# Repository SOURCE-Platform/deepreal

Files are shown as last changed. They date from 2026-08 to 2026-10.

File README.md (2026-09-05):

# DeepReal

**Open-source trusted sensing for private AI.** The first SOURCE reference device.

> **Status: architecture + hardware design in progress.** DeepReal is in active architecture, hardware-design, and prototype-planning work. Nothing here is production-ready, and no sensor configuration is final.

System architecture: [Source of Truth v0.2](docs/system-architecture/system-architecture.md)

Current physical concept and visual BOM:
[Blender reference model](docs/design/blender-reference-model.md)

Project page: https://sourceovcourse.com/deepreal

---

## What DeepReal is

DeepReal is an open-source desktop sensing device and reference architecture designed to give AI systems authenticated, privacy-preserving observations of the physical world around a computer. It combines multimodal sensing, hardware-rooted device trust, encrypted transport, protected host-side processing, and verifiable outputs — designed to remain inspectable and user-controlled.

It is the first reference implementation of **SOURCE**, a broader open architecture for connecting trusted devices and physical-world observations to digital and AI systems with stronger guarantees about origin, integrity, and privacy.

## Two sensing systems

DeepReal is not one general-purpose camera. It has two sensing systems, each aimed at a specific physical domain:

- **Face / presence sensing** — short-range RGB + structured-light depth. Captures the person at the computer (RGB imagery, facial geometry, depth) to support presence, liveness, and future identity-related research.
- **Interaction sensing** — wide-angle RGB aimed at the workspace. Observes hands, fingers on the keyboard, and mouse interaction to build stronger evidence that a real human produced a given computer action.

## Trust architecture (intended)

Two sensing paths converge into one trusted pipeline:

Physical world → face/presence + interaction sensing → **device trust boundary** (secure boot, hardware root of trust, secure element, device credentials, sequence-aware capture) → authenticated + encrypted device–host channel → **host trust boundary** (Trusted Execution Environment, protected processing, local AI, attestation/proof logic) → **verifiable output** (attestations, selective disclosure, provenance).

Later layers (attestation formats, provenance) are part of the design, not yet implemented.

## Hardware configurations (under evaluation)

DeepReal is being developed through several reference configurations that trade cost against assurance. These are engineering configurations, not products for sale, and carry no prices here.

| Config | Face sensing | Interaction sensing | Research question |
|---|---|---|---|
| A — Cost optimized (baseline) | RGB + depth | Rolling-shutter RGB | Can a cost-optimized system reliably observe physical interaction? |
| B — Motion optimized | RGB + depth | Global-shutter RGB | Does cleaner fast-motion capture materially improve verification? |
| C — Full 3D interaction | RGB + depth | RGB + depth | Does 3D interaction geometry give substantially stronger evidence? |
| C+ — Full 3D + motion | RGB + depth | Global shutter + depth | What is achievable with maximum interaction evidence? |

## Prototype → production

Today's off-the-shelf modules are experimental instruments, not permanent dependencies:

Off-the-shelf modules → validate requirements → measure what actually helps → custom open reference hardware.

## Candidate components

Parts are candidates under evaluation, **not** final production specifications:

- **Face / depth module — Orbbec Astra Mini S Pro** *(prototype candidate).* Its short-range operating envelope suits someone sitting at a laptop. Final facial-identity performance must still be tested.
- **Secure-boot-capable MCU** *(under evaluation)*
- **Discrete secure element / hardware root of trust** *(under evaluation)*
- **Common architecture:** USB-C power and data, one microphone, device cryptographic identity, common PCB / interface architecture, authenticated communication with the host.

## Privacy by architecture

The design asks not only what *can* be sensed but what actually *needs* to be sensed — minimizing hardware sensing capability alongside retention and disclosure. Intended properties, under development: local / host-side processing, cloud inference not required, encrypted device–host link, data minimization, selective disclosure, user-controlled retention, and attestations that can expose less information than raw sensor streams. These are design goals, not finished guarantees.

## Roadmap

Discrete statuses — no completion percentages.

1. System architecture — **Current**
2. Mechanical + sensing design — **Current**
3. Sensor configuration evaluation — **Next**
4. Prototype electronics — **Next**
5. Trusted sensor pipeline — **Planned**
6. Protected host processing — **Planned**
7. Production reference architecture — **Planned**
8. SOURCE reference implementation — **Planned**

## Relationship to SOURCE

DeepReal provides the physical sensing endpoint; SOURCE is the broader open protocol and trust architecture (attestation + provenance) that applications and AI agents build on. The goal is an open architecture others can implement — future SOURCE-compatible hardware need not be built by the DeepReal project.

## Repository layout

```
deepreal/
├── blender/      # current design authority, generated scene and render tools
├── docs/         # architecture, visual BOM and research notes
├── references/   # retained component datasheets and vendor geometry
└── README.md
```

FreeCAD is not part of the active workflow. A future manufacturing-CAD phase
will reconstruct the selected Blender concept with tolerances and production
features after the component and validation gates are closed.

## Contributing

DeepReal is developed in the open. We are interested in collaboration around open hardware, embedded security, confidential computing, privacy-preserving AI, cryptography, and trustworthy sensing.

To get involved, open an issue or see the [project page](https://sourceovcourse.com/deepreal).

## License

Open-source licensing under final review.

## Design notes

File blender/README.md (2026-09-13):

# DeepReal Blender reference model

Blender contains the mechanical concept and presentation scenes. KiCad is the
authority for the main PCB footprint placement and copper geometry.
The canonical design is one curved 120 mm-wide assembly; the obsolete
"Current" collision study and boxy "Compact" comparison are no longer part of
the build. FreeCAD is not required.

The electronics are an incomplete engineering rebuild, **not approved for
website use**. The native KiCad import preserves the current placement defects;
it does not make the footprint selections, circuits or layout correct. The two
rotating head-board designs and flex interfaces remain unresolved concepts.
This model must not be used to manufacture or certify hardware.

See [the current implementation checkpoint](../docs/electrical/native-pcba-import-checkpoint.md)
for measured progress, reproducible commands and remaining blockers.

## Source files

- `design_spec.py` — Blender-native dimensions and the approved curved housing
  profile.
- `device.py` — hollow curved enclosure, drum and motor pockets, bounded side
  cable passages, and two cylindrical 24 × 54 mm drum shells.
- `optics.py` — bored apertures plus architecture-stage RGB, IR, projector,
  carrier, PCB, and optical keep-out geometry.
- `electronics.py` — native main-PCB import, concept shield and thermal stack.
  The missing KiCad tamper switch is no longer silently added in Blender.
- `motion.py` — two offset gearmotors, pinions, ring gears, axles, four
  bearings, encoder boards/magnets, brackets, and travel stops. Each ring gear
  occupies the final 2 mm drum-end band, clear of the outer camera window.
- `interconnect.py` — two combined 51-conductor optical-head flex routes;
  projector drivers and pulse loops remain local to the rotating heads.
- `support_hardware.py` — removable PCBA mounts, bearing carriers, grounded
  cable channels, boundary clamps, and strain relief.
- `presentation_views.py` and `pcba_presentation.py` — full-device views plus
  five dedicated PCBA scenes made from linked canonical geometry.
- `pcba_bom.py` — presentation names and explicitly representative envelopes
  for 18 missing native chip models; not an independent placement authority.
- `pcba_kicad_data.py` and `pcba_native_import.py` — hash-checked JSON/GLB
  interface from KiCad, including native components, pads, mask and holes.
- `mounting_stack.py`, `usb_port.py`, `usb_cable.py` — display attachment and
  external connection concepts.
- `build_scene.py` — deterministic complete-scene build.
- `validate_model.py` — legacy assembly checks; still fails missing required
  hardware and does not approve electronics.
- `validate_pcba.py`, `validate_pcba_native.py`, `test_pcba_native.py` — geometry
  transport and provenance checks, explicitly separate from engineering approval.
- `render_native_review.py` — six stamped internal review images; no publication.
- `review_renders.py` — legacy general-device review views, not a release gate.
- `render_pcba_public.py` — gated public packaging; currently refuses release.
- `deepreal.blend` and `renders/` — generated outputs; rebuild rather than
  treating manual edits as authoritative.

Handmade copper, decorative vias, fake connector-apron boards and the separate
Blender support-population generator are no longer active. Removed source is
recoverable from Git history. No traces have been invented to fill this board.

## Build and validate

From the repository root:

```sh
# Refresh the JSON and native GLB first; see the checkpoint for KiCad commands.
/Applications/Blender.app/Contents/MacOS/Blender --background \
  --factory-startup --python-exit-code 1 --python blender/build_scene.py

/Applications/Blender.app/Contents/MacOS/Blender --background \
  blender/deepreal.blend --python-exit-code 1 --python blender/validate_pcba.py

/Applications/Blender.app/Contents/MacOS/Blender --background \
  blender/deepreal.blend --python-exit-code 1 --python blender/test_pcba_native.py
```

The build uses millimetres in source and converts to Blender metres. Product
X runs across the display, Y runs front-to-back, and Z runs vertically.

## Enclosure and shielding decisions

- The electronics compartment follows the approved curved/tapered lower
  profile instead of a rectangular chin.
- The housing contains real drum, motor, electronics, and side-route cavities.
- A two-piece shield concept surrounds the main board. Actual connector,
  component, thermal-contact and tolerance clearances remain open.
- The head interfaces are two candidate combined flex connectors plus two
  motor/encoder interfaces. Their native placement currently overhangs the
  board incorrectly; no grounded connector apron has been implemented.
- Side cable passages are closely bounded, and data and power/motion routes
  remain in separate fitted channels.
- A separate copper spreader and compliant pad show the intended heat path
  from the rear tray into the rear housing surface. The spreader and pad sit
  behind the enclosure rather than inside the protected electronics chamber.

## Presentation scenes and navigation

The generated `.blend` opens to **00 Four View Overview**, where all four
versions are arranged together and labeled. You do not need to know Blender's
navigation to find them. For a larger individual view, use the scene selector
in the upper-right corner of Blender and choose a numbered detail
scenes. The canonical source scene is also retained for modeling work.

Presentation objects are linked duplicates: they have independent positions
for composition, but share the source mesh or curve datablock. Geometry is
modeled once and updates in every view.

0. **00 Four View Overview** — all four labeled arrangements on one canvas.
1. **01 Fully Assembled** — complete enclosed DeepReal hardware.
2. **02 Housing Removed** — enclosure and drum shells removed; mounting
   brackets, carriers, and standoffs remain. The enclosure-mounted USB-C
   receptacle and external cable are removed with the housing.
3. **03 Functional Core** — the same internals with removable support hardware
   omitted.
4. **04 Electronics Exploded** — the PCBA, tray, lid, components, thermal
   stack, connector banks, routes, and supports separated for inspection.
5. **05 Shield Cutaway** — the front lid removed to expose the shield
   boundary, populated field, connector apron, and cable passages.
6. **06 PCBA Top** — orthographic top/front assembly view.
7. **07 PCBA Bottom** — orthographic bottom/rear assembly view.
8. **08 PCBA Dimensioned** — board and populated-stack dimensions.
9. **09 PCBA Identification** — top/bottom reference-designator index.
10. **10 Camera Flex Study** — current two-connector drum interface beside the
    four-camera-flex signal-integrity fallback.

## What remains open

The model includes every architecture-level BOM function, but many items are
still reference envelopes. Production work still needs selected lenses,
projector and eye-safety hardware, final PCB layout, confirmed motor and
bearing parts, fastening/sealing details, flex fatigue data, thermal testing,
EMC testing, mass/hinge testing, and tolerance-driven CAD. Those unresolved
items are visible in the model and documentation rather than silently treated
as finished engineering.

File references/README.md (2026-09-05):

# Component references

Manufacturer datasheets and selected vendor geometry retained from earlier
feasibility research live here. They are evidence inputs, not the active
mechanical design. Blender remains the current geometry authority, and each
candidate must be rechecked before schematic or manufacturing freeze.

- `components/datasheets/` contains manufacturer documents and drawings.
- `components/cad/` contains selected vendor STEP/ZIP reference geometry.

The old project-authored FreeCAD models and scripts were intentionally removed.
Later production CAD should be reconstructed from the reviewed Blender concept
and verified component selections, not revived from the obsolete design.

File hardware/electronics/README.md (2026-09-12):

# DeepReal Electronics Design Source

This directory is the controlled handoff between the system architecture, future
EDA capture, PCB layout and Blender packaging model.

## Designs

- `deepreal-main-pcba/` - stationary 90 x 28 mm compute, power, camera bridge,
  USB and motor-control board.
- `deepreal-optical-head/` - one rotating RGB/IR/projector carrier design. The
  identical design is populated twice, once for each drum.

## What exists now

The files define the sheet hierarchy, component/reference-designator ownership,
named power and signal nets, drum-connector allocation, circuit intent and the
vendor pin maps that must be imported before an ERC-clean EDA schematic can be
claimed. KiCad 10 is installed and the main-board directory contains a navigable
15-page hierarchy plus a real 90 x 28 mm placement study. Several authoritative
BGA pin maps are still not stored locally.

This is electrical design source, but it is **not yet** a completed circuit
schematic, routed netlist or manufacturing package. `TBD_PINMAP` is an explicit
gate, never a guessed connection.

## Release rule

Blender geometry may use the component packages and support-population counts in
this directory. The separately named KiCad/Blender presentation derivative may use
shared illustrative copper labelled `ILLUSTRATIVE COPPER - NOT ELECTRICALLY
ROUTED`. The canonical KiCad board must remain free of decorative copper.

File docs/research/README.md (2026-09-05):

# Retained research

This directory separates historical evidence from the current design baseline.

- `component-sources-legacy.md` preserves vendor-source findings.
- `drum-internals-feasibility-legacy.md` preserves the earlier geometry study
  and clearly marks its removed FreeCAD dependencies.
- `legacy-layouts/` contains the study's generated diagrams.
- `DeepReal_System_Architecture_v0.1_historical.docx` is retained only as the
  superseded Word snapshot; v0.2 in `docs/system-architecture/` is current.

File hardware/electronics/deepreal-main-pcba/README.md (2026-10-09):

# DeepReal Main PCBA Electrical Capture v0.2

| Field | Value |
| --- | --- |
| Board | Main PCBA |
| Target outline | 90 x 28 x 1.6 mm |
| Assembly | Two-sided, 10-layer HDI working assumption |
| KiCad | 10.0.6 project created and verified |
| Schematic | 15-page hierarchy and page contracts; circuits not yet captured |
| PCB | 90 x 28 mm, 10-layer preliminary placement; canonical board has no routed copper |
| Public visualization | Not generated; publication paused |
| Status | Engineering rebuild in progress; electrical capture and routing not complete |
| Architecture baseline | `../../../docs/electrical/main-pcba-schematic-entry-spec-v0.1.md` |

The active rebuild plan is
`../../../docs/electrical/main-pcba-engineering-review-plan-v0.1.md`; requirements
v0.2 and `design-status.json` supersede older release and FPGA assumptions.

For the plain-language status, solved issues, blockers and next steps, see
[PCB progress, 14 September](../../../docs/electrical/pcb-progress-2026-09-14.md).

## Current KiCad artifacts

- `deepreal-main-pcba.kicad_pro` - KiCad project settings.
- `deepreal-main-pcba.kicad_sch` plus pages `02` through `15` - navigable
  schematic hierarchy. Each page states its references and closure gate.
- `deepreal-main-pcba-capture-map.pdf` - verified 15-page review export.
- `deepreal-main-pcba.kicad_pcb` - canonical engineering board. Its present
  contents are the inherited placement study, but future placement and copper
  edits originate only in KiCad.
- `design-status.json` - authoritative gate state and release permissions.
- `component-evidence.csv` - exact-source and footprint audit register.
- `source-evidence-register.csv` - versioned official-source locations and the
  specific gate each source can close.
- `change-register.csv` - architecture and geometry changes plus required reruns.
- `preliminary-stackup.json` - unapproved ten-layer intent model with every
  fabricator-dependent field left explicitly open.
- `engineering-layout-export.json` - canonical geometry and pad/copper export for
  Blender; the current baseline contains 238 components and 2,313 pads but no
  routing.
- `engineering-review-manifest.json` - generated evidence, blocker, and release
  inventory for the current review checkpoint.
- `public-assets.json` - publication lock and the names reserved for future
  KiCad-derived output. No current PCBA image is approved for publication.
- `scripts/generate_schematic_hierarchy.py` - deterministic hierarchy generator.
- `scripts/export_kicad_design.py` - exports canonical KiCad geometry for Blender.
- `scripts/validate_design_gates.py` and the other validators - enforce release,
  evidence, completeness, bandwidth, and no-fabrication rules.

The inherited placement contains 238 footprints: most registered major packages,
U21/U22, six camera-interface ESD arrays, nine power-inductor envelopes, 144
capacitor proxies, and 44 resistor proxies. SW1 is registered but missing from the
KiCad board. Several other footprints are known substitutes. Unconnected support
parts are space claims, not finished circuit values.

## Capture sequence

1. Import manufacturer symbols and footprints listed in `pinmap-gates.csv`.
2. Capture pages 2-4 and 13-15 from `circuit-specification.md` first.
3. Apply the net names and ownership in `net-registry.csv`.
4. Capture pages 5-12 after their vendor/tool gates close.
5. Annotate, run ERC and export an independently reviewed PDF and netlist.
6. Perform the Lattice pin compile and NXP DDR-tool pass before placement is
   treated as routeable.

Regenerate the hierarchy with:

```sh
python3 scripts/generate_schematic_hierarchy.py
```

The superseded visual board, handmade trace contract, generators, and renders were
removed from the working tree. Git history is the historical record. Future Blender
geometry must come from the canonical routed KiCad review draft instead.

The active Blender build imports KiCad's native GLB through
`../../../blender/pcba_native_import.py`, with a hash-checked JSON inventory.
`../../../blender/pcba_bom.py` supplies presentation names and flagged body
envelopes for missing 3D models, never fallback placement or invented pads.
The native board remains unrouted and its footprint selections are unverified.
See [the import checkpoint](../../../docs/electrical/native-pcba-import-checkpoint.md)
for reproduction commands and the current internal-review asset inventory.

The [two-drum interface checkpoint](../../../docs/electrical/head-interface-checkpoint-2026-09-14.md)
records official connector dimensions, read-only rotation trials, the head current
screen and remaining flex/head-board work. `head-interface-evidence.json` pins the
manufacturer catalog and lists open closure evidence. Run
`python3 scripts/validate_flex_interface.py` for an honest audit, or add
`--require-ready` to reject the currently unapproved interface. The comparison
image is an internal diagnostic, not an approved replacement layout.

`scripts/audit_head_power.py` checks the partial sensor power evidence and matching
IR clock contracts. It rejects the old shared 24 MHz assumption; the Mira220
reference is 38.4 MHz. Clock circuitry and complete head power remain open.

Public rendering is intentionally blocked until `public_visual_allowed` becomes
true after the engineering and visual gates pass. At that future point, rebuild with:

```sh
/Applications/Blender.app/Contents/MacOS/Blender --background \
  blender/deepreal.blend --python-exit-code 1 --python blender/render_pcba_public.py
```

## Non-negotiable rules

- U1 and U4 package bodies cannot touch; keep a physical assembly gap and preserve
  an unobstructed DDR corridor.
- Under the inherited two-FPGA candidate, U2 serves J2 and U3 serves J3, each with
  its associated i.MX95 CSI receiver. This is not a locked architecture: G3 must
  decide zero/one/two FPGAs before final placement and routing.
- Projector pulse drivers are not on this board. They are on the optical heads.
- `HEAD_*_3V3` is filtered and independently switchable for each head.
- `MOTOR_6V` remains disabled unless the accepted USB-PD contract is at least 9 V.
- Every projector-enable path is hardware-default-off and interrupted by the local
  lens-integrity loop.
- No PCBA image may be used for new marketing or investor materials until the
  replacement passes G11. Its caption is controlled by `public-assets.json`.

## Current completion definition

This package preserves the KiCad project structure and preliminary placement while
the engineering review draft is rebuilt. It does not close circuit or manufacturing
routing work.
Pin-level closure remains blocked where the official i.MX95, LPDDR4X, eMMC or FPGA
package data has not been imported and verified. See `pinmap-gates.csv` for the
exact blockers.

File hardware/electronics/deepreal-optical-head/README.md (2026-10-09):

# DeepReal Optical Head Electrical Capture v0.1

| Field | Value |
| --- | --- |
| Design | One reusable rotating optical-head carrier |
| Product quantity | 2 identical assemblies |
| Contains | RGB sensor assembly, IR sensor, projector, driver, local rails and safety interlock |
| Status | Capture source; optical, flex, safety and exact regulator selections open |

The two drums do not use two independently designed head PCBs. H1 and H2 are the
same controlled design populated twice, with identity/configuration selecting face
or interaction use. This reduces layout, firmware and test divergence.
The current RGB optical target populates standard SA31VA30P in the face head and
wide SA36VA30P in the interaction head. One shared carrier is still an objective,
subject to verifying both variants' mating connector, pinout, autofocus load and
the larger interaction lens clearance before schematic/layout freeze.

This is the intended partition, not an existing completed pair of PCBs. No native
KiCad head schematic or board has been captured yet. Main-board J2 goes to the
face head's J1; J3 goes to the interaction head's J1. See the
[two-drum interface checkpoint](../../../docs/electrical/head-interface-checkpoint-2026-09-14.md)
for connector dimensions, placement conflicts, power and dynamic-flex blockers.

`power-clock-evidence.json` records the inspected Mira220 clock, rail peaks and
startup requirements without claiming a complete head budget. Run the main-board
`scripts/audit_head_power.py` for source and clock-contract consistency checks.

## Electrical partition

The head receives filtered/switched 3.3 V, MCLKs, control and triggers over the
51-contact dynamic flex. RGB and IR each return two-lane CSI-2. The AS1170,
Belago1.2 and projector pulse capacitor stay local so the 700 mA-class pulse loop
does not traverse the rotating flex.

## Safety rule

`PROJECTOR_ENABLE` is necessary but not sufficient for emission. The driver must
also see a valid local lens-integrity loop, valid local power and no thermal/fault
condition. Removal of power, an open flex or an open Sense1/Sense2 loop defaults to
off. This is a design intent pending the required system-level eye-safety assessment.

## Closure order

1. Freeze the RGB assembly and Mira220 orientation from the optical baseline.
2. Select and calculate the RGB and IR local regulators.
3. Capture the manufacturer reference circuits and full sensor pin maps.
4. Freeze the 51-contact flex numbering and dynamic-flex stack-up.
5. Run ERC, power-up sequencing review and projector single-fault review.
6. In a separately authorized future fabrication program, prototype one head and
   measure rails, timing, thermal behavior and optical output. No fabrication is
   authorized by this digital-review phase.

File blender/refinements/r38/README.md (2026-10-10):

# R38 exterior mount and cable appearance

R38 starts from R36, preserving its drums, supports, and exposed-top
silhouette. The narrow R30 40 × 13 mm housing-colored pad is absorbed into a
continuous inner enclosure leg, extended to Y = 3.5 mm across the device.
A distinct satin-metal **112 × 26 mm** device-side magnetic face, centered at
Z = −14 mm, sits directly on that leg. It matches the R32 laptop-side target
plate in width, height and position. There is no separate mount riser. The
provisional 0.9 mm face, 0.35 mm air gap, 0.35 mm laptop plate and 0.40 mm
tape keep the R30 nominal mount plane; the ledge depth is now 5.0 mm at its
inner leg rather than 7.0 mm.

The USB cable's visual outer diameter changes from 4.0 to 3.2 mm. The plug
has a longer hard molded handle with a rounded V-taper, a subtle vertical
DeepReal wordmark, then a **distinct, straight-sided sleeve**
over the cable jacket. The sleeve reads as a separate piece rather than the
entire handle narrowing to cable diameter. The website viewer fades the free
end; the Blender cable itself has no physical fade.

Neither the sleeve's retention/bend performance, cable specification nor
magnetic force, material, embedding, adhesive, hinge load, enclosure
wall/volume changes, tolerances and laptop fit have been validated. The
magnetic face has a dark satin finish for visual distinction; that finish
does not establish the magnet's physical material or construction.

Build and export from the DeepReal repository root:

```sh
blender -b -t 4 --python-exit-code 1 --python blender/refinements/r38/build_r38.py
blender -b -t 4 --python-exit-code 1 --python blender/refinements/r38/render_plug_r38.py
blender -b -t 4 blender/refinements/r38/deepreal-exterior-mount-r38.blend \
  --python-exit-code 1 --python blender/export_web_exterior.py
```

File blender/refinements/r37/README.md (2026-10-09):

# R37 rear cable space reservation

R37 continues the [R36 inner-bearing study](../r36/README.md). The orange
volume in the [internal view](r37-rear-volume-internal.png) is a possible
passage through the center divider. The cyan volume is a possible chamber
inside the rear enclosure. They are **space reservations**, not cavities,
cable solids, or a working cable route. The public exterior is unchanged.

The passage spans X −0.8 to 1.2 mm, Y −1.7 to 13.25 mm, and Z 11.5 to
28.5 mm. The chamber spans X −26 to −0.2 mm, Y 13 to 20 mm, and Z 10.5 to
28.5 mm. These sizes test where room might exist; they are not bend-radius
requirements or approved wall dimensions.

## Finding

The passage crosses the current fixed **rear bearing support web** (four
surface triangle contacts). All 27 interior points sampled in the passage
are inside the solid R30 visual enclosure. In the rear chamber, 26 of 27
sampled points are also inside the solid enclosure. The remaining point,
at X −13.1, Y 18.6, Z 24.9 mm, lies outside the curved rear skin; a
rectangular cut there would break through the exterior. The test found no
contacts with the optical carrier, motor, or drums at the straight-ahead
pose. This is an occupancy study; a surface-only collision test would have
missed a volume fully contained by the shell.

The R36 moving cable exits along X with its 15.6 mm mating-end width along
Z. Sending it toward the rear (+Y) would require an **edgewise turn** of
that flat strip. Simply hollowing the indicated chamber does not make a
working dynamic cable. The fixed bearing web would also lose its present
attachment if the passage were cut as drawn. A replacement bearing load
path, a realizable flex orientation and loop, and a fixed electrical
termination need to be designed together before altering the enclosure.

There is a size problem as well. Würth Elektronik's
[dynamic-flex application example](https://www.we-online.com/files/pdf1/webinar-rigidflex-flexibility-cbt-en.pdf)
lists an inside bend radius **greater than 12 mm** for its roughly 120 µm,
single-layer flex. A 180° return at that radius needs over 24 mm across.
This proposed chamber is only 7 mm deep (Y) and 18 mm high (Z). It therefore
cannot house that example loop in either of those directions. This is a
supplier illustration, not a selected DeepReal stack or a universal limit;
the actual motion and cable vendor must determine the necessary space.

Würth Elektronik's [Flex Solutions design guide](https://www.we-online.com/files/pdf1/design-guide-flex-solutions-cbt-en.pdf)
calls for specifying the actual dynamic stack, bend shape, radius, frequency,
and cycle count early in the mechanical/electrical design. Its guide also
notes that dynamic flex often favors a single layer in the bending area.
That guidance is a reason to involve the cable fabricator, not a validation
of this reservation. The 0.2 mm in the R36 straight visualization is not a
validated dynamic stack thickness.

## Next design action

Redesign the moving cable and inner bearing support as one module. Compare
a loop that bends across the flex's thin dimension with alternative
head-board/connector locations, then screen the full face-drum −45° to +45°
sweep. Only after a route clears the optical carrier, motor, supports,
enclosure and both drum end rings should the chamber be cut into the shell.
Check the interaction drum separately with its own travel limits. Vendor
review must establish flex stack, impedance, strain relief and cycle life.

## Reproduce

```sh
blender -b -t 4 --python blender/refinements/r37/study_r37.py
```

Outputs: editable `deepreal-rear-cable-volume-r37.blend`, internal view,
and `r37-volume-check.json` with bounds and occupancy results.

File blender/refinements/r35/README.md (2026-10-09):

# R35 face-drum motion feasibility study

R35 follows [R34](../r34/README.md). It studies the two remaining face-drum
interfaces: how the outer axle reaches the drum wall, and how a moving optical
cable might reach the fixed center divider. This is **not** a release model.

The [R36 study](../r36/README.md) replaces the obstructing fixed-bearing tabs
with an axial neck and side supports. Its straight cable segment clears the
sampled poses; the moving service loop is still open.

## Outer end: a geometric load path exists

The new rotating disk/web overlaps the shaft, the rotating hub and a thin
sleeve at the drum sidewall. The sleeve also overlaps the rotating drum shell.
Together these envelopes show a continuous *intended* load path from drum wall
to shaft, while the stationary bearing stays separate. The sweep script finds
zero triangle intersections between these rotating envelopes and the fixed
bearing or enclosure at the rest pose. The web has only 0.3 mm **nominal axial**
space to the fixed bearing. That is a packaging observation, not a tolerance
or strength allowance. Separate meshes deliberately overlap where joints
would be needed; fits, fasteners, bearing retention and loads remain unproven.

## Inner end: the full-width twist route fails this layout

The red ribbon represents the existing 15.6 mm connector-end width at 0.2 mm
illustrative thickness. It twists from a rotating anchor to a fixed anchor.
`check_r35.py` tests four moving-anchor positions and two fixed-anchor
positions at 5° increments over −45° to +45°. **None of the eight candidate
routes clears the modeled parts.**

- The R21 upper/lower fixed-bearing webs and tabs intersect the ribbon at
  every pose, even when the fixed end stops before the enclosure.
- When the fixed end reaches into the center divider, the current enclosure
  intersects the ribbon at every pose; no fixed cable opening exists there.
- Longer torsion spans cross the moving optical carrier and, at some angles,
  the RGB or projector body. Shortening the span reduces those collisions but
  leaves the fixed support conflict and offers very little length for twist.

This corrects an easy overreading of R34: its 0.65 mm figure measured the
straight strip *inside the circular bearing opening*. R34 did not demonstrate
a routed moving cable past the bearing supports, optical payload and divider.
The R35 collision study does not prove every possible flex geometry fails; it
shows that a simple full-width axial twist cannot be dropped into this layout.
No bend-radius, copper-strain or life model has been claimed.

## Review artifacts

- `deepreal-face-motion-study-r35.blend`: editable study, with the failed
  cable candidate visibly red.
- `r35-outer-load-path.png`: isolated rotating web, hub, shaft and bearing.
- `r35-flex-center-conflict.png` and `r35-flex-up45-conflict.png`: internal
  conflict views. The drum shell is hidden so the contacts are visible.
- `r35-motion-check.json`: all sampled triangle-intersection results.
- `r35-motion-manifest.json`: objects and provisional anchor locations.

Regenerate from the repository root with Blender 5.2:

```sh
blender -b -t 4 --python blender/refinements/r35/build_r35.py
blender -b -t 4 --python blender/refinements/r35/check_r35.py
blender -b -t 4 --python blender/refinements/r35/render_r35.py
```

## Next design pass

1. Rebuild the fixed inner-bearing supports around an intentional cable
   window and add a protected path through the center divider.
2. Change the moving cable architecture or optical-carrier layout so the
   required contacts can traverse that window through the full face-drum
   travel. Candidate directions include a split harness from the head PCBA
   or a packaged flex loop; neither has been validated yet.
3. Re-sweep the exact new cable envelope, then check termination, minimum
   bend radius, strain relief, signal integrity and cycle life.
4. Turn the outer web overlaps into a specified rotating joint with selected
   bearing, loads, fastening and tolerances.

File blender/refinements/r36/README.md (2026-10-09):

# R36 inner-bearing cable window study

R36 continues the [R35 motion study](../r35/README.md). It keeps the exposed
drum exterior and the R35 outer-shaft web. This revision changes only the
**face drum's fixed inner-bearing support**; the interaction drum is unchanged.

## What changed

The R21 upper and lower bearing tabs crossed a full-width cable even at the
straight-ahead pose. R36 replaces them with a thin fixed **axial neck** that
extends toward the center divider beyond the rotating inner lip. Two short
side webs connect that neck to the enclosure from the left and right of the
cable opening. The moving straight strip remains 15.6 mm wide, matching the
documented connector-end width.

The R36 model's sampled −45° to +45° face-drum sweep, every 5°, records:

- Intended mesh contacts from each side web to the axial neck and enclosure,
  and from the neck to the fixed bearing envelope.
- Zero mesh intersections of the new fixed supports with the rotating inner
  race, rotating lip or drum shell.
- Zero mesh intersections of the **straight** full-width exit segment with
  the modeled bearing, supports, motor, housing, drum shell and optical
  carriers at those sampled poses.

The neck's nominal outer radius is 8.9 mm, while the rotating lip's nominal
inner radius is 9.15 mm: just 0.25 mm radial space before tolerances. The
flex's corner radius is about 7.8 mm inside an 8.45 mm bore. These are
packaging measurements, not bearing or cable clearances approved for manufacture.

## What still blocks a moving cable

The straight strip stops before it connects to a fixed harness. The R35
full-width axial-twist route still crosses the optical carrier. As a separate
screen, `probe_r36.py` tested 6–8 mm trunk widths at three moving-anchor
positions. `probe_offset_r36.py` tested 6 and 7 mm trunks with up to 3 mm of
offset toward the motor. **None of these simple twist routes was collision
free.** Width reduction cleared the old bearing tabs, but did not resolve the
carrier conflict; moving the strip toward the motor traded carrier contacts
for motor contacts. `map_conflict_r36.py` localizes representative contacts
along the inner optical carrier rather than assuming a small end relief would
fix them.

The 15.6 mm number is the **mating end width** of the 51-contact connector.
It does not approve a narrower dynamic trunk, a multilayer flex, split tails
or changes to the six differential-pair routes. Those need a real electrical
stack-up and signal-integrity review before selection.

The next mechanical study should reserve a service-loop chamber outside the
current optical-carrier and motor envelopes, with a protected route through
the fixed center divider. It must retain bearing support and the visible
exterior. Then a cable vendor or electrical designer must validate bend
radius, copper strain, terminations, impedance and cycle life.

## Files and reproduction

- `deepreal-inner-bearing-window-r36.blend`: editable support study.
- `r36-bearing-window-end.png` and `r36-bearing-window-side.png`: internal
  support views with the drum skin hidden.
- `r36-support-check.json`: sampled fixed/moving geometry checks.
- `r36-width-screen.json` and `r36-offset-screen.json`: exploratory moving
  cable screens against the unchanged R35 carrier and motor layout.
- `r36-support-manifest.json`: changed objects and remaining open work.

Run from the repository root with Blender 5.2:

```sh
blender -b -t 4 --python blender/refinements/r36/probe_r36.py
blender -b -t 4 --python blender/refinements/r36/probe_offset_r36.py
blender -b -t 4 --python blender/refinements/r36/map_conflict_r36.py
blender -b -t 4 --python blender/refinements/r36/build_r36.py
blender -b -t 4 --python blender/refinements/r36/check_r36.py
blender -b -t 4 --python blender/refinements/r36/render_r36.py
```

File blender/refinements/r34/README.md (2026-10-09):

# R34 face-drum interface study

This Blender revision tests one packaging direction against the R30 exterior:
a centered angle encoder at the **outer cheek** and an optical flex exit through
the **inner bearing**. It changes only the face drum. The interaction drum
retains its R30/R21 interface.

The [R35 motion study](../r35/README.md) extends this check and finds that a
full-width moving twist collides with the existing bearing supports and optical
carrier. Treat the straight-aperture result below as a limited check.

## Files

- `deepreal-face-interface-study-r34.blend` is the editable assembly study.
- `r34-mechanism-study.png`, `r34-outer-encoder-detail.png` and
  `r34-inner-flex-detail.png` are internal review views. The enclosure and
  drum skin are hidden in these views to reveal the interfaces.
- `r34-interface-manifest.json` records the placed envelopes and open items.
- `r34-interface-check.json` records the current geometric sweep.
- `build_r34.py`, `check_r34.py` and `render_r34.py` reproduce those artifacts
  from the R30 model using Blender 5.2.

Run the scripts in build, check, render order from the repository root:

```sh
blender -b -t 4 --python blender/refinements/r34/build_r34.py
blender -b -t 4 --python blender/refinements/r34/check_r34.py
blender -b -t 4 --python blender/refinements/r34/render_r34.py
```

## What this pass establishes

The moving magnet and stationary sensor-package proxies share the face-drum
axis. Their modeled axial surface gap is 0.55 mm. The sensor board sits in an
internal pocket in the fixed outer cheek; the exterior cheek remains skinned.
The magnet is a Ø6 × 2.5 mm **reference envelope**, not a selected magnet.
The [AS5600L adapter-board guide](https://look.ams-osram.com/m/b03a90ea3dea434a/original/AS5600L_UG000345_2-00.pdf)
gives 0.5–3 mm for its reference magnet setup;
field strength, datum and errors for this assembly have not been measured.

The inner flex strip uses the documented 15.6 mm connector-end width from
`head-interface-evidence.json`. A clearance slot is cut through the inherited
solid drum cap. At sampled face-drum angles from −45° to +45° in 5° steps,
the straight strip has zero triangle intersections with the fixed inner bearing,
motor, motor bracket, housing and drum shell. At zero it also has zero triangle
intersections with the modeled optical carrier, head PCBA carrier, RGB/IR/
projector bodies and rotating inner bearing. The strip's maximum corner radius
is 7.80 mm against an 8.45 mm fixed-bearing opening radius: approximately
0.65 mm **nominal radial** margin. This is a geometry check, with no tolerance
or manufacturing allowance.

## Open before the mechanism can be released

1. Design and sweep the **deforming flex service loop** between the rotating
   head and fixed divider; select flex construction, end terminations, strain
   relief, minimum bend radius and cycle-life target. The current strip ends
   before that transition.
2. Connect the outer rotating shaft structurally to the rotating hub and drum.
   The bearing, shaft and hub are envelopes, with no load or fastener design.
3. Redesign the outer cheek pocket with a validated wall and board mount. The
   study leaves a very thin outer skin solely to preserve exterior appearance.
4. Validate the magnet, sensor datum, polarity, air gap across tolerances,
   motor-field interference and stationary electrical harness.
5. Reconcile the second drum, motor drive, hard stops and assembly sequence.

The present `straight_envelope_pass` field describes only the tested straight
segment and static overlaps. It does not indicate that a moving cable or
manufacturable bearing assembly passes.

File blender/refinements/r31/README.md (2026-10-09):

# R31 decorative laptop target plate

Open `deepreal-logo-mount-plate-review-r31.blend`. Its saved camera faces the
back of the laptop lid, with DeepReal removed so the plate and logo are visible.
The existing R30 device and enclosure files are unchanged.

The visual study uses the supplied `assets/deepreal-logo-v0.svg` on a 110 × 16 mm
steel target near the lid's top edge. A separate 106 × 14 × 0.4 mm foam sticker
sits between the plate and the 3 mm laptop-lid proxy. The steel target is shown
as 0.35 mm thick to match the earlier provisional mounting stack. Its grade,
thickness, attachment strength, and laptop fit remain unverified.

The logo is a dark laser-mark appearance made from the SVG curves. It is **not**
a fabrication-ready engraved or debossed cut: physical recess depth and minimum
line width need a manufacturing sample. A 430 ferritic stainless finish is a
material candidate, represented here by a satin steel shader.

- `r31-laptop-back.png`: saved rear-view camera and overall placement.
- `r31-full-width-plate.png`: closer view of the plate across the attachment zone.
- `r31-logo-and-foam-detail.png`: angled logo and plate-edge view.
- `r31-attachment-layers-exploded.png`: illustration with the plate lifted from
  the foam sticker; this is a render pose, not the assembled file state.
- `build_mount_plate.py`: repeatable Blender build and render script.

This file reviews the laptop-side target only. The R30 device-side 40 mm magnet
pad has not yet been updated to match the wider attachment concept.

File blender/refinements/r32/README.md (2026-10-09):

# DeepReal pressed logo target plate — R32

This separate Blender appearance study replaces the R31 dark surface mark
with actual shallow relief on a taller laptop-side magnetic target plate.

- Plate: 112 × 26 × 0.35 mm, centered at z = −14 mm below the laptop top.
- Foam sticker: 109 × 23 × 0.4 mm. The original R30 device-side magnet pad
  remains its earlier size; magnetic holding force has not been checked here.
- Artwork: original DeepReal SVG sampled to 103 mm wide. Each logo line is
  the bottom of a 0.15 mm deep trough with a 0.95 mm smooth shoulder.
- The plate back remains flat in this visual model. Material forming, tooling,
  local thickness, adhesive stack, and pull force require a physical prototype.

Build with:

```sh
/opt/homebrew/bin/blender -b --python blender/refinements/r32/build_pressed_plate.py
```

The saved file opens on the plate detail camera. The PNG renders show the
larger plate on a laptop lid and the light/shadow behavior of the logo.

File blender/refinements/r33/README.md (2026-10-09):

# DeepReal creased press profile — R33

This is the requested profile revision of the R32 laptop target plate. The
plate and logo dimensions remain 112 × 26 mm and 103 mm wide, respectively.
The 0.15 mm pressed depth and 0.95 mm shoulder radius also remain the same.

The logo line is now a narrow crease at the deepest point. The shoulder
curves return smoothly to the original plate height. The R32 rounded-bottom
comparison is preserved in its own `.blend` and renders.

Build with:

```sh
/opt/homebrew/bin/blender -b --python blender/refinements/r33/build_creased_plate.py
```

This models the intended appearance, not the tool or forming behavior of a
specific steel stock. Production depth and crease radius need prototyping.

## Material direction

The appearance study uses satin 430 ferritic stainless steel (EN 1.4016).
The grade is magnetizable and supplied as cold-rolled sheet. A forming grade
such as Aperam K30ED is another candidate for pressed artwork. The 0.35 mm
sheet and 0.15 mm modeled crease are provisional; a physical sample must
check forming, flatness, adhesive contact, finish, corrosion, and magnetic
holding force.

- [Outokumpu Moda range datasheet](https://www.outokumpu.com/-/media/files/products/moda/outokumpu-moda-range-datasheet.pdf)
- [Aperam K30/K30ED technical sheet](https://www.aperam.com/sites/default/files/documents/FT_K30-K30ED_en_web.pdf)

## Moving-light study

`animate_sheen.py` loads the saved R33 Blender file and animates a strip
light across the logo. The script produces PNG frames in `sheen-frames/`;
`r33-moving-sheen.mp4` is the cropped, three-second H.264 review export.
`deepreal-creased-logo-light-sweep-r33.blend` has the editable light
keyframes. The material shader is an illustrative satin finish, not a measured
sample of a particular supplier's sheet.

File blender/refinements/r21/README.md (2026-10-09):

# R21 side-supported drum concept

This revision studies the user's three-support layout: one fixed center
divider and one removable support at each outside end. The rear-entry arms
from the earlier concept are absent. The top of both drums is exposed. The
old rear access cuts and covers are replaced with continuous shells. The
intended assembly path is through the inner drum ends, but the inherited
shell's solid end cap has not yet been cut away under the provisional lip.

## Files

- `deepreal-side-supported-drums-r21.blend` is the editable Blender concept.
- `r21-exterior-preview.png` and `r21-front-preview.png` are review images.
- `renders/` contains additional above, travel-pose, mechanism, and drive
  views generated by `render_r21.py` (the directory is ignored by Git).
- `r21-assembly-manifest.json` lists the new parts and removed proxies.
- `r21-clearance-check.json` records sampled mesh intersections.

## Mechanism shown

Each drum is supported by a large inner bearing envelope attached to the
center divider through two recessed webs, and a smaller outer bearing and
hollow spindle at its outside cheek. A stationary motor near the center
drives a rotating internal ring gear through a pinion. A magnet on the drum
passes a fixed encoder board near the outer cheek. A moving flex proxy meets
a fixed harness at the hollow outer spindle. The drums have a 5 mm shell-end
gap, occupied in part by the 3 mm center support and its fairing.

The sampled directions are face 45° up, forward, 45° down and interaction
forward, 22.5° down, 45° down. The high, middle, and low renders show those
paired poses from above. These are review poses, not proven travel limits.
The saved render has the face drum forward and interaction drum 45° down.

## Engineering status

This is a packaging and appearance study, not a fabrication drawing. The
sampled moving shells, end parts, and races have no triangle intersections
with the fixed supports and drive envelopes at the listed poses. The check
does not certify minimum clearances, bearing loads, gear teeth, motor torque,
hard stops, wire bend life, thermal behavior, fastening, or assembly access.
The encoder board recess and mount are also schematic.

The R20 wide interaction lens and board envelopes still intersect the old
optical carrier. Their mount and the front window need a separate redesign
before a mechanically accurate or website-ready render. The exterior review
images show the design direction; materials and lighting are provisional.
The separate inner lip originally shared the old shell's outer surface with
different tessellation, producing stepped viewport marks. It is now inset
0.06 mm to prevent that display artifact. A real hollow shell and bearing
seat must still replace the overlapping concept meshes.

Regenerate from the repository root with:

```sh
blender -b -t 4 --python blender/refinements/r21/build_r21.py
blender -b -t 4 --python blender/refinements/r21/check_r21.py
blender -b -t 4 --python blender/refinements/r21/render_r21.py
```

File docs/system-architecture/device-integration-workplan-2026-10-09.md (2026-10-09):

# DeepReal device integration workplan — 9 October 2026

Status: engineering work order. The exterior study can support appearance review;
the internal hardware is still an unverified concept. This plan does not approve a
board, flex, actuator, optical output or fabrication release.

The first [measured drum-interface audit](../electrical/drum-interface-finding-2026-10-09.md)
found two geometry blockers: the encoder magnet/sensor envelopes sit 6 mm off
the rotation axis, and the specified optical flex end is 15.6 mm wide while
the modeled outer spindle bore is 2 mm. Resolve these together before treating
the R21 mechanism as a cable or encoder layout.

## Working assembly

The current exterior is the R30 housing with two exposed-top drums, fixed left
and right cheeks, a fixed center divider, and a monitor-top ledge. R21 supplies
the internal motion *envelopes*. One reusable optical-head electrical design is
intended to populate both drums, with different RGB assembly variants. These
pieces have not yet been reconciled into a buildable assembly.

```text
                            stationary housing and center divider
              ┌──────────────────────────────────────────────────┐
face drum     │ fixed motor/drive → rotating ring → drum          │
              │ inner bearing                       outer bearing │
              │ moving optical head → dynamic flex → fixed harness
              │ rotating magnet → fixed angle sensor at cheek    │
interaction   │ same mechanism; different optical population     │
drum          │ and separately chosen travel stops               │
              └──────────────────┬───────────────────────────────┘
                                 │ power, CSI, control, motor and angle wiring
                       main PCBA ↔ USB-C ↔ host
```

The outer cheeks and center divider should react bearing and motor loads into
the same housing. The moving optical flex must have its own controlled path and
life test; the motor and stationary angle sensor use fixed wiring to the main
board. A render showing these paths is not evidence of clearance or fatigue life.

| Interface | Drum or actuator side | Housing/main-board side | Current status |
| --- | --- | --- | --- |
| Drum support | Rotating inner ring and outer hub | Center-divider bearing seat and outer-cheek spindle | Envelopes only; bearing/coupling unselected |
| Drum drive | Internal ring gear attached to drum | Center-fed motor, bracket and pinion | Envelope only; torque, teeth and fastening open |
| Optical data and power | Reusable RGB/IR/projector head in each drum | Main-board J2/J3 through an outer-axis exit | 51-contact grouping exists; pinout, bend and current unapproved |
| Absolute drum angle | Magnet rotates with end face | Hall sensor/board at outer cheek | Physical location conflicts with main-board register |
| Motor position and power | Motor quadrature encoder and motor terminals | Main-board J4/J5 and U13/U14 | Harness concept exists; exact motor and connector pending |

## First integration conflict to close

R21 places each rotating encoder magnet next to a **stationary angle-sensor
board at the outer cheek**. The main-board component register still lists
U18/U19 AS5600L as **main-PCBA top-side components**, and the circuit plan
groups them with the motor harnesses. Those two physical locations cannot both
describe the same sensor. R21 also labels its Hall IC as unselected, so the
AS5600L choice and magnetic geometry need confirmation.

Preferred layout direction for evaluation: keep a small stationary sensor
daughterboard at each cheek, close to the rotating magnet; carry power,
ground and angle-data signals to the main PCBA by a fixed harness. This avoids
requiring the sensor to read a magnet across the device from the main board.
Before updating KiCad, verify sensor-to-magnet orientation, air gap, angular
error, cheek thickness, motor-field interference, address/voltage compatibility
and service access. Then move the physical U18/U19 placement ownership from the
main board to those cheek boards, or document a different proven geometry.
Keep the motor quadrature encoder separate from this absolute-angle function.

## Execution sequence and exit evidence

| Order | Work package | Deliverable that closes it |
| --- | --- | --- |
| 1 | Freeze one reference drum's physical interface | Coordinate drawing with center/outer bearing seats, fixed vs rotating parts, magnet and sensor datum, motor/pinion/ring coupling, head-board envelope, cable exit, hard stops and service clearances. Repeat with the second drum's optical and travel differences. |
| 2 | Prove motion and wiring envelopes | Selected bearing and motor candidates, torque/inertia/gear calculation, backlash target, full pose collision sweep, hard stops, moving-flex bend radius and cycle-life plan. Travel limits follow optical coverage and wire life; existing R21 poses are provisional. |
| 3 | Resolve stationary and moving interconnects | Numbered end-to-end 51-contact head flex; mating side and contact orientation; six camera differential pairs per head; power/return allocation; motor/quad harness and cheek sensor harness. Provide continuity drawing and current, voltage-drop, signal-integrity and fatigue review. |
| 4 | Complete head power, clocks and safety | Mode-specific RGB/IR load and startup budget, local conversion losses, projector capacitor recharge, 38.4 MHz Mira220 reference-clock implementation, power sequencing and hardware-default-off projector interlock. Then capture the reusable head schematic and outline. |
| 5 | Close compute and external connection | Compile one- versus two-FPGA alternatives on supported tools with legal pins/timing; define simultaneous capture and USB output/encoding policy; select a USB-C mating solution at the housing opening, including compatible board thickness and insertion support. |
| 6 | Design the actual main board | Audit exact parts and footprints, populate the functional KiCad sheets, run ERC, select stack-up, place from pin and enclosure constraints, prove critical routes, then complete routing/DRC, thermal and specialist review. Board size remains a candidate until this is done. |
| 7 | Prototype and validate | Bench one drum/head first: startup absolute-angle and quadrature correlation, motion under cable load, flex life, sensor/clock behavior, power transients, projector safety and thermal behavior. Integrate the second drum and full USB capture after the reference module passes. |

Packages 1, 3 and 4 can advance together. Package 5 can run in parallel once
its camera and mechanical connector assumptions are explicitly recorded.
Packages 6 and 7 depend on the interface and electrical evidence above.

## Next concrete engineering pass

The [R34 face-drum interface study](../../blender/refinements/r34/README.md)
now places a rotating magnet on the outer drum axis opposite a stationary
cheek-board envelope and passes a 15.6 mm straight flex envelope through the
inner bearing. Its sampled straight-segment sweep clears the current fixed
geometry. The study leaves the deforming service loop, shaft/hub coupling,
cheek wall, selected bearing and interaction drum unresolved; it is evidence
for packaging direction, not a fabrication-ready mechanism.

The follow-on [R35 motion study](../../blender/refinements/r35/README.md) adds
an outer rotating web from shaft and hub to drum wall. Its concept geometry
clears the fixed bearing and enclosure, but the joints and loads are open.
The moving cable route is blocked in the current package: all eight sampled
full-width axial-twist candidates intersect the existing bearing supports;
longer routes also intersect the optical carrier. The immediate integration
task is to redesign the inner bearing support and cable architecture together
before assigning a final drum flex or freezing the head-board connectors.

The [R36 bearing-window study](../../blender/refinements/r36/README.md)
resolves the first geometric obstruction at concept level: an axial fixed
bearing neck and side webs clear the rotating ring and straight 15.6 mm strip
over sampled face-drum poses. The service loop and fixed cable exit remain
unmodeled. A 6–8 mm trunk-width screen and offset screen did not find a
collision-free simple twist through the current optical-carrier layout, so
the next pass must reserve a separate moving-cable volume and verify the
electrical construction before changing the 51-contact interface.

The [R37 rear-space study](../../blender/refinements/r37/README.md) places a
test passage through the center divider and a test chamber within the rear
housing. The passage intersects the current rear bearing support web, while
the chamber is occupied by the solid visual enclosure. The cable also needs
a change of orientation to reach that chamber without bending edgewise.
These are volume reservations, not cutouts or a complete cable path. Design
the support, flex loop, and fixed termination together before cutting the
housing or treating the R37 view as an assembly solution.

1. Make a shared coordinate and connection drawing for **one drum** using the
   R30 housing and R21 motion envelopes. Mark every fixed support, rotating
   part, cable and board. Include the cheek angle-sensor board option.
2. Write the per-drum interface table from head connector to main board, plus
   separate motor/quad and angle-sensor harnesses. Number contacts only after
   checking both connector ends and flex orientation.
3. Reconcile the schematic/component register with that physical partition.
   Do not move U18/U19 in the PCB file until the cheek geometry and electrical
   interface are reviewed.
4. Run the full pose sweep with transparent housing and three views per pose:
   front, above and end-on. Inspect lens clearances, top opening, flex path,
   bearing support and wire exposure at both travel limits.

The monitor attachment and decorative plate remain a separate mount-validation
track: retention/release force, laptop hinge load, adhesive aging and the
selected magnet or clip mechanism. They do not set the internal PCB pinout.

## Evidence behind this work order

- `blender/refinements/r21/r21_mechanism.py`: bearing, motor, gear, magnet and
  flex envelopes; no selected hard stops or fatigue proof.
- `blender/refinements/r30/r30-mount-manifest.json`: current exterior/ledge study.
- `hardware/electronics/deepreal-main-pcba/component-register.csv` and
  `circuit-specification.md`: current U18/U19 and J4/J5 ownership.
- `hardware/electronics/deepreal-main-pcba/design-status.json`: G3/G4 blocked,
  G5 in progress, G6 blocked, routing not started.
- `docs/electrical/head-interface-checkpoint-2026-09-14.md`: 51-contact flex,
  connector orientation and current constraints.
- `docs/electrical/pcb-progress-2026-09-14.md`: board and circuit status.
- `docs/design/main-pcba-usb-mechanical-options-v0.1.md`: USB opening/port
  mismatch and board-thickness conflict.
- `docs/research/main-pcba-fpga-topology-study-v0.2.md`: topology decision gate.

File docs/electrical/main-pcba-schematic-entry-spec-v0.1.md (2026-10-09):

# DeepReal Main PCBA - Schematic Entry Specification v0.1

> **Superseded architecture note (13 September 2026):** Use this document as source
> evidence, not as permission to freeze two FPGAs or begin pin-driven layout. The
> authoritative requirements are in `main-pcba-engineering-requirements-v0.2.md`;
> FPGA count remains open in the v0.2 topology study until compile evidence exists.

| Field | Value |
| --- | --- |
| Date | 12 September 2026 |
| Status | Pre-schematic engineering baseline; not manufacturing-ready |
| Main board target | 90 x 28 x 1.6 mm, two-sided assembly |
| Populated envelope | Approximately 90 x 28 x 15 mm including shield/thermal stack |
| Purpose | Prevent the schematic and 3D model from being built on generic blocks |

> **Capture status (12 September 2026):** The tool-neutral schematic source package
> now exists at `../../hardware/electronics/`. It defines the 15 main-board sheets,
> the reusable optical-head design, reference ownership, named nets, connector groups
> and pin-map gates. A checked EDA schematic/netlist still requires vendor symbol
> import, FPGA pin compilation, the first DDR-tool pass and ERC.

## Outcome

The 90 x 28 mm main board remains plausible enough to continue, but it is not yet
proven. The architecture now has a credible schematic entry point and three material
changes from the current visual model:

1. Use two 6 x 6 mm LIFCL-17 camera bridges, one per drum, rather than one generic
   9.5 mm FPGA.
2. Use one 51-position high-speed flex connector per drum as the compact baseline,
   with the current four 22-position camera connectors retained as a lower-risk SI
   fallback.
3. Put each AS1170 projector driver, its inductor, pulse capacitor, local camera
   regulators and interlock circuit on a small rotating head carrier. These are
   internal product electronics, not external development boards. Shortening the
   projector pulse loop is more credible than sending the switched 700 mA pulse
   through the rotating flex.

The i.MX 95 and LPDDR packages must not touch. Their bodies need an assembly gap,
while the DDR routing must remain short. The final gap and relative orientation come
from BGA escape and DDR routing, not from visual preference.

### First board-space sanity check

- The raw projected area of all current main-board package and connector bodies in
  Mechanical BOM v0.2 is approximately 1,044 mm2. That is 41.4% of one 90 x 28 mm
  board face, before support passives, courtyards, routing and keep-outs.
- The board has two assembly faces, so package body area alone does not force a size
  increase. The controlling constraints are DDR escape, six MIPI corridors, USB,
  power-loop copper, flex access and the thermal contact zone.
- Two 51-position drum connectors occupy 31.2 mm of body length in total versus
  approximately 52 mm for the older four-connector concept.
- A 15 mm i.MX body, a 1.5 mm assembly gap and the 10 mm LPDDR body consume 26.5 mm
  along the long axis while staying about 15 mm deep. That geometry fits on paper;
  fan-out and length matching still decide whether it fits electrically.

This is enough evidence to keep 90 x 28 mm as the working target, but not enough to
claim that routing will close at that size.

## 1. Locked schematic baseline

| Function | Baseline part | Package / body | Confidence | Status |
| --- | --- | --- | ---: | --- |
| Application processor | NXP MIMX9596CVTXNAC | 548-ball FC-PBGA, 15 x 15 mm, 0.5 mm pitch | 85% | Exact industrial six-core 15 mm SKU |
| LPDDR4X | Micron MT53E1G32D2FW-046 AAT:B | 200-ball, 10 x 14.5 mm | 65% | 4 GB baseline; NXP DDR validation required |
| eMMC | Micron MTFC32GBCAQTC-AAT | 153-ball, 11.5 x 13 mm | 85% | 32 GB, eMMC 5.1 |
| Camera bridges | 2 x Lattice LIFCL-17, csfBGA121 | 6 x 6 mm, 0.5 mm pitch | 70% | Exact speed grade/order suffix after Radiant compile |
| Main PMIC | NXP MPF0900AVNA2ES | HVQFN56, 8 x 8 mm | 90% | Industrial QM OTP for i.MX 95 + LPDDR4X |
| SoC regulator | NXP MPF5302BVNAAEP | H-FC-PQFN24, 15 A class | 85% | VDD_SOC baseline |
| CPU regulator | NXP MPF5301BVNABEP | H-FC-PQFN24, 8 A class | 85% | VDD_ARM baseline |
| Protected 5 V buck | TI TPS56637RPAR | VQFN-HR10, 3 x 3 mm | 80% | 15 V to system rail; validate 5 V fallback dropout |
| Motor 6 V buck | TI TPS56637RPAR | VQFN-HR10, 3 x 3 mm | 75% | Enabled only when USB contract is at least 9 V |
| Input eFuse | TI TPS259472LRPWR | WQFN10, 2 x 2 mm | 80% | 23 V, reverse blocking, current monitoring |
| USB-PD sink | Infineon CYPD3177-24LQXQ | QFN24, 4 x 4 mm | 90% | 15 V / 3 A preferred contract |
| USB orientation mux | TI HD3SS3212IRKSR | VQFN20, 2.5 x 4.5 mm | 90% | Industrial USB SuperSpeed mux |
| Motor drivers | 2 x TI DRV8213RTER | WQFN16, 3 x 3 mm | 90% | Current sense/regulation and hardware stall detection |
| Motor | 2 x Pololu item 5137 | 6 V micro gearmotor | 90% electrical | 0.67 A theoretical stall each |
| Absolute drum angle | 2 x AS5600L-AWLM | WLCSP15, 2.07 x 2.63 x 0.6 mm | 70% | Programmable I2C addresses; supply-transition check required |
| Shared sensor clock buffer | TI LMK1C1104DQFR | WSON8, 2 x 2 mm | 75% | Four low-skew LVCMOS outputs |
| Board EEPROM | Microchip AT24C64D-MAHM-T | UDFN8, 2 x 3 mm | 90% | Non-secret board revision/calibration selection |
| Main board temperature | TI TMP117AIDRVR | WSON6, 2 x 2 mm | 90% | Place near i.MX thermal path |
| Digital microphone | TDK MMICT3902-00-012 | LGA, 3.5 x 2.65 mm | 90% | PDM, bottom port |
| Case tamper | Omron D3SK-B1R | Surface-mount NC switch, 3 x 3.5 x 0.9 mm | 70% | Exact lever direction still enclosure-dependent |
| Drum connector baseline | 2 x Hirose FH26W-51S-0.3SHW(97) | 51 pos, 15.6 x 3.2 x 1.0 mm | 65% | Dynamic-flex and SI validation required |
| RGB sensors | Face SA31VA30P; interaction SA36VA30P wide | Both 10.8 x 10.8 mm sensor assemblies | 70% electrical, optical fit open | Variant pinout and common head carrier to verify |
| IR sensors | 2 x ams OSRAM Mira220 Q65114A0087 | CSP, 5.4 x 5.4 x 0.74 mm | 80% | Located on head carrier |
| Projectors | 2 x ams OSRAM Belago1.2 Q65114A0198 | 4.2 x 3.6 x 3.325 mm | 75% | Located on head carrier |
| Projector drivers | 2 x ams OSRAM AS1170 Q65113A7129 | WLCSP13, 2.25 x 1.5 x 0.6 mm | 75% | Located on head carrier |

Exact orderable suffixes above are a purchasing baseline, not blanket approval for
production. Availability, lifecycle and alternates must be checked again at design
release.

## 2. Board partition

```text
USB-C
  |-- CC1/CC2 --> CYPD3177 PD sink
  |-- VBUS ----> eFuse ----> protected VBUS
  |                         |-- 5 V system buck --> PF09 + two PF53 --> i.MX95/DDR
  |                         |                    --> local FPGA rails
  |                         |                    --> two optical-head flexes
  |                         `-- 6 V motor buck --> two DRV8213 --> stationary motors
  `-- USB 3.x --> ESD --> orientation mux --> i.MX95 USB1

Main PCBA                 Face head carrier       Interaction head carrier
i.MX95 + memory           IMX708 assembly         IMX708 assembly
2 x LIFCL-17              Mira220                 Mira220
USB and power             AS1170 + Belago         AS1170 + Belago
motor drivers             local sensor rails      local sensor rails
clock/reset/control       local interlock         local interlock
```

The absolute drum-angle sensors should be stationary at the drum axes with their
magnets on the rotating shafts. They therefore do not require a rotating flex. The
motor's incremental encoder can be used for velocity and commutation feedback, but it
does not replace the absolute angle sensor required for trusted pose after power-up.
AS5600L is preferred over the fixed-address AS5600 so both axes can share a controlled
bus if desired. Reconfirm the manufacturer/order code before release because this
sensor family is in a supplier-ownership transition.

## 3. Power contract and operating modes

| USB input | Allowed behavior |
| --- | --- |
| 15 V / 3 A | Full design mode; 45 W input ceiling, not 45 W dissipation |
| 9 V / 3 A | Normal or moderately derated mode after measured power validation |
| 5 V / 3 A | Boot, enumerate and service mode; motor 6 V rail disabled; capture duty and compute capped |
| Less than 5 V / 3 A equivalent | Do not begin a capture session; report insufficient source power |

The CYPD3177 advertises and negotiates sink voltages; it does not replace the DC/DC
converters. Firmware must read or infer the accepted contract before enabling the
motor and projector state machines.

The current rail budget is maintained in
`main-pcba-rail-budget-v0.1.csv`. Important design limits are:

- 5 V system converter: 6 A continuous class, with thermal design based on measured
  sustained load rather than the nameplate current.
- 6 V motor converter: at least 1.5 A short-duration combined load and 2 A design
  capacity; both motors may not remain stalled.
- Each RGB head needs a 1.1 V rail capable of 600 mA plus 1.8 V and 2.8 V rails.
- Each Mira220 head needs sequenced 2.5 V, 1.35 V and 1.8 V rails; the 2.5 V rail
  must tolerate the documented 350 mA startup interval.
- Only one projector is intentionally active at a time. Local energy storage must
  keep its pulse out of the camera and SoC rails.

## 4. Camera topology and lane budget

Per drum, the initial operating point is:

| Stream | Mode | Active payload | FPGA input |
| --- | --- | ---: | --- |
| RGB | 1920 x 1080, 50 fps, RAW10 | 1.04 Gbit/s | 2-lane CSI-2 hard D-PHY |
| IR | 1600 x 1400, 60 fps, RAW10 | 1.34 Gbit/s | 2-lane CSI-2 soft D-PHY |
| Aggregated output | Both streams + 25% allowance | 2.98 Gbit/s | 4-lane CSI-2 hard TX |

Each LIFCL-17 assigns fixed virtual-channel IDs, validates packet structure, adds a
frame counter and reports stream errors. Face output goes only to i.MX CSI-0;
interaction output goes only to i.MX CSI-1. Full-rate frame hashing remains in
protected i.MX memory unless an FPGA benchmark later proves a stronger boundary.

The exact FPGA pin map is not considered closed until the same two-input/one-output
project compiles and meets timing for the 121-ball package. The published resource
count is encouraging but is not a pinout proof.

## 5. Drum flex definition

The 51-pin connector is allocated by signal group rather than final pin number until
the flex vendor confirms contact orientation and stack-up:

| Group | Contacts | Notes |
| --- | ---: | --- |
| Head 3.3 V feed | 8 | Parallel contacts; nominal 1.6 A before system derating |
| Dedicated power returns | 8 | In addition to high-speed return contacts |
| RGB CSI clock/data | 6 signal + 3 return | Clock plus two data lanes |
| IR CSI clock/data | 6 signal + 3 return | Clock plus two data lanes |
| RGB MCLK + return | 2 | 24 MHz from clock buffer |
| IR MCLK + return | 2 | Corrected 14 Sep: 38.4 MHz Mira220 reference; distribution open |
| Shared I2C/CCI | 2 | Confirm non-conflicting addresses; add mux only if required |
| RGB reset and IR reset | 2 | Independent trusted control |
| IR trigger and illumination trigger | 2 | Exposure/projector synchronization |
| Projector enable and fault | 2 | Hardware default-off |
| Interlock status | 1 | Must fail safe on open flex or open lens loop |
| Head temperature alert | 1 | Local sensor/driver thermal protection |
| Head identity | 1 | Local carrier revision/calibration identification |
| Shield / reserved | 2 | Assigned after SI and flex review |
| **Total** | **51** | Includes two uncommitted contacts before SI review |

This compact interface is mechanically attractive but electrically aggressive. The
fallback remains two separate camera flexes plus a power/control flex per drum if the
51-conductor dynamic flex cannot meet impedance, crosstalk or fatigue requirements.

## 6. Clock, reset and boot plan

- i.MX95 uses its manufacturer-required 24 MHz system reference and the required
  power-on reset network. Add a 32.768 kHz RTC reference only if holdover behavior
  justifies it.
- Correction, 14 September: the proposed common 24 MHz RGB/IR source is withdrawn.
  Mira220 DS000642 v9 table 3 specifies 38.4 MHz. Y2/U17 remain RGB candidates;
  IR clock generation/distribution, levels, jitter and gating require their own
  design decision. See the optical-head `power-clock-evidence.json`.
- PF09 and both PF53 devices own the i.MX power sequence. Do not create an unrelated
  discrete sequence.
- Each FPGA gets independent PROGRAMN, INITN, DONE, reset and chip select. i.MX loads
  authenticated bitstreams after boot; camera capture remains disabled until both
  configurations are measured and accepted.
- Primary boot is signed software from eMMC. Recovery uses i.MX USB serial download.
  A 6 x 8 mm optional Octal-SPI footprint may be reserved, but no NOR device is
  required in the first schematic merely to make the board look complete.
- Board identity/calibration EEPROM is separate from device signing keys. Device keys
  remain in EdgeLock; the EEPROM stores non-secret board revision and calibration
  selection data.

## 7. USB-C data path

- USB1 is the recovery and product data port.
- Route SuperSpeed pairs through external ESD protection and the industrial
  HD3SS3212 orientation mux. Keep the connector, ESD and mux in one short corridor.
- Route USB 2 D+/D- with its own low-capacitance protection. Do not route USB data
  through the CYPD3177; that part controls Type-C/PD power behavior.
- Baseline protection population is one TPD4EUSB30-class four-channel array for USB
  SuperSpeed, one TPD2EUSB30A-class device for USB 2 and three TPD4E05U06 arrays at
  each drum connector for the twelve MIPI conductors. Final capacitance and placement
  require an eye-diagram review; these parts cannot be decorative blocks.
- CYPD3177 HPI/I2C and fault outputs connect to trusted control so accepted source
  power becomes part of the capture enable policy.
- The USB-C shell needs a chassis/EMI strategy distinct from digital ground, joined
  only through the final EMC network.

## 8. Physical layout rules before aesthetic routing

- Working assumption: 10-layer HDI, controlled-impedance stack, laser microvias and
  via-in-pad where the 0.5 mm BGAs require it. Final stack-up comes from the chosen
  fabricator.
- LPDDR sits in the i.MX DDR escape direction with no connector or switching node in
  the DDR corridor.
- One FPGA sits near each drum connector and its associated i.MX CSI receiver.
- Keep inductors, motor current loops and projector power entry away from MIPI, DDR,
  microphone port and clock routing.
- Put decoupling on both sides where allowed, directly at BGA power fields. The 3D
  model must show the capacitor fields, inductors, crystals, ESD arrays, test pads and
  courtyards rather than only major IC bodies.
- Reserve a rear-housing thermal contact over the i.MX95 through a compliant pad and
  copper spreader. Do not place tall components in that compression zone.
- Keep all dynamic flex bend volumes and connector actuator access outside the EMI-can
  wall. The can is not allowed to trap serviceable flexes.

## 9. Schematic page plan

1. Cover, revision, variants and design constraints
2. USB-C receptacle, ESD, PD negotiation and protected VBUS
3. 5 V system and 6 V motor conversion
4. PF09/PF53 power tree and sequence
5. i.MX95 power and decoupling units
6. i.MX95 boot straps, reset, clocks, debug and recovery
7. LPDDR4X
8. eMMC and board EEPROM
9. Face LIFCL-17, CSI input/output, config and sideband
10. Interaction LIFCL-17, CSI input/output, config and sideband
11. Face drum flex interface and protection
12. Interaction drum flex interface and protection
13. Motor drivers, absolute encoders and connectors
14. Microphone, tamper, temperature and miscellaneous I/O
15. Test points, manufacturing options and no-fit parts

## 10. Gates that cannot be closed by documentation alone

| Gate | Required evidence | What it can change |
| --- | --- | --- |
| DDR | NXP DDR tool settings, length rules and memory bring-up | LPDDR part, orientation, board layers |
| FPGA | Radiant compile, legal pin assignment and timing closure in csfBGA121 | FPGA package/count and connector placement |
| Dynamic flex | Vendor stack-up, impedance model and 160-degree cycle test | One 51-pin vs multiple flexes per drum |
| Optical head | RGB/IR/projector bench with real lens and baseline | Sensor choice, aperture spacing, head PCB size |
| Eye safety | IEC 60825-1 system assessment including single faults | Projector current, interlock and public claims |
| Motor | Measured torque, inrush, stall, settling and acoustic data | Gear ratio, driver limit, 6 V rail size |
| USB source | Tests on target laptops/docks at 5/9/15 V contracts | Full single-cable claim and derating policy |
| Thermal | Sealed-enclosure sustained workload test | SoC power cap, shield/spreader and enclosure vents |
| SI/PI | DDR/MIPI/USB simulation and power-rail impedance review | Stack-up, spacing, passives and board size |
| Security | Protected-DMA and fault-injection demonstration | Hash boundary and marketing language |

## 11. Entry decision

The preliminary schematic may now begin using this document as its baseline. It must
not be called final, and PCB routing should not begin until at least the DDR rules,
FPGA pin compile and drum-flex topology have passed their first engineering reviews.
The 3D model can be updated immediately to show the corrected packages, carrier-board
partition and realistic support-component density, while clearly labeling unverified
routes as illustrative rather than copper derived from a netlist.

## Primary manufacturer sources

- [NXP i.MX 95 industrial data sheet](https://www.nxp.com/docs/en/data-sheet/IMX95IEC.pdf)
- [NXP PF09 data sheet](https://www.nxp.com/docs/en/data-sheet/PF09.pdf)
- [NXP PF53 product and ordering table](https://www.nxp.com/products/PF53)
- [Lattice CrossLink-NX family](https://www.latticesemi.com/CrossLinkNX)
- [Raspberry Pi Camera Module 3 reference schematic](https://pip-assets.raspberrypi.com/categories/1207-design-files/documents/RP-008969-SD-3-Raspberry%20Pi%20Camera%20Module%203%20Reference%20Schematic.pdf)
- [ams OSRAM Mira220](https://ams-osram.com/products/sensor-solutions/cmos-image-sensors/ams-mira220)
- [ams OSRAM Belago1.2](https://ams-osram.com/products/lasers/ir-lasers-vcsel/ams-belago1-2-dot-pattern-illuminator-vcsel)
- [ams OSRAM AS1170](https://ams-osram.com/products/drivers/led-drivers/ams-as1170-2-channel-led-and-vcsel-driver-ic)
- [TI DRV8213](https://www.ti.com/product/DRV8213)
- [TI high-speed ESD array](https://www.ti.com/product/TPD4E05U06)
- [TI TMP117](https://www.ti.com/product/TMP117)
- [AS5600L data sheet](https://look.ams-osram.com/m/657fca3b775890b7/original/AS5600L-DS000545.pdf)
- [Pololu item 5137](https://www.pololu.com/product/5137/specs)
- [Infineon CYPD3177](https://www.infineon.com/part/CYPD3177-24LQXQ)
- [Hirose FH26 series connector catalog](https://www.hirose.com/en/product/document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)

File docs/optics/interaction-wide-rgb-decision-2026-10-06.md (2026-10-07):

# RGB lens roles — 6 October 2026

Status: **EVT optical choice; packaging and coverage not yet validated**.
This supersedes the two-standard-RGB-lens entry in the historical
`docs/research/main-pcba-architecture-input-decisions-v0.1.md`. It does not
resolve that document's independent FPGA-topology question.

| Drum | RGB assembly | Published horizontal × vertical FoV | Provisional optical travel |
| --- | --- | --- | --- |
| Face | Raspberry Pi SA31VA30P standard | 66° × 41° | 45° up to 45° down |
| Interaction | Raspberry Pi SA36VA30P wide | 102° × 67° | straight to 45° down |

Manufacturer basis: [Raspberry Pi Camera Module 3 Sensor Assembly product brief](https://datasheets.raspberrypi.com/camera/sensor-assembly-product-brief.pdf), physical specification and variants table. Both assemblies have a 10.8 × 10.8 mm outline. The standard lens is Ø5.75 mm with a 6.98 mm depth dimension; the wide lens is Ø6.95 mm with an 8.3 mm depth dimension. The wide lens focuses down to 5 cm versus 10 cm for standard. Both are IMX708-based visible-light variants.

## What this changes

- Populate the face head with SA31VA30P and the interaction head with SA36VA30P. The shared electrical head-carrier design remains a target. Verify the wide variant's exact connector mating, pinout, autofocus load and support components before treating the populations as interchangeable.
- Reserve the larger interaction lens space. The [R20 Blender envelope study](../../blender/refinements/r20/README.md) places the published outline and a conservative lens cylinder against the current R16 drum. It finds no triangle overlap with the rotating shell, **but the larger envelope intersects the old internal optical-carrier proxy**. That carrier must be redesigned. The existing 9 mm *visual* bore does not prove wide-angle optical clearance.
- Use the [desk-coverage study](../../blender/refinements/r20/r20-interaction-desk-coverage.png) to select travel after mounting height and target work area are known. At 45° down, the wide RGB field reaches 78.5° down, leaving 11.5° to vertical. A point directly below the camera is outside that idealized image. The face and interaction proposed ranges are shorter than 180° and are not physical stops yet.
- Check the depth receiver lens and projector field separately. Their useful overlap with the wide RGB image has not been established. Calibrate RGB lens distortion and alignment on hardware.

## Required closure before fabrication

1. Fix camera mounting height and horizontal offset from the keyboard/work area, then mark the nearest and farthest points that must be visible. Run full 3D field, window, enclosure and focus checks at every selected drum pose.
2. Obtain the exact wide assembly CAD or optical datum; redesign the optical carrier and window with assembly and tolerance clearance. The R20 cylinder is an envelope, not a validated lens model.
3. Compare standard and wide assembly electrical datasheets, power demand and connector mating; update the common carrier and rail budget accordingly.
4. Measure RGB, IR/depth and projector overlap on an optical bench, then set hard stops and moving-cable routing. The future open-top/center-divider support concept needs its own mechanical build.

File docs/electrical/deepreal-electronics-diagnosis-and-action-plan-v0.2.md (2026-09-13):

# DeepReal electronics diagnosis and action plan v0.2

Date: 13 September 2026. Inspected baseline: `main`, commit `50ea864`.
Scope: main PCBA, both rotating sensor heads, flexes, position sensing, USB integration, and the KiCad-to-Blender presentation pipeline.
Status: diagnosis and proposed execution plan; no electrical or mechanical design changes made during this audit. Complements the existing engineering-review plan with measured findings and corrected priorities. It does not grant a release approval.

Implementation note, 14 September: the pipeline findings below describe the
inspected baseline, not all current code. See the
[native-import checkpoint](native-pcba-import-checkpoint.md) for Stage A changes.
Electrical and mechanical blockers remain open.

## 1. Conclusion and intended result

The current files are an incomplete packaging study with a partially connected visualization pipeline. They are not a coherent electrical layout yet. Senior engineering review would find substantive problems in connectivity, footprints, board-to-board interfaces, moving flex geometry, and the correspondence between the schematic, PCB and render.

The useful foundation is the enclosure, named subsystem arrangement, candidate component register, 90 × 28 mm main-board envelope, two rotating optical payloads, and reproducible scene generation. Keep these as starting constraints. Exact fit and final board size remain unresolved.

The next deliverable should be a reviewable electronics assembly: an actual main-board design, a reusable head-board design installed twice, a documented position-sensor arrangement, real interconnect definitions, and renders generated from those designs. A polished render is an output of that work. It cannot establish electrical correctness by itself.

There are two review checkpoints: an internal geometry/interface review that makes the assembly understandable, followed by a routed electrical review that can support publication. Show progress at the first checkpoint, but do not label it finished or publish it under the routed-review caption.

## 2. Evidence gathered in this audit

Read the current KiCad sources/export, component/evidence registers, optical-head capture documents, requirements, topology study, Blender geometry/import code, interconnect and motion code, and validators. Re-ran the gate, flex-allocation, camera-bandwidth and export validators. Ran KiCad DRC with schematic parity and all report severities. Inspected the saved Blender scene with a read-only script; it was not saved or rebuilt.

| Measurement | Current evidence | Meaning |
| --- | --- | --- |
| Main-board outline | 90 × 28 × 1.6 mm | A candidate envelope, not routing-supported fit |
| KiCad footprints | 238, including four mounting-hole footprints | Does not mean 238 selected, electrically defined components |
| Capacitor/resistor proxies | 144 C references, 44 R references | Mostly reserved values and independent space claims |
| Exported pads | 2,313; every pad has an empty net name | Actual electrical connections are absent |
| Actual tracks / vias / copper zones | 0 / 0 / 0 | No routing feasibility has been demonstrated |
| Functional schematic sheets | 14 under the root sheet; 0 populated with circuitry | The 15-page structure is a document scaffold |
| KiCad DRC | 610 violations, plus 199 schematic-parity issues | Existing placement cannot pass review |
| DRC unconnected items | 0 | Meaningless as a completion metric when pads have no defined nets |
| Blender component bodies | 201 | Different inventory from KiCad; counts alone cannot prove parity |
| Handmade Blender ground vias | 40 | Remain visible even though KiCad has zero vias |
| Tamper switch SW1 | Appears in Blender; absent from KiCad | Missing parts are still silently represented from fallback data |
| Head-board KiCad files | None in `deepreal-optical-head/` | Only requirements, registers and circuit prose exist |
| Head-flex allocation | 51 contacts in 16 groups; every group awaits physical pin numbers | Arithmetic fits; the cable cannot yet be wired from this definition |

The DRC report is preserved in [review evidence](review-evidence/2026-09-13-main-layout-check.json). It reports 149 clearance, 56 courtyard-overlap, 126 solder-mask-bridge, 7 copper-edge, 4 hole-clearance, 4 plated-hole-inside-courtyard and 3 non-plated-hole-inside-courtyard violations; 261 further items concern silkscreen/text. The separate 199 parity issues are extra footprints relative to the schematic.

Examples: J2 pad 2 and C59 pad 1 have zero copper clearance; D9's courtyard overlaps U10 and mounting footprint H3. These are findings on the existing proxy footprints, not proof that a future corrected footprint will have the same conflict. Replace wrong footprints before treating each marker as an independent routing problem.

Five checks are disabled in the current project, including missing courtyards and footprint-type/filter checks. Audit their relevance and restore applicable checks. `--severity-all` does not enable disabled checks. A clean result must also establish that required circuits and rules exist.

Reproduction:

```sh
/Users/adam/Applications/KiCad/KiCad.app/Contents/MacOS/kicad-cli pcb drc \
  --schematic-parity --severity-all --format json --output /tmp/deepreal-main-drc.json \
  hardware/electronics/deepreal-main-pcba/deepreal-main-pcba.kicad_pcb
```

Board SHA-256: `63739aa744a85b407b4784bacde8dd61b5b745cae19ed3499ce07cf85a1c31b5`.
Root schematic SHA-256: `df3893862b4aa8ce53c104299217cc40e541bd4ad6adaa6390dc58df595e9323`.

## 3. Main-board diagnosis and corrections

| ID | Finding | Correct response |
| --- | --- | --- |
| M01 | Processor U1 uses a generic 324-pad footprint while the register calls for a 548-ball device. Blender separately draws a 27 × 27 pad array. | Import the exact device's audited ball map and land pattern; derive both PCB and rendered pads from it. Matching the outer 15 mm square is insufficient. |
| M02 | DDR/eMMC pin maps are unaudited; processor/RAM proximity is only a neighborhood choice. | Audit memory variant, voltage, bus width, ball maps, boot compatibility and routing rules; select orientations from real connections. Keep the existing 2 mm body gap only if the resulting routing and assembly access support it. |
| M03 | PF53 footprints are 4 × 4 mm proxies versus the registered 3.5 × 4.5 mm bodies; angle sensors use 16-ball proxies for 15-ball parts; USB D2 has a wrong package proxy. | Complete symbol-to-pad audits for every major IC. Package names and appearance are not adequate evidence. |
| M04 | KiCad J1 uses an Amphenol footprint; Blender shows the selected Hirose shell. Its position is approximately 41.1 mm from the enclosure opening. | Solve receptacle, opening, insertion direction, plug clearance, retention and exact footprint together. Validate the recorded 0.8 mm recommended-board-thickness conflict against the final drawing before using it on a 1.6 mm board. |
| M05 | Load switches, TVS, oscillators, debug interface, motor connectors and several regulators/support parts remain unselected. | Choose orderable parts with documented requirements; include all external circuits, exposed-pad connections and test provisions in schematic and area budgeting. |
| M06 | Capacitors, resistors and inductors are reserved populations, not calculated circuits. | Calculate values, tolerance, effective capacitance under DC bias, ratings, inductor saturation/loss and converter compensation; place from actual power pins and switching loops. |
| M07 | Blender L3/L6 have zero nominal body-envelope gap; U5/L1 have 0.40 mm and D1/D2 0.05 mm. | Remove unintended body contact. Assess other gaps with exact courtyards, pads, manufacturing tolerances and rework access. A 0.40 mm body gap is not automatically unacceptable; the earlier blanket claim was too strong. |
| M08 | Upper-left space is unallocated; right side is congested. | Rebalance after USB, FPGA, head connectors, thermal contact and actual circuits are known. Do not fill the region decoratively or shrink the board based on projected body occupancy. |
| M09 | Ten layers are an unapproved intent model; the board has only generic rules and no critical net-class assignments. | Select a preliminary manufacturable stack with defined reference planes, impedance geometries, BGA escape and via rules. Encode DDR, camera, USB, clocks, memory and power constraints before routing. |
| M10 | The current layer intent places several signal/power layers together without an established reference-plane analysis. | Review return-current continuity, plane coupling and transitions; compare 8/10/12 layers using actual escape and routing demands. Layer count alone does not prove feasibility. |
| M11 | Cooling geometry connects tray → spreader → housing but does not establish processor → thermal interface. | Design and budget the entire heat path, including contact area, electrical isolation, compression and tolerances. Audit reads approximately 1.941 mm from U1's top to the inside of the front lid, with no modeled interface bridging it. A backside path would require its own board/thermal design. |
| M12 | The validator uses a 15 mm aggregate stack allowance while a separate populated reservation is 6 mm; heights are reported mainly from registered major parts. | Establish one local top/bottom height envelope from the actual enclosure. Check every body, solder joint, shield, pad, fastener, connector latch and tool-access volume against it. |
| M13 | Microphone port, switch actuation, ESD returns, shield ground contacts and assembly/test details are incomplete in KiCad. | Model these as explicit constraints and circuit features, then check them in installed and service configurations. |

Sources: [component evidence](../../hardware/electronics/deepreal-main-pcba/component-evidence.csv), [USB study](../design/main-pcba-usb-mechanical-options-v0.1.md), `blender/pcba_geometry.py`, `blender/electronics.py`, `blender/validate_pcba.py`, and the new DRC report. Manufacturer references: [NXP i.MX95](https://www.nxp.com/products/i.MX95), [Hirose receptacle](https://www.hirose.com/product/p/CL0480-0919-0-00).

## 4. Both drums and the actual board count

The intended head electronics are sensible as a partition: RGB assembly, IR sensor and lens, projector/driver, sensor regulators, decoupling, pulse storage, temperature sensing and a local emission interlock belong on the rotating head. Processor, RAM, storage and major system power stay stationary.

However, Blender currently creates an RGB PCB, an IR PCB and a projector PCB in each drum. These are bare geometric slabs, not three designed and interconnected boards. The electrical documents instead describe one reusable head-carrier design installed twice. Neither interpretation has been implemented as a head-board KiCad design.

Recommended starting architecture: one main board plus two copies of one head-carrier assembly. Evaluate a single rigid head carrier first; use multiple rigid islands or rigid-flex only if optics, assembly or the axle require them. A bought RGB assembly can contain its own substrate and short tail without becoming an independently designed DeepReal carrier board.

Two stationary angle-sensor boards may also be needed at the drum axes, and a small USB board may be needed at the external opening. That means three primary board assemblies, potentially five with angle boards, or six with a USB board, before counting supplier-internal substrates. These are candidates to reconcile, not a frozen BOM.

| ID | Finding | Correct response |
| --- | --- | --- |
| H01 | There is no real head-carrier PCB outline, schematic, pad layout, local rail layout or populated render. | Create one head KiCad project and a complete assembly definition; install it twice using explicit mechanical transforms and per-head identity/calibration. |
| H02 | The rendered RGB body is 8 × 8 mm with a 7 × 7 × 0.6 mm PCB; the selected Raspberry Pi assembly is 10.8 × 10.8 mm. | Replace generic body/lens/tail geometry with the selected assembly's drawing and connector. Redo axial and radial containment, focus travel, aperture and carrier checks. Never shrink the purchased assembly to fit the picture. |
| H03 | Mira220 is a bare sensor; the current generic camera body does not define the lens, holder, filter, focus spacing or complete sensor electronics. | Select a lens/holder/filter solution and package it with the exact sensor and required rails. Verify image circle, field of view, working distance and alignment tolerances. |
| H04 | Projector shape and three front apertures originate from concept geometry, not a demonstrated Belago optical path. | Check the actual emitting aperture, divergence, window transmission and clearance to housing. Any baffle/window arrangement needs optical justification. Keep or change the visible aperture pattern only from that evidence. |
| H05 | The 5 × 5.4 mm projector PCB placeholder carries none of the driver, inductor, pulse capacitor or interlock logic. | Place the full local switching circuit in the head budget, with a short current loop and separated camera routing. Do not assume its components fit on that slab. |
| H06 | Local regulator selections, rail sequence, reset logic, autofocus support and I²C address isolation are unfinished. | Capture the published sensor reference circuits, exact pin maps, local protection and test access. Check identical heads for address conflicts and back-powering through control signals. |
| H07 | Requirements call for IR capture at 60 fps, while the current illumination reference is 1 ms at 30 fps and only one projector active at a time. | Define the illumination/exposure schedule and required depth-output rate. Keep simultaneous sensor capture; establish whether every frame needs illumination, how pulses interleave, and how thermal/optical limits are met. Do not silently promise 60 illuminated depth frames per head. |
| H08 | RGB/IR/projector alignment, baseline, calibration and depth reconstruction are unproved. | Define target depth range/accuracy, optical overlap and calibration retention with temperature/motion. A dot projector and IR sensor alone do not demonstrate a working depth product. |
| H09 | Drum volume checks omit the complete electronics and do not establish service or assembly access. | Recheck full populated boards, axle, bearings, carrier, shell, windows, flex exits, latch access, fasteners and thermal paths through tolerances and travel. Freeze the head outline only then. |

Official basis: [Raspberry Pi sensor assembly drawing](https://datasheets.raspberrypi.com/camera/sensor-assembly-product-brief.pdf), [Mira220](https://ams-osram.com/products/sensor-solutions/cmos-image-sensors/ams-mira220), [AS1170](https://ams-osram.com/products/drivers/led-drivers/ams-as1170-2-channel-led-and-vcsel-driver-ic), [Belago1.2 datasheet](https://look.ams-osram.com/m/4971b838d6356daa/original/Belago1-2-Dot-pattern-infrared-illuminator.pdf). The pulse operating point is a reference condition, not a demonstrated safe product limit.

## 5. How the heads connect, and what is missing

Candidate signal flow, retaining two main-board FPGAs pending the architecture decision:

```text
Face rotating head: RGB + IR + local power/projector/interlock
  ⇅ one engineered dynamic flex ⇅ main J2 → FPGA A → processor CSI receiver A

Interaction rotating head: same carrier design and components
  ⇅ one engineered dynamic flex ⇅ main J3 → FPGA B → processor CSI receiver B

Main → head: switched power, ground, control, clocks, reset/permission
Head → main: RGB/IR image streams, faults/status; timing direction per sensor

Stationary drum-angle sensor + shaft magnet → stationary control harness → main
Motor → motor power/encoder harness → main driver/control
Processor → defined processing/encoding/transport → USB connection → host
```

Each head currently budgets four MIPI data pairs plus two MIPI clock pairs: **six differential pairs**, not four pairs total. They occupy 12 signal contacts, with other contacts allocated to returns, clocks, power and control. Two sensors cannot share an electrical output just because software assigns virtual-channel numbers.

| ID | Finding | Correct response |
| --- | --- | --- |
| I01 | All 51-contact groups lack real pin numbers and verified mating orientation. | Produce an end-to-end connector table: board reference, pad number, signal, voltage, direction, paired return, head pin and flex face. Check mirroring, latch direction, contact staggering and continuity. Use assembly-qualified names such as MAIN:J2 and HEAD_FACE:J1. |
| I02 | The flex is drawn as a round 1.44 mm diameter cable; a 51-position, 0.3 mm interface needs a much broader contact region. | Build the actual flat flexible circuit with specified width, thickness, conductor/reference layers, stiffeners and connector tails. The 50 contact intervals span about 15 mm; a necked flex requires its own routed fan-out and current analysis. |
| I03 | A 3 mm bend-radius number is attached as metadata; the validator does not measure a dynamic flex's surface strain or curvature. | Define a supported flex stack and rolling/service loop; calculate bend/strain limits and test a continuous travel envelope, including twist, length conservation and strain relief. Supplier fatigue data and later cycle tests remain required. |
| I04 | The flex is not attached to a modeled head connector; present sweep validation rotates optics at five angles against shield parts, not a deforming flex against all obstacles. | Add both real mating ends and model movement of the head end. Check shell exits, axle/bearings, gears, motor, shields and supports over the full motion range. Resolve 150° stop versus 160° flex assumptions. |
| I05 | Eight power contacts are assumed sufficient. | Use connector/contact derating, current sharing, flex resistance, voltage drop, ground bounce, sensor startup and pulse-capacitor recharge. FH26 lists 0.2 A/contact; 8 × 0.2 = 1.6 A is only nominal arithmetic, not approved harness current. |
| I06 | MIPI electrical integrity across connectors/flex is unverified. | Define actual transmitter lane rates, impedance, return paths, discontinuities, crosstalk, skew and protection capacitance. Split power/control and camera functions if a single flex cannot meet requirements; then revisit connector area. |
| I07 | Angle ICs U18/U19 are on the main board while Blender separately shows encoder boards/magnets near each drum. The depicted magnet axes are Y; the drums rotate about X. | Choose a coherent stationary sensor/rotating magnet assembly aligned to the measured shaft axis, gap and field. Likely use two small stationary sensor boards; remove duplicate main-board sensor claims and budget their wiring and connectors. |
| I08 | A six-contact motor/encoder connector is not proven to carry motor power, incremental encoder and absolute-angle functions. | Enumerate all wires, supply/return paths and logic levels. Split or enlarge connectors where necessary, and provide suppression/fault feedback. Stationary sensors and motors do not need to burden the rotating optical flex. |

Official basis: [Hirose FH26 catalog](https://www.hirose.com/product/document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) and [AS5600L mounting guide](https://look.ams-osram.com/m/b03a90ea3dea434a/original/AS5600L_UG000345_2-00.pdf). The sensor must see the appropriate centered rotating magnetic field; the current two competing placements do not establish that relationship.
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

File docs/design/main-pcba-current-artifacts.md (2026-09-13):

# DeepReal PCBA - Current Artifact Index

| Field | Value |
| --- | --- |
| Updated | 13 September 2026 |
| Purpose | Separate current engineering inputs from historical visual studies |

## Current engineering inputs

These files should be used for the next schematic and 3D packaging pass:

1. `../electrical/main-pcba-schematic-entry-spec-v0.1.md` - authoritative
   pre-schematic architecture, exact baseline parts, partitions and validation gates.
2. `../electrical/main-pcba-rail-budget-v0.1.csv` - preliminary rail and peak-current
   requirements. Estimated rows must be replaced with measured or calculated values.
3. `../electrical/main-pcba-interface-map-v0.1.csv` - logical interfaces and routing
   classes.
4. `main-pcba-mechanical-bom-v0.2.csv` - historical dimensional and presentation
   metadata. It is no longer an engineering placement authority.
5. `../research/main-pcba-architecture-input-decisions-v0.1.md` - research rationale;
   retained for traceability but superseded where the entry spec differs.
6. `../../hardware/electronics/deepreal-main-pcba/` - current tool-neutral electrical
   capture source: 15-sheet plan, component register, named-net registry, connector
   allocation, circuit requirements and explicit vendor pin-map gates.
7. `../../hardware/electronics/deepreal-optical-head/` - reusable optical-head
   electrical capture source for the two identical rotating carrier assemblies.
8. `../electrical/main-pcba-schematic-capture-status-v0.1.md` - exact record of
   what the capture pass and synchronized Blender rebuild did and did not produce.
9. `../../hardware/electronics/deepreal-main-pcba/deepreal-main-pcba.kicad_pcb` -
   canonical 90 x 28 mm placement board; intentionally contains no decorative copper.
10. `../../hardware/electronics/deepreal-main-pcba/engineering-layout-export.json` -
    deterministic KiCad-to-Blender export containing current components, 2,313 pads,
    holes, and the presently empty real-copper categories.
11. `../../hardware/electronics/deepreal-main-pcba/design-status.json` and
    `engineering-review-manifest.json` - machine-readable gates, ownership, evidence,
    blockers, and publication/fabrication locks.
12. `main-pcba-usb-mechanical-options-v0.1.md` - measured 41.1 mm USB mismatch and
    the three mechanical closure options.

## Removed presentation artifacts

The separate visual KiCad board, handmade copper definitions, visual-board
generators, and superseded PCBA renders were removed from the working tree on
13 September 2026. They did not derive from a complete schematic or netlist and no
longer influence Blender spacing. Git history remains the historical record.

`../../blender/deepreal.blend` remains a generated mechanical/presentation output.
Rebuild it from source; do not treat manual edits as authoritative.

Replacement caption after the engineering release gate: **DeepReal Main PCBA —
engineering development visualization based on a pre-fabrication PCB layout**.
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

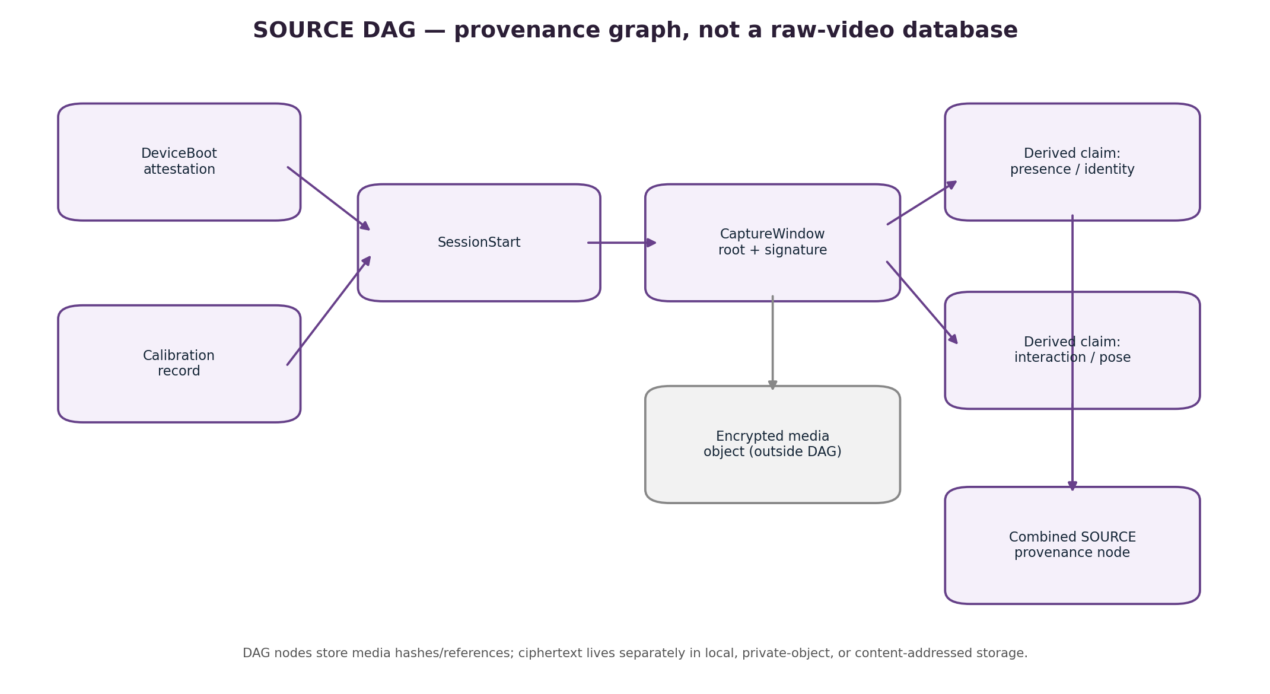
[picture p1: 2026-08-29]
docs/system-architecture/source-provenance-dag.png

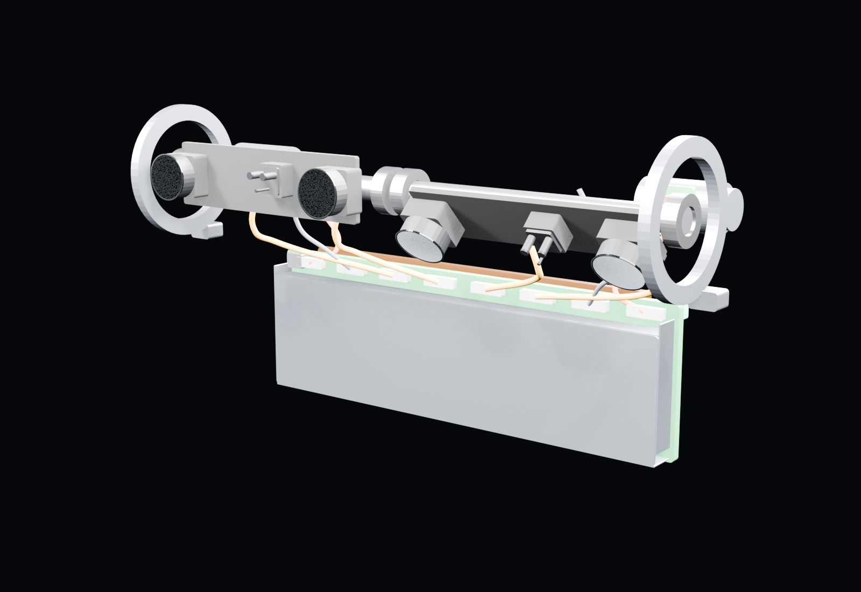
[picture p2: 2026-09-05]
docs/design/blender-functional-core.png

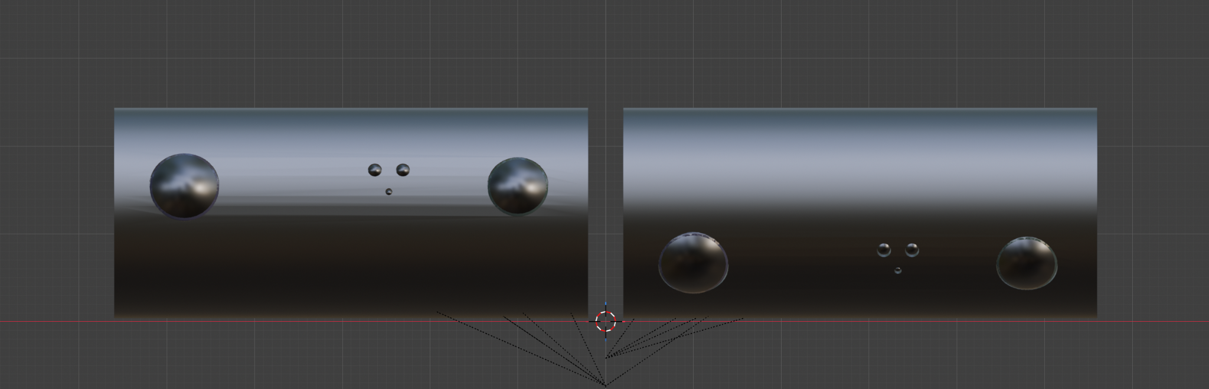
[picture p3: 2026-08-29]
docs/system-architecture/blender-drum-front-views.png

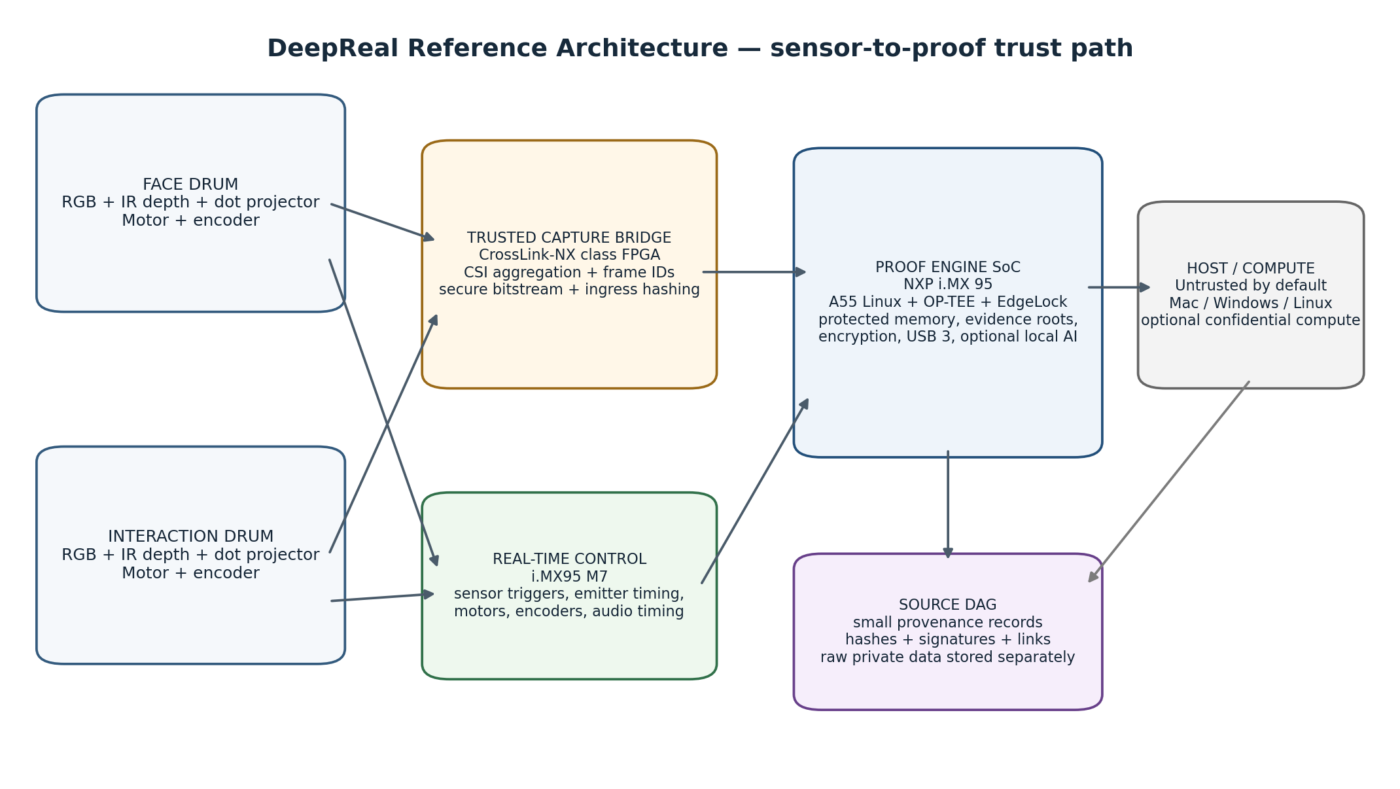
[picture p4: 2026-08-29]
docs/system-architecture/reference-architecture-trust-path.png

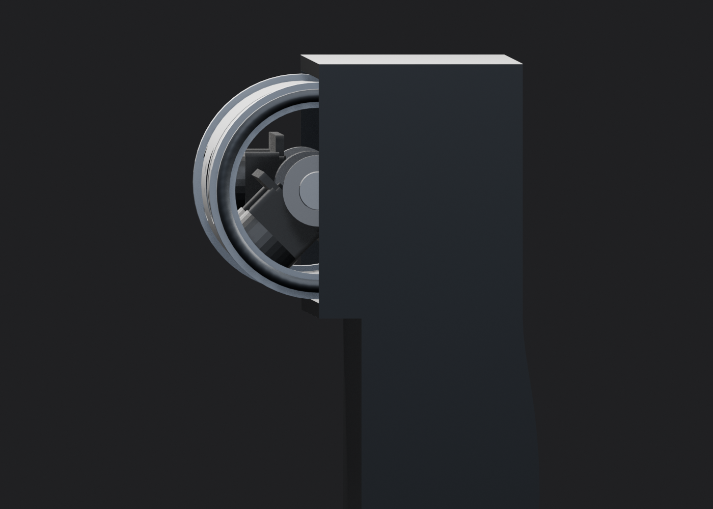
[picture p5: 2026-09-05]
docs/design/blender-reference-profile.png

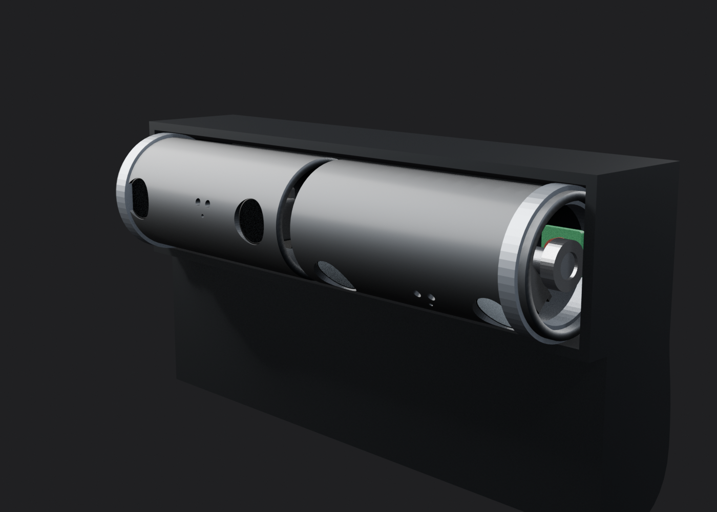
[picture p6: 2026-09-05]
docs/system-architecture/current-blender-reference.png

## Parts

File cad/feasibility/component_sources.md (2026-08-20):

# Component source registry — drum-internals feasibility

Every dimension below comes from the manufacturer source linked in each
section. Nothing is estimated. Where sources disagree, both values are
listed and the envelope uses the conservative one. Machine-readable truth
for the envelope dims lives in `registry.py`; this file is the provenance
record.

Drum constraint used throughout: shell **Ø24 × 54 mm** per drum (positions
from the approved model `cad/deepreal.FCStd` @ dacd90c), assumed usable
interior **Ø21 × 51 mm** (wall 1.5 mm, end caps 1.5 mm — *assumption, not
a design decision*).

Evidence classification (Gate 1.5B):
- **OFFICIAL-VERIFIED** — full 3D dims from an official datasheet /
  drawing / STEP, in hand under `assets/`
- **OFFICIAL-INCOMPLETE** — official document in hand, some envelope dims
  missing from it (gap named)
- **ENGINEERING-ASSUMPTION** — assumed by this study, not sourced; always
  labelled
- **UNRESOLVED** — no official value obtainable (gated / 404);
  placeholder geometry is a lower bound only

Status legend: **candidate** = plausible in-drum · **candidate-borderline**
= only under orientations Gate 2 must verify · **candidate-external** =
cannot enter the drum, housing-mount only · **no-fit-reference** = exceeds
the drum shell, modelled for comparison only · **unresolved-reference** =
official dims unobtainable, lower-bound placeholder ·
**placeholder-assumption** = stand-in for a part class not yet selected.

---

## Gate 1 components (actuators + all-in-one sensors)

### 1. Orbbec Astra Mini Pro — no-fit-reference · OFFICIAL-VERIFIED

- **Function:** structured-light depth + RGB, all-in-one (MX6000 ASIC)
- **Envelope:** 84.90 × 20.00 × 19.92 mm (datasheet; drawing shows ±0.30 / ±0.35 tol)
- **Weight:** 34 g (datasheet v1.0) — web page says 35 g *(disagreement recorded)*
- **Electrical:** USB 2.0, DF13 5-pin (GND/GND/DP/DM/VDD 5 V); <2.4 W (web page)
- **Optical:** SL 855 nm (datasheet) / 850 nm (web page) *(disagreement recorded)*; depth 640×480@30, 0.6–6 m (datasheet) / 0.6–5 m (web); RGB 640×480
- **Sources:** product page https://orbbec3d.com/product-astra-mini-pro/ · datasheet `assets/docs/orbbec-astra-mini-pro-datasheet.pdf` (product drawings p.5: LDM / RGB / IR layout, 2× M2 mounting)
- **CAD:** no official STEP obtained (datasheet drawing only)
- **Fit:** 84.9 mm width vs Ø24 mm drum — **cannot enter the drum.**

### 2. Orbbec Astra Embedded S — no-fit-reference · OFFICIAL-INCOMPLETE

- **Function:** structured-light depth + RGB, all-in-one
- **Envelope:** 69.0 × 22.9 × 15.0 mm (product page)
- **Weight:** 27 g
- **Electrical:** USB 3.0 Type-C, <2.2 W
- **Optical:** 940 nm; depth 1280×800@30, 0.25–1.5 m; RGB 1080p
- **Sources:** product page https://orbbec3d.com/product-astra-embedded-s/
- **CAD:** none downloaded
- **Fit:** 69 mm width vs Ø24 mm drum — **cannot enter the drum.**

### 3. Raspberry Pi Camera Module 3 (standard) — candidate-borderline · OFFICIAL-VERIFIED

- **Function:** RGB camera (Sony IMX708, 11.9 MP, PDAF), CSI-2
- **Envelope:** 25.0 × 24.0 × 11.5 mm (official product page; Wide variant 12.4 mm thick)
- **Drawing detail:** board 25 × 23.862 mm; height stack 11.3 mm (lens 6.98 + 3.875 + FPC 1.12); mount holes 4× Ø2.2; lens Ø5.75; FOV 66°(D)/41°(H per drawing)
- **Electrical:** CSI-2, 15×1 mm FPC (22-pin 0.5 mm at Pi end)
- **Sources:** product page https://www.raspberrypi.com/products/camera-module-3/ · mech drawing `assets/docs/rpi-camera-module-3-standard-mechanical-drawing.pdf` · official STEP `assets/rpi-camera-module-3-step.zip`
- **CAD verification (this study):** `Camera_module_3_std_model_simple.stp` measured **23.862 × 25.000 × 10.245 mm**; wide STEP 23.862 × 25.000 × 11.400 mm (STEPs omit the FPC tail; envelope uses the conservative published 11.5 mm)
- **Fit (Gate 1.5B, validator-verified):** minimum enclosing circle over all axis-aligned orientations = **Ø26.61 mm** (25 axial, 24×11.5 cross) — exceeds even the Ø24 mm shell, before any interior assumption. **No in-drum orientation exists.**

### 4. Pololu 75:1 Micro Metal Gearmotor MP 6V w/ 12 CPR encoder (item 5137) — candidate · OFFICIAL-VERIFIED

- **Function:** DC gearmotor actuator (direct drum drive candidate)
- **Envelope (official STEP, measured):** 41.6 × 14.9 × 13.6 mm — includes Ø3 mm D-shaft (~9.5 mm) and side-entry encoder connector
- **Published dimension PDF:** gearbox cross-section 10 × 12 mm, gearbox length 9 mm, overall length max 32.5 mm **excluding** the shaft
- **Electrical:** 6 V MP brushed motor; 12 CPR magnetic quadrature encoder, JST-SH side connector
- **Sources:** product page https://www.pololu.com/product/5137 · dimension diagram `assets/docs/pololu-5137-dimensions.pdf` · official STEP zip `assets/pololu-micro-metal-gearmotor-step-models.zip` → extracted `assets/pololu-step/With Encoder, Side Connector/mmgm-pm-enc-side-con.step` (75:1 MP = `pm`, non-1000:1 gearbox, per zip README)
- **Fit:** cross-section needs a Ø20.2 mm circle → fits Ø21 mm assumed ID with ~0.4 mm radial margin; 41.6 mm length leaves 9.4 mm of the 51 mm interior for shaft support/wiring — **tight but plausible.**

### 5. T-Motor GB2208 KV128 — no-fit-reference · OFFICIAL-VERIFIED

- **Function:** brushless gimbal motor (direct-drive candidate)
- **Envelope:** Ø27.5 × 23 mm cylinder (spec table); centre hole Ø6 mm
- **Weight:** 39.5 g (incl. 20 cm cable)
- **Electrical:** 3–4S lipo, 12N14P, 14.4 Ω, 0.07 Nm, KV128
- **Sources:** product page https://store.tmotor.com/product/gb2208-gimbal-type.html · technical drawing `assets/docs/tmotor-gb2208-drawing.jpg` (needed browser headers to download)
- **CAD:** no official STEP; a community GrabCAD model exists (third-party, **not used**)
- **Fit:** Ø27.5 mm > Ø24 mm drum shell — **cannot enter the drum.** (Would also need an external ESC + encoder.)

### 6. Robotis DYNAMIXEL XL330-M288-T — candidate-external · OFFICIAL-INCOMPLETE

- **Function:** smart servo (integrated driver + 4096-step absolute magnetic encoder)
- **Envelope:** 20 × 26 × 34 mm (official drawing: depth = 23 body + 3 horn flange)
- **Drawing detail:** horn P.C.D Ø12, 4× Ø1.6 holes (M2 tapping, DP 3.0 max), horn centre 9.5 mm from top edge
- **Weight:** 18 g
- **Electrical:** 5 V, TTL bus (3.3/5 V logic), stall 0.52 Nm, no-load 104 rpm
- **Sources:** eManual https://emanual.robotis.com/docs/en/dxl/x/xl330-m288/ · store page https://www.robotis.us/dynamixel-xl330-m288-t/ · drawing `assets/docs/robotis-xl330-m288-drawing.png`
- **CAD:** **UNRESOLVED** — official STEP/drawing links (download.php no=1985/1986/1987) 404 on both www.robotis.com and en.robotis.com; envelope is from the official drawing only
- **Fit:** smallest face (20×26) needs a Ø32.8 mm circle > Ø21 mm assumed ID — **cannot enter the drum**; external housing-mount drive only.

---

## Gate 1.5B components (discrete depth architecture)

### 7. Raspberry Pi CM3 Sensor Assembly (standard lens) — candidate · OFFICIAL-VERIFIED

**Replaces the full CM3 board as the in-drum RGB option.**

- **Function:** bare RGB sensor + lens sub-assembly (remote head off the CM3 board; IMX708, 11.9 MP, PDAF)
- **Footprint:** **10.8 × 10.8 mm ±0.15** (TNBA1392 REV 0 key dims, CPK ≥ 1.33)
- **Depth (optical stack):** **6.98 mm** per product brief p.4 — *discrepancy recorded:* TNBA1392 side view says **6.21 ±0.15 at 10 cm focus / 5.97 ±0.15 at infinity** (AF moves the lens); body height 3.875 ±0.15 matches both sources. Envelope uses the conservative brief value 6.98.
- **Side-view stack (TNBA1392):** 0.4 ±0.05 PCB + 0.15 AA glue + 3.875 ±0.15 body + lens protrusion; reinforcing glue max 0.8×0.8; FPC+EMI 0.13 ±0.05; tail PCB+ink 0.45 ±0.05
- **Lens:** Ø5.75 (std) / Ø6.95 (wide, depth 8.3); FOV 75° ±3 diagonal / 66° H / 41° V; EFL 4.74 mm F1.79 (brief rounds F1.8); image circle Ø8.4 mm; focus 10 cm–∞ (wide 5 cm–∞)
- **FPC tail:** 8.9 ±0.15 wide, extends 4.0 ±0.15 beyond body edge; bend area 7 ±0.15 wide; **bends 180° × 20 cycles at R = 0.8 mm** (TNBA1392 technical requirement 3); MIPI impedance 100 ±10 Ω; far-end connector HLM-033M-3002-76 (30-pin, 4.45 wide, 1.3 ref thick)
- **Electrical:** DVDD 1.1 V / AVDD 2.8 V / DOVDD 1.8 V; VCM driver DW9800W (I2C 0x18); EEPROM BL24SA64D-CS (0xA0); PWDN low-effective
- **Variants:** SA31VA30P std / SA31NA30P std-NoIR / SA36VA30P wide / SA36NA30P wide-NoIR, $15–25, in production until ≥ Jan 2030
- **Sources:** product brief `assets/docs/rpi-camera-module-3-sensor-assembly-product-brief.pdf` (physical spec p.4, variants p.5) · standard datasheet `assets/docs/rpi-camera-module-3-sensor-assembly-standard-datasheet.pdf` (TNBA1392 REV 0, TSP / Chongqing TS-Precision, single-page drawing)
- **CAD:** none published; multi-part envelope built from TNBA1392 by this study (lens / body / PCB / FPC-tail parts)
- **Fit (Gate 1.5B, validator-verified):** best enclosing circle **Ø12.9 mm** (10.8 axial) ≤ Ø21 assumed ID; radial-optical placement verified collision-free and contained in layouts SL-A / SL-B.

### 8. OmniVision OV9281 (OV09281-H64A) — candidate · OFFICIAL-INCOMPLETE

**Grounds the structured-light IR camera in a manufacturer document.**

- **Function:** global-shutter NIR camera die (structured-light receiver)
- **Official (product brief v1.4, May 2024):** 1280×800 @ 120 fps max; global shutter, OmniPixel3-GS, 3 µm pixel; **image area 3896 × 2453 µm**; CRA 9° linear; 1/4" optical format; 2-lane MIPI + DVP; 8/10-bit RAW; 2.8/1.2/1.8 V rails; 156 mW active; −30..+85 °C operating; **64-pin CSP** (ordering code OV09281-H64A)
- **UNRESOLVED:** CSP package body X/Y/Z — not in the product brief; the full OV9281 datasheet with the package outline is NDA-gated at OmniVision. Die thickness in the envelope (1.5 mm) is an **ENGINEERING-ASSUMPTION**; the Ø6 × 4 mm lens barrel is an **ENGINEERING-ASSUMPTION** allowance (no lens sourced; CRA 9° is the only official optical constraint)
- **DEMOTED (unsourced):** the earlier "8 × 8 × 5.8 mm" OV9281 module-class figure carried in discussion has no manufacturer source and is removed from the envelopes; the official anchor is the image area 3.896 × 2.453 mm + CSP package type
- **Module alternative ruled out:** Arducam OV9281 board 24 × 25 mm → minimum enclosing circle ≈ Ø34.7 mm > Ø21 mm assumed ID — cannot enter the drum; bare-sensor integration is the only in-drum path
- **Sources:** `assets/docs/omnivision-ov9281-product-brief.pdf`
- **Fit:** modelled in layouts SL-A / SL-B (die + lens allowance); contained with margin.

### 9. ams OSRAM BELICE-850 — candidate · OFFICIAL-VERIFIED

- **Function:** 850 nm dot-projector VCSEL module for structured light (~10k dots per emitter pair)
- **Envelope:** **3.50 ±0.15 × 3.40 ±0.15 × 3.56 ±0.1 mm** (datasheet fig. 11 top view, fig. 12 side view incl. 0.25 mm step feature)
- **Optical aperture:** 2.3 × 2.3 mm, corner R0.1 (fig. 13)
- **Bottom pads:** 2.80 ±0.1 × 2.80 ±0.1 mm field; pads 0.50 / 2.05 / 0.25 / 0.30 ±0.1; fiducials 2× Ø0.20; corner radii 4× R0.70
- **Sources:** `assets/docs/ams-belice-850-datasheet.pdf` (DS000618 v2-00, 2019-May-15, 23 pp)
- **CAD:** none published; envelope from the datasheet drawings
- **Integration:** SMT module — needs carrier PCB + VCSEL driver (not included); used as the projector in layout **SL-A**
- **Fit:** contained in layouts with large margin.

### 10. ams OSRAM Belago1.2 — candidate · OFFICIAL-VERIFIED

- **Function:** 940 nm pseudo-random dot projector, ~15k dots, with resistive-ITO eye-safety interlock
- **Envelope:** **4.200 ±0.075 × 3.900 ±0.050 × 3.325 ±0.050 mm** (datasheet fig. 6: top view / front view height)
- **Optical aperture / MLA active area:** 2.0 ±0.1 square, corner radii 4× R0.750; FOI orientation marked on package (fig. 11)
- **Pads (bottom view):** Anode(+) / Cathode / Sense1 / Sense2; pad dims 0.550 / 0.950 / 2.050 / 0.250 ±0.100 etc.; pin-compatible with Belago1.1
- **Drive:** ~0.7 A pulse class (fig. 4 @ 25 °C, Ti = 1 ms, 30 fps); MSL3, peak reflow 250 °C; ventilation hole present; **must not be ultrasonically cleaned**
- **Eye safety:** every emitter hotspot-inspected in production; Sense1/Sense2 open on ITO fracture → driver must cut power (needs driver-side support)
- **Ordering:** AQAA-30 / Q65114A0198
- **Sources:** `assets/docs/ams-belago1-2-datasheet.pdf` (DS001002 v1-00, 2025-Apr-22, 19 pp)
- **CAD:** none published; envelope from the datasheet drawings
- **Fit:** modelled as the projector in layout **SL-B**; contained (station-2 Z stack gap to the OV9281 lens allowance ≈ 0.45 mm — flagged).

### 11. Infineon IRS2877A / IRS2877AS — candidate · OFFICIAL-VERIFIED

- **Function:** indirect-ToF depth imager die (REAL3), 640×480 (~307k px, upscaled output), 940 nm
- **Package (PG-LFBGA-65-1):** body **9.0 ±0.1 × 9.0 ±0.1 mm**, height **1.325 ±0.14 (max 1.465)**; ball Ø0.42, pitch 0.8, 65 balls, standoff min 0.25; sensor/lens area 4.6 ±0.05 × 4.9 ±0.05 with centre offset; 4 mm image circle (1/4" class)
- **STEP verification (this study):** official STEP `assets/step/infineon-pg-lfbga-65-1-3d.stp` probed — union bounds **9.000 × 9.000 × 1.465 mm** = outline max tolerance exactly; 168 solids (body 9×9×0.915 cap + substrate + balls)
- **Variants:** IRS2877A (AEC-Q100 grade 2) / IRS2877AS (adds ISO 26262 ASIL-D)
- **Electrical:** 1.8 V / 3.3 V rails; **companion controller IRS9103A mandatory**
- **FULL-STACK RESERVATION:** the envelope is the imager die (+ Ø6 × 4 mm lens allowance, ENGINEERING-ASSUMPTION). A working ToF camera additionally needs: receiving lens (unsourced), flood-illumination VCSEL + driver (unsourced — placeholder modelled), IRS9103A companion + passives + carrier PCB (keep-out modelled, dims assumed), host interface. iToF at 940 nm gives depth + active-amplitude simultaneously; sunlight robustness per brief.
- **Sources:** `assets/docs/infineon-irs2877as-product-brief.pdf` · `assets/docs/infineon-pg-lfbga-65-1-package-outline.pdf` · `assets/step/infineon-pg-lfbga-65-1-3d.stp`
- **Fit:** modelled in layout **ToF-A**; contained with margin.

### 12. Infineon IRS2976C — unresolved-reference · UNRESOLVED

- **Function:** indirect-ToF depth imager bare die, 640×480, 940 nm, 1/4" (4 mm) image circle; companion IRS9102C
- **UNRESOLVED:** die dimensions are behind the MyInfineon portal (gated) — not obtained. Modelled geometry = Ø4.0 × 0.5 mm disc = **the official 4 mm image circle as a lower-bound footprint only**; a real die + WLO/wire-bond stack is larger
- **Not carried into layouts.** Same full-stack reservations as IRS2877A, plus chip-on-board handling would be an in-house packaging burden
- **Sources:** family reference `assets/docs/infineon-irs2877as-product-brief.pdf`

### 13. ToF flood-illuminator placeholder — placeholder-assumption · ENGINEERING-ASSUMPTION

- **Function:** stand-in for the 940 nm flood VCSEL every iToF camera needs
- **Envelope:** 3.50 × 3.40 × 3.56 mm, borrowed from BELICE-850 (OFFICIAL for BELICE-850) as representative of the SMT VCSEL module class
- **No part selected.** Gate 2 candidates: ams OSRAM TARA2000-AUT class flood illuminators; must pair with the eye-safety drive scheme.

---

## Preliminary no-fit / fit summary

| Component | Envelope (mm) | vs Ø24 drum (Ø21 assumed ID) | Evidence | Status |
|---|---|---|---|---|
| RPi CM3 Sensor Assembly | 10.8×10.8×6.98 (+FPC tail) | fits; layouts SL-A/SL-B verified | OFFICIAL-VERIFIED | candidate |
| OmniVision OV9281 (bare) | die 3.9×2.5 (+lens allowance Ø6×4) | fits; pkg dims UNRESOLVED | OFFICIAL-INCOMPLETE | candidate |
| ams BELICE-850 | 3.50×3.40×3.56 | fits | OFFICIAL-VERIFIED | candidate |
| ams Belago1.2 | 4.20×3.90×3.325 | fits (SL-B station-2 gap 0.45 mm) | OFFICIAL-VERIFIED | candidate |
| Infineon IRS2877A(S) | 9.0×9.0×1.465 (+lens allowance) | fits; full-stack reservations | OFFICIAL-VERIFIED | candidate |
| Infineon IRS2976C | Ø4.0 lower bound only | die dims UNRESOLVED (gated) | UNRESOLVED | unresolved-reference |
| ToF illuminator placeholder | 3.50×3.40×3.56 (borrowed) | fits | ENGINEERING-ASSUMPTION | placeholder-assumption |
| Pololu 5137 gearmotor | 41.6×14.9×13.6 | cross-section Ø20.2 fits; length tight | OFFICIAL-VERIFIED | candidate |
| RPi Camera Module 3 (board) | 25×24×11.5 | min enclosing Ø26.6 > Ø24 shell — **no in-drum orientation** | OFFICIAL-VERIFIED | candidate-borderline |
| DYNAMIXEL XL330-M288 | 20×26×34 | min circle Ø32.8 — cannot enter | OFFICIAL-INCOMPLETE | candidate-external |
| Orbbec Astra Mini Pro | 84.9×20×19.92 | exceeds shell outright | OFFICIAL-VERIFIED | no-fit-reference |
| Orbbec Astra Embedded S | 69×22.9×15 | exceeds shell outright | OFFICIAL-INCOMPLETE | no-fit-reference |
| T-Motor GB2208 | Ø27.5×23 | exceeds shell outright | OFFICIAL-VERIFIED | no-fit-reference |

**Structured-light depth:** no commercial all-in-one SL module (Orbbec
84.9/69 mm wide) fits a Ø24 mm drum. The discrete architecture
(CM3 Sensor Assembly + OV9281 bare sensor + BELICE-850/Belago1.2
projector) is modelled and validated in layouts SL-A / SL-B
(`depth_architecture_report.md`).

**Time-of-flight depth:** IRS2877A + illuminator placeholder + carrier
keep-out fit easily (ToF-A), but the full stack has unsourced elements
(lens, illuminator, companion board) — see the report's reservation list.

**Wiring across the rotating joint** (140–160° travel): unresolved —
capsule slip ring vs flex loop trade-off not yet researched (G10 group
empty).

**Bearings/supports:** not yet researched (G09 group empty).

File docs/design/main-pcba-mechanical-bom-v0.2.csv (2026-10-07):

Ref | Function | Candidate | Package | Body_mm | Side | Status | Geometry_source
U1 | Application processor | NXP MIMX9596CVTXNAC | FC-PBGA-548 SOT2251-1 | 15.0x15.0x1.584_max | Top | BASELINE | NXP IMX95IEC Rev 8
U2 | Face camera aggregation | Lattice LIFCL-17 | 121-ball csfBGA | 6.0x6.0x1.0 | Top | COMPILE_REQUIRED | Lattice CrossLink-NX selection table
U3 | Interaction camera aggregation | Lattice LIFCL-17 | 121-ball csfBGA | 6.0x6.0x1.0 | Top | COMPILE_REQUIRED | Lattice CrossLink-NX selection table
U4 | 4 GB LPDDR4X | Micron MT53E1G32D2FW-046 AAT:B | 200-ball TFBGA | 10.0x14.5x1.1 | Top | NXP_VALIDATION_REQUIRED | Micron production catalog
U5 | System PMIC | NXP MPF0900AVNA2ES | HVQFN56 | 8.0x8.0x0.53 | Top | BASELINE | NXP PF09 Rev 1.3
U6 | SoC core regulator | NXP MPF5302BVNAAEP | H-FC-PQFN24 | 3.5x4.5x0.75 | Top | BASELINE | NXP PF53 ordering table
U7 | CPU core regulator | NXP MPF5301BVNABEP | H-FC-PQFN24 | 3.5x4.5x0.75 | Top | BASELINE | NXP PF53 ordering table
U8 | 5 V system buck | TI TPS56637RPAR | VQFN-HR10 RPA | 3.0x3.0x1.0 | Top | THERMAL_REVIEW | TI TPS56637 product data
U9 | 6 V motor buck | TI TPS56637RPAR | VQFN-HR10 RPA | 3.0x3.0x1.0 | Top | THERMAL_REVIEW | TI TPS56637 product data
U10 | VBUS protection | TI TPS259472LRPWR | WQFN10 RPW | 2.0x2.0x0.8 | Top | BASELINE | TI TPS25947 product data
U11 | USB-PD controller | Infineon CYPD3177-24LQXQ | QFN24 | 4.0x4.0x0.6 | Top | BASELINE | Infineon datasheet
U12 | USB orientation mux | TI HD3SS3212IRKSR | VQFN20 RKS | 2.5x4.5x1.0 | Bottom | BASELINE | TI product data
U13 | Face motor driver | TI DRV8213RTER | WQFN16 RTE | 3.0x3.0x0.8 | Bottom | BASELINE | TI product data
U14 | Interaction motor driver | TI DRV8213RTER | WQFN16 RTE | 3.0x3.0x0.8 | Bottom | BASELINE | TI product data
U15 | 32 GB eMMC | Micron MTFC32GBCAQTC-AAT | 153-ball BGA | 11.5x13.0x1.3 | Bottom | BASELINE | Micron production catalog
U16 | Board identity EEPROM | Microchip AT24C64D-MAHM-T | UDFN8 | 2.0x3.0x0.6 | Bottom | BASELINE | Microchip production catalog
U17 | Sensor clock buffer | TI LMK1C1104DQFR | WSON8 DQF | 2.0x2.0x0.8 | Bottom | BASELINE | TI product data
U18 | Face absolute drum angle | AS5600L-AWLM | WLCSP15 | 2.07x2.63x0.6 | Top | SUPPLY_RECHECK | AS5600L datasheet
U19 | Interaction absolute drum angle | AS5600L-AWLM | WLCSP15 | 2.07x2.63x0.6 | Top | SUPPLY_RECHECK | AS5600L datasheet
U20 | Main board temperature | TI TMP117AIDRVR | WSON6 DRV | 2.0x2.0x0.8 | Top | BASELINE | TI product data
MK1 | PDM microphone | TDK MMICT3902-00-012 | Bottom-port LGA | 3.5x2.65x0.98 | Bottom | BASELINE | TDK product data
SW1 | Case-open tamper | Omron D3SK-B1R | Surface-mount NC detector | 3.0x3.5x0.9 | Top | MECHANICAL_GATE | Omron product data
D1 | USB SuperSpeed ESD | TI TPD4EUSB30DQAR | USON10 DQA | 2.5x1.0x0.55 | Bottom | SI_REVIEW | TI product data
D2 | USB 2 ESD | TI TPD2EUSB30ADRTR | SOT-9X3 DRT | 1.0x1.0x0.6 | Bottom | SI_REVIEW | TI product data
D3-D8 | Drum MIPI ESD | 6 x TI TPD4E05U06DQAR | USON10 DQA | 2.5x1.0x0.55 | Top | SI_REVIEW | Three arrays at each drum connector
D9 | VBUS transient suppressor | TBD | Low-profile TVS | 3.0x2.0x1.0 | Top | SELECTION_REQUIRED | Choose from surge requirement
J1 | USB-C power and data | Hirose CX90M3-24P | Mid-mount USB Type-C | 7.85x12.0x3.16 | Top | BASELINE | Hirose STEP and drawing
J2 | Face optical-head flex | Hirose FH26W-51S-0.3SHW(97) | 0.3 mm FPC 51 pos | 15.6x3.2x1.0 | Top | FLEX_SI_GATE | Hirose FH26 catalog
J3 | Interaction optical-head flex | Hirose FH26W-51S-0.3SHW(97) | 0.3 mm FPC 51 pos | 15.6x3.2x1.0 | Top | FLEX_SI_GATE | Hirose FH26 catalog
J4 | Face motor/encoder | TBD | 6-position low-profile | 5.0x2.6x1.2 | Top | RESERVED | Function envelope
J5 | Interaction motor/encoder | TBD | 6-position low-profile | 5.0x2.6x1.2 | Top | RESERVED | Function envelope
H1 | Face head carrier | SA31VA30P + Mira220 + AS1170 + Belago1.2 + local rails | Custom rigid-flex | OPEN | Rotating | HEAD_PCB_REQUIRED | Subsystem partition decision
H2 | Interaction head carrier | SA36VA30P wide + Mira220 + AS1170 + Belago1.2 + local rails | Custom rigid-flex | OPEN | Rotating | HEAD_PCB_REQUIRED | Wide lens optical target; shared carrier and window fit unverified

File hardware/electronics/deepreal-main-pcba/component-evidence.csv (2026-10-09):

Ref | Selected_part | Required_evidence | Current_evidence | Audit_state | Blocking_issue
U1 | NXP MIMX9596CVTXNAC | 548-ball pin list; hardware guide; land pattern; 3D | IMX95IEC Rev 8 identified | PINMAP_REQUIRED | Current KiCad footprint is a generic 324-ball BGA
U2-U3 | Lattice LIFCL-17 csfBGA121 | FPGA-SC-02006 pinout; package drawing; Radiant assignment | Official pinout and family data identified | COMPILE_REQUIRED | Legal DeepReal MIPI assignment not compiled
U4 | Micron MT53E1G32D2FW-046 AAT:B | 200-ball pin map; land pattern; NXP DDR configuration | Production part identified | DDR_GATE | Pin map and NXP DDR-tool output not audited
U5 | NXP MPF0900AVNA2ES | Official symbol; HVQFN56 land pattern; OTP/sequence | PF09 data source identified | REVIEW_REQUIRED | Rail allocation and OTP not approved
U6 | NXP MPF5302BVNAAEP | Official symbol; H-FC-PQFN24 land pattern; reference circuit | PF53 source identified | FOOTPRINT_MISMATCH | Current KiCad proxy is 4 x 4 mm instead of 3.5 x 4.5 mm
U7 | NXP MPF5301BVNABEP | Official symbol; H-FC-PQFN24 land pattern; reference circuit | PF53 source identified | FOOTPRINT_MISMATCH | Current KiCad proxy is 4 x 4 mm instead of 3.5 x 4.5 mm
U8-U9 | TI TPS56637RPAR | RPA land pattern; reference design; inductor/compensation calculations | TI product source identified | CALC_REQUIRED | Current proxy does not prove RPA pad geometry or power loop
U10 | TI TPS259472LRPWR | RPW land pattern; ILIM/dVdt/IMON calculations | TI product source identified | REVIEW_REQUIRED | Exact support network not captured
U11 | Infineon CYPD3177-24LQXQ | QFN24 land pattern; BCR configuration; reference design | Infineon datasheet identified | REVIEW_REQUIRED | PD configuration and HPI circuit not captured
U12 | TI HD3SS3212IRKSR | RKS land pattern; USB routing reference | TI product source identified | REVIEW_REQUIRED | Exact pad mapping and USB topology not captured
U13-U14 | TI DRV8213RTER | RTE land pattern; current/stall calculations | TI product source identified | REVIEW_REQUIRED | Current limit and motor interface not captured
U15 | Micron MTFC32GBCAQTC-AAT | 153-ball pin map; land pattern; boot guidance | Production part identified | PINMAP_REQUIRED | Official pin map not audited
U16 | Microchip AT24C64D-MAHM-T | MAHM land pattern and pin audit | Product source identified | REVIEW_REQUIRED | Generic DFN proxy needs audit
U17 | TI LMK1C1104DQFR | DQF land pattern; clock/jitter requirements | Product source identified | REVIEW_REQUIRED | RGB-only candidate; 38.4MHz IR source/distribution requires separate architecture closure
U18-U19 | ams OSRAM AS5600L-AWLM | 15-ball pin map and WLCSP land pattern | Datasheet source identified | FOOTPRINT_MISMATCH | Current KiCad proxy is a 16-ball WLCSP; R21 cheek-board location conflicts with main-board placement (CR-006)
U20 | TI TMP117AIDRVR | DRV land pattern and address audit | Product source identified | REVIEW_REQUIRED | Generic WSON proxy needs pad audit
U21-U22 | TBD head load switch/current monitor | Part selection; protection; current monitor range | None | SELECTION_REQUIRED | No selected device
MK1 | TDK MMICT3902-00-012 | Exact LGA land pattern; acoustic application note | Product source identified | ACOUSTIC_REVIEW | Port and keep-out not captured in KiCad
D1 | TI TPD4EUSB30DQAR | DQA land pattern; USB SI model | Product source identified | SI_REVIEW | Placement and return-via structure unproven
D2 | TI TPD2EUSB30ADRTR | DRT SOT-9X3 land pattern; USB SI model | Product source identified | FOOTPRINT_MISMATCH | Current KiCad proxy is USON-10
D3-D8 | TI TPD4E05U06DQAR | DQA land pattern; MIPI capacitance/SI review | Product source identified | SI_REVIEW | Not represented as registered exact footprints
D9 | TBD low-profile VBUS TVS | Part selection; surge rating; package | None | SELECTION_REQUIRED | Current SMA proxy is not a selected part
J1 | Hirose CX90M3-24P | Official drawing; exact land pattern; STEP; shell strategy; supported PCB thickness | Official product record and STEP available | MECHANICAL_CONFLICT | Current KiCad uses an Amphenol footprint; selected Hirose lists 0.8 mm max recommended PCB thickness versus the 1.6 mm board
J2-J3 | Hirose FH26W-51S-0.3SHW(97) | Official drawing; pad numbering; mating orientation; flex continuity | Catalog body and copper dimension subset screened; see head-interface-evidence.json | ORIENTATION_REQUIRED | 16.8mm body versus 15.6mm FPC end; numbering paste orientation current sharing and dynamic flex remain open
J4-J5 | TBD 6-position motor/encoder connector | Exact part; mating system; land pattern | None | SELECTION_REQUIRED | Generic pin-header proxy only
SW1 | Omron D3SK-B1R | Exact actuator drawing; land pattern; tolerance | Product source identified | MECHANICAL_REVIEW | Actuation direction not reconciled with enclosure
Y1-Y2 | TBD system/RGB oscillators | Part selection; jitter; startup; land pattern | None | SELECTION_REQUIRED | No selected devices; additional 38.4MHz IR source/distribution is unallocated
J6 | TBD debug/recovery interface | Signal set; connector/pad selection; access envelope | None | SELECTION_REQUIRED | No selected interface
TP1-TP32 | TBD test points | DFT access list; pad geometry; probe clearance | None | DFT_REQUIRED | Current visual pads are illustrative

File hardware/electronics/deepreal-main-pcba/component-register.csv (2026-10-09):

Ref | Function | Selected_part | Side | Package_status | Support_population | Electrical_state
J1 | USB-C receptacle | Hirose CX90M3-24P | Top | MECHANICAL_CONFLICT | shell bonds; CC and data protection | BLOCKED
U10 | VBUS eFuse | TI TPS259472LRPWR | Top | VERIFY_LAND_PATTERN | ILIM; dVdt; IMON; bypass caps | DEFINED
U11 | USB-PD sink | Infineon CYPD3177-24LQXQ | Top | VERIFY_LAND_PATTERN | CC network; configuration; HPI; decoupling | DEFINED
D1 | USB SuperSpeed ESD | TI TPD4EUSB30DQAR | Bottom | SI_REVIEW | ground vias at device | DEFINED
D2 | USB 2 ESD | TI TPD2EUSB30ADRTR | Bottom | SI_REVIEW | ground vias at device | DEFINED
D9 | VBUS TVS | TBD low-profile TVS | Top | SELECTION_REQUIRED | surge return path | OPEN
U12 | USB orientation mux | TI HD3SS3212IRKSR | Bottom | VERIFY_LAND_PATTERN | bias and decoupling | DEFINED
U8 | System 5V buck | TI TPS56637RPAR | Top | VERIFY_LAND_PATTERN | L1; input/output ceramics; feedback; bootstrap | CALC_REQUIRED
U9 | Motor 6V buck | TI TPS56637RPAR | Top | VERIFY_LAND_PATTERN | L2; input/output ceramics; feedback; bootstrap | CALC_REQUIRED
U5 | System PMIC | NXP MPF0900AVNA2ES | Top | SOURCE_IDENTIFIED | L5-L9; rail capacitors; sequence/control | PINMAP_REVIEW
U6 | SoC regulator | NXP MPF5302BVNAAEP | Top | SOURCE_IDENTIFIED | L3; input/output ceramics; sense/compensation | PINMAP_REVIEW
U7 | CPU regulator | NXP MPF5301BVNABEP | Top | SOURCE_IDENTIFIED | L4; input/output ceramics; sense/compensation | PINMAP_REVIEW
U1 | Application processor | NXP MIMX9596CVTXNAC | Top | OFFICIAL_SYMBOL_REQUIRED | C120-C219 provisional decoupling field | TBD_PINMAP
U4 | 4GB LPDDR4X | Micron MT53E1G32D2FW-046 AAT:B | Top | OFFICIAL_SYMBOL_REQUIRED | C220-C259 provisional decoupling/termination | DDR_GATE
U15 | 32GB eMMC | Micron MTFC32GBCAQTC-AAT | Bottom | OFFICIAL_SYMBOL_REQUIRED | local decoupling; CLK damping option | TBD_PINMAP
U2 | Face camera bridge | Lattice LIFCL-17 csfBGA121 | Top | COMPILE_REQUIRED | core regulator; bank caps; config pulls | FPGA_GATE
U3 | Interaction camera bridge | Lattice LIFCL-17 csfBGA121 | Top | COMPILE_REQUIRED | core regulator; bank caps; config pulls | FPGA_GATE
D3-D5 | Face MIPI ESD | 3x TI TPD4E05U06DQAR | Top | SI_REVIEW | six differential pairs protected | FLEX_GATE
D6-D8 | Interaction MIPI ESD | 3x TI TPD4E05U06DQAR | Top | SI_REVIEW | six differential pairs protected | FLEX_GATE
J2 | Face optical-head flex | Hirose FH26W-51S-0.3SHW(97) | Top | ORIENTATION_REQUIRED | power filtering; sideband filtering | FLEX_GATE
J3 | Interaction optical-head flex | Hirose FH26W-51S-0.3SHW(97) | Top | ORIENTATION_REQUIRED | power filtering; sideband filtering | FLEX_GATE
U21 | Face head load switch/current monitor | TBD | Top | SELECTION_REQUIRED | input/output caps; discharge; fault pull | OPEN
U22 | Interaction head load switch/current monitor | TBD | Top | SELECTION_REQUIRED | input/output caps; discharge; fault pull | OPEN
U13 | Face motor driver | TI DRV8213RTER | Bottom | VERIFY_LAND_PATTERN | bulk cap; charge pump; IPROPI set; filters | DEFINED
U14 | Interaction motor driver | TI DRV8213RTER | Bottom | VERIFY_LAND_PATTERN | bulk cap; charge pump; IPROPI set; filters | DEFINED
J4 | Face motor/encoder | TBD 6-position | Top | SELECTION_REQUIRED | motor/encoder ESD and filters | OPEN
J5 | Interaction motor/encoder | TBD 6-position | Top | SELECTION_REQUIRED | motor/encoder ESD and filters | OPEN
U18 | Face absolute angle | ams OSRAM AS5600L-AWLM | Top | ORDER_CODE_RECHECK | R21 fixed cheek-board location conflicts with current main-board Top placement; verify magnet gap and add fixed harness; local decoupling; address programming pads | LOCATION_BLOCKED
U19 | Interaction absolute angle | ams OSRAM AS5600L-AWLM | Top | ORDER_CODE_RECHECK | R21 fixed cheek-board location conflicts with current main-board Top placement; verify magnet gap and add fixed harness; local decoupling; address programming pads | LOCATION_BLOCKED
Y1 | iMX95 reference oscillator | TBD 24MHz | Top | SELECTION_REQUIRED | enable/reset timing network | OPEN
Y2 | RGB reference oscillator candidate | TBD 24MHz | Bottom | SELECTION_REQUIRED | RGB only; separate 38.4MHz IR clock architecture remains open | OPEN
U17 | RGB clock buffer candidate | TI LMK1C1104DQFR | Bottom | VERIFY_LAND_PATTERN | Not a common 24MHz RGB/IR source; output allocation and levels open | CLOCK_GATE
U16 | Board identity EEPROM | Microchip AT24C64D-MAHM-T | Bottom | VERIFY_LAND_PATTERN | address pulls; write protect; decoupling | DEFINED
U20 | Board temperature | TI TMP117AIDRVR | Top | VERIFY_LAND_PATTERN | address pull; alert pull-up; decoupling | DEFINED
MK1 | PDM microphone | TDK MMICT3902-00-012 | Bottom | ACOUSTIC_LAYOUT_REQUIRED | supply filter; clock/data damping | DEFINED
SW1 | Case-open tamper | Omron D3SK-B1R | Top | MECHANICAL_ORIENTATION_REQUIRED | debounce; bias; ESD | DEFINED
J6 | Debug/recovery/test | TBD compact pads/connector | Bottom | SELECTION_REQUIRED | series isolation; no production cable dependency | OPEN
TP1-TP32 | Manufacturing test points | TBD | Bottom | DFT_REQUIRED | power/reset/programming/critical sideband access | OPEN
C1-C119 | Input/power/support passives | TBD | Two-sided | CALC_REQUIRED | USB; bucks; PMIC/PF53; head filters | IN_PROGRESS
C120-C219 | iMX95 decoupling field | TBD | Two-sided | PINMAP_REQUIRED | rail-specific values and placement | TBD_PINMAP
C220-C259 | LPDDR4X support | TBD | Two-sided | DDR_TOOL_REQUIRED | rail caps and optional damping | DDR_GATE
C260-C319 | FPGA/head-interface support | TBD | Two-sided | COMPILE_AND_SI_REQUIRED | bank caps; local rails; filtering | IN_PROGRESS
C320-C359 | Motor/audio/misc support | TBD | Two-sided | CIRCUIT_CALC_REQUIRED | bulk; charge pump; filters; debounce | IN_PROGRESS
R1-R39 | USB/power programming | TBD | Two-sided | CIRCUIT_CALC_REQUIRED | CC/configuration/feedback/limits | IN_PROGRESS
R40-R89 | compute/memory straps | TBD | Two-sided | PINMAP_REQUIRED | boot/config/series options | TBD_PINMAP
R90-R139 | FPGA/head sideband | TBD | Two-sided | COMPILE_REQUIRED | configuration/translation/filtering | IN_PROGRESS

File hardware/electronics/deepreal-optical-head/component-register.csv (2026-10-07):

Ref | Function | Selected_part | Package | Support_population | State
S1 | RGB camera sensor assembly | Face SA31VA30P / interaction SA36VA30P wide | 10.8x10.8mm assembly | 30-pin board connector; local rail filtering; verify wide variant pinout and autofocus load | VARIANT_COMPATIBILITY_GATE
S2 | IR global-shutter sensor | ams OSRAM Mira220 Q65114A0087 | 5.4x5.4mm CSP | bias resistor; sequenced rails; output caps | PINMAP_SOURCE_IDENTIFIED
P1 | 940nm dot projector | ams OSRAM Belago1.2 Q65114A0198 | 4.2x3.6x3.325mm | Sense1/Sense2 lens loop; pulse path | SAFETY_GATE
U1 | Projector driver | ams OSRAM AS1170 Q65113A7129 | WLCSP13 2.25x1.5mm | 1uH-class inductor; pulse storage; current programming | CALC_REQUIRED
U2 | RGB 1.1V buck | AP3429KTTR-G1 baseline | SOT26 | inductor; feedback; input/output caps | REFERENCE_BASELINE
U3 | RGB 1.8V LDO | AP7331 baseline | SOT23-5 | input/output caps | REFERENCE_BASELINE
U4 | RGB 2.8V LDO | AP7331 baseline | SOT23-5 | input/output caps | REFERENCE_BASELINE
U5 | IR 2.5V regulator | TBD | low-profile | 350mA startup capable; sequence control | SELECTION_REQUIRED
U6 | IR 1.35V regulator | TBD | low-profile | mode-current calculation; sequence control | SELECTION_REQUIRED
U7 | IR 1.8V regulator | TBD | low-profile | mode-current calculation; sequence control | SELECTION_REQUIRED
U8 | Head temperature sensor | TBD | low-profile | alert pull-up; local decoupling | SELECTION_REQUIRED
U9 | Local safety/interlock logic | TBD | low-profile | hardware AND/latch; pull-down; fault return | SAFETY_REVIEW
U10 | Head identity device | TBD resistor or EEPROM | low-profile | revision and calibration identity | SELECTION_REQUIRED
J1 | 51-contact dynamic-flex connector | Hirose FH26W-51S-0.3SHW(97) | 16.8x3.2x1.0mm | 15.6mm is the FPC end width not connector body; MIPI and current audit open | FLEX_GATE
J2 | RGB assembly connector | Hirose DF37NC-30DS-0.4V baseline | 30-position mezzanine | mating and service access | MECHANICAL_GATE
L1 | Projector boost inductor | TBD 1uH class | low-profile | saturation and pulse-loss calculation | CALC_REQUIRED
C1-C20 | Power and pulse capacitors | TBD | 0201-0805 | AS1170 pulse loop and six local rails | CALC_REQUIRED
C21-C60 | Sensor decoupling | TBD | 0201/0402 | manufacturer placement requirements | PINMAP_REQUIRED
R1-R24 | Bias configuration and damping | TBD | 0201/0402 | Mira bias; enable defaults; clock/control damping | IN_PROGRESS

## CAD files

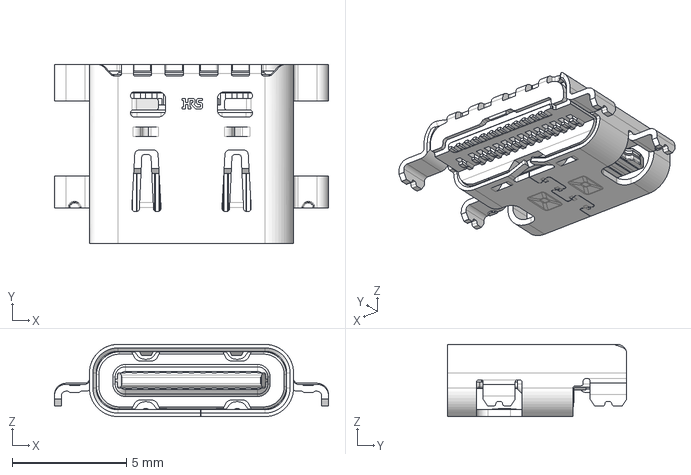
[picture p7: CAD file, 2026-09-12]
blender/vendor_cad/hirose/CX90M3-24P_4800919000_STEP.stp
12.0 x 7.85 x 3.16 mm

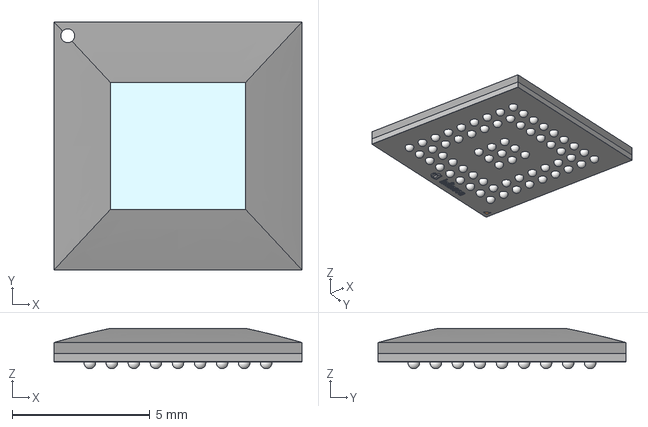
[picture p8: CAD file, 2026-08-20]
references/components/cad/infineon-pg-lfbga-65-1-3d.stp
9.00 x 9.00 x 1.47 mm

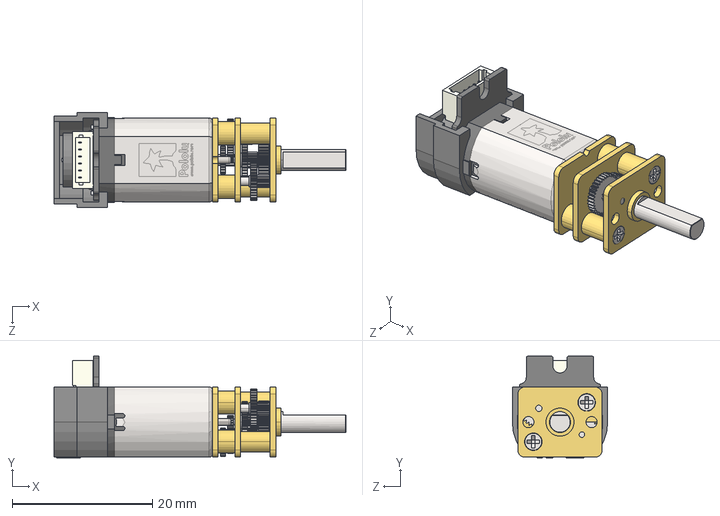
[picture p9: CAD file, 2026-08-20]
references/components/cad/pololu-gearmotor-encoder-side.step
41.6 x 14.5 x 13.6 mm

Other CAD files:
blender/refinements/r04/deepreal-exterior-refinement-r04.blend
blender/refinements/r05/deepreal-exterior-refinement-r05.blend
blender/refinements/r06/deepreal-exterior-refinement-r06.blend
blender/refinements/r07/deepreal-exterior-refinement-r07.blend
blender/refinements/r08/deepreal-exterior-refinement-r08.blend
blender/refinements/r09/deepreal-exterior-refinement-r09.blend
blender/refinements/r10/deepreal-exterior-refinement-r10.blend
blender/refinements/r11/deepreal-exterior-refinement-r11.blend
blender/refinements/r12/deepreal-exterior-refinement-r12.blend
blender/refinements/r13/deepreal-exterior-refinement-r13.blend
blender/refinements/r14/deepreal-exterior-refinement-r14.blend
blender/refinements/r15/deepreal-exterior-refinement-r15.blend
blender/refinements/r16/deepreal-exterior-refinement-r16.blend
blender/refinements/r17/deepreal-exterior-refinement-r17.blend
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

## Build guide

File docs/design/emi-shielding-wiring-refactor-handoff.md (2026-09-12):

# DeepReal EMI shielding and wiring refactor handoff

**Date:** 6 September 2026

**Status:** approved design direction; Blender implementation still required

**Active branch:** `explore/drum-internals-feasibility`

**Primary artifact:** `blender/deepreal.blend`, generated from the Python files in `blender/`

## Objective

Refactor the DeepReal Blender reference model so the complete main PCBA is
contained by a realistic grounded electronics shield enclosure, while all
drum cables remain serviceable, short, collision-free, and routed in a way
that does not undermine the shielding.

The current five-piece local shield can and exposed connector strip are no
longer the intended architecture. The new source of truth is the full-board
enclosure concept shown below.

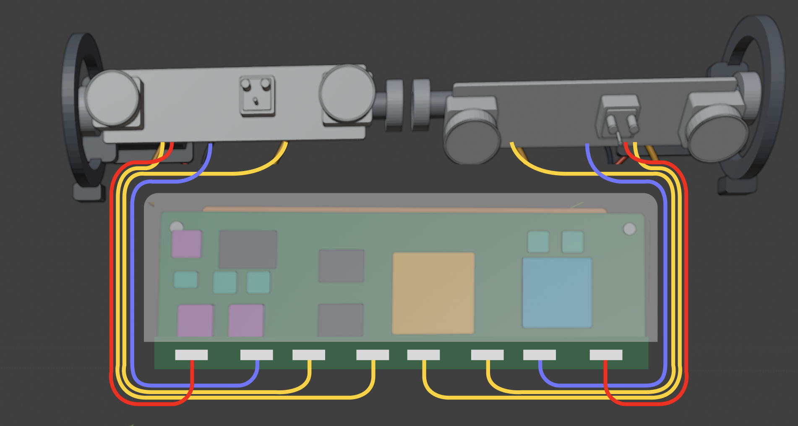
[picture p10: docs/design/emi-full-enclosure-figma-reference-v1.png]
Approved full-enclosure direction


The illustration communicates packaging intent, not final dimensions or
verified electromagnetic performance.

## Why this refactor is necessary

The current Blender model places eight drum connectors along the PCBA's upper
edge, approximately 6.5 mm below the drum envelope. Although the existing can
covers the modeled processor, FPGA, memory, power, and driver packages, the
connector transitions and service-loop cables remain exposed toward the
sensor drums.

That is an incomplete EMC architecture. High-speed differential links can
radiate when imbalance creates common-mode current, and cables or connectors
crossing a shield boundary can carry noise outside it. Shield seams,
apertures, grounding, PCB stack-up, and cable construction therefore matter
as much as the visible metal cover.

The Blender model must represent a defensible physical architecture without
claiming that the product has passed EMC testing.

## Approved architecture

### 1. Full electronics shield enclosure

Replace the existing `EMI_Shield_Can_*` arrangement with a thin conductive
enclosure around the PCBA component field.

- Enclose the front, rear, top, left, and right sides of the noisy electronics
  chamber.
- Use a removable lid or two-piece clamshell construction for assembly.
- Keep the metal entirely inside the established product housing envelope.
- Add a perimeter ground-contact concept: a PCB ground ring, closely spaced
  grounding points/vias, and several chassis-bonding tabs.
- Avoid floating metal. Every shield section must visibly share the same
  grounding strategy.
- Treat 0.3-0.8 mm sheet thickness as a visualization range, not a released
  manufacturing specification.

This part should be named **Electronics Shield Enclosure**, not merely an EMI
lid or roof.

### 2. Lower connector apron

Reserve a narrow strip at the bottom of the PCBA as the **connector apron** or
**I/O vestibule**.

- Move drum connectors from the exposed upper edge to the lower boundary.
- Group face-drum connectors near the lower-left side.
- Group interaction-drum connectors near the lower-right side.
- Use downward- or side-facing connectors so cables do not cross the shield
  face.
- Keep USB-C, microphone, tamper, and other non-drum interfaces distinct from
  the two drum banks.
- Do not leave the entire lower side of the enclosure open.

Preferred concept: the shield terminates on a grounded PCB perimeter directly
above the connector apron. The connector bodies remain service-accessible
outside the primary shielded chamber, while their PCB traces cross the shield
boundary through a controlled, ground-referenced region.

If packaging requires the connector bodies themselves to be enclosed, add a
small removable lower service cap with closely fitted cable exits. Do not add
one large open slot across the product width.

### 3. Preserve the thermal path

The processor still needs a continuous conductive path to the housing.

- Do not trap the thermal spreader behind an air gap.
- Either make one shield wall part of the heat-spreading path or use compliant
  thermal pads through the enclosure to the existing rear spreader/housing.
- Keep pressure, electrical isolation, assembly tolerance, and serviceability
  visible as separate concerns.
- Do not remove or obscure the heat-spreader concept merely to close the
  shield.

## Cable architecture

The current Blender curves are routing placeholders. Their colors do not
prove shielding, impedance, conductor pairing, or manufacturability.

### Required routes

Create two compact cable routes, one down each side of the electronics shield:

- **Left route:** face-drum camera, projector, and motor/encoder connections.
- **Right route:** interaction-drum camera, projector, and motor/encoder
  connections.

Each side should contain two visibly distinct lanes:

1. A camera-data lane for high-speed MIPI links.
2. A power/motion lane for projector power and motor/encoder wiring.

Do not place every cable in one undivided bundle. If spacing is limited, use a
thin grounded divider or separate grounded clips. Keep the complete routing
inside the existing housing silhouette.

### Cable rules

- Keep every signal conductor close to its intended return path.
- Do not spread the two conductors of a differential pair apart.
- Avoid large loops, unnecessary cable length, and crossovers.
- Provide only the extra length needed for drum travel, bend radius, assembly,
  and strain relief.
- Route camera data beside a continuous ground reference where possible.
- Keep motor and projector switching currents separated from camera data.
- Keep cable bends smooth through the complete 140-160 degree drum travel.
- Add grounded clamps or shield-termination features at the enclosure boundary.
- Model strain relief at both drum and PCBA ends.

### Intended real-world cable construction

| Connection | Physical intent |
| --- | --- |
| Camera MIPI | Controlled-impedance, ground-backed shielded flex or microcoax |
| Projector power/control | Supply and return routed together; boundary filtering provision |
| Motor/encoder | Twisted or otherwise tightly coupled supply/return conductors; motor suppression provision |
| USB-C | Connector shell bonded at the enclosure boundary |
| Low-speed control | Ground-referenced flex or paired conductors as appropriate |

Do not add common-mode chokes or filters indiscriminately in the visual model.
Represent their reserved locations, but final components require signal-
integrity analysis and pre-compliance testing.

## Blender implementation map

The `.blend` file is generated. Make the source changes in Python and rebuild
the scene rather than hand-editing only the binary.

| File | Required work |
| --- | --- |
| `blender/electronics.py` | Replace the five-piece local can with the full enclosure, ground features, connector apron, and revised connector banks. Preserve the PCBA and thermal system. |
| `blender/interconnect.py` | Replace the current direct upper-edge loops with left/right side routes and separate data versus power lanes. |
| `blender/motion.py` | Reroute both motor/encoder harnesses into the correct side power/motion lane. |
| `blender/support_hardware.py` | Add only the clips, strain relief, or shield supports that must attach to the housing. |
| `blender/presentation_views.py` | Ensure the revised parts appear correctly in all four linked views and are individually visible in the exploded view. |
| `blender/validate_model.py` | Add naming, presence, clearance, containment, and forbidden-legacy checks. |
| `docs/design/blender-reference-model.md` | Replace the obsolete description of the exposed upper connector strip and five-piece can. |

Use one canonical set of components and linked Blender instances for the four
presentation views. Do not create four independently modeled assemblies.

## Required object organization

Use clear semantic names. Exact names may vary, but the hierarchy should be
equivalent to:

```text
Electronics Shield Enclosure
  Shield_Front_Lid
  Shield_Rear_Base
  Shield_Wall_Top
  Shield_Wall_Left
  Shield_Wall_Right
  Shield_Ground_Tabs
  Shield_Lower_Service_Cap        # only if required

Connector Apron
  Face_Connector_Bank
  Interaction_Connector_Bank
  Auxiliary_Connector_Bank

Cable Routing
  Face_Data_Lane
  Face_Power_Motion_Lane
  Interaction_Data_Lane
  Interaction_Power_Motion_Lane
  Boundary_Ground_Clamps
  Drum_Strain_Relief
```

Do not retain legacy objects that only changed name while keeping the wrong
geometry.

## Visual and mechanical acceptance criteria

The refactor is not complete until all of the following are visibly true:

- The shield surrounds the main component field rather than covering only one
  side of part of the PCB.
- No processor, FPGA, memory, PMIC, motor driver, or projector driver protrudes
  through a shield wall.
- No cable or connector intersects shield geometry.
- No cable exits through a large uncontrolled opening.
- Connectors are below the primary shielded chamber and grouped by drum.
- Left and right drum cables do not cross the center unnecessarily.
- Camera-data and power/motion routes are visibly separated.
- Cable paths remain within the enclosure silhouette.
- Nothing increases the product depth or width beyond the approved housing.
- Ring gears remain clear of all optical modules and cable routes.
- The full drum travel envelope remains collision-free.
- The thermal spreader and housing contact path remain present.
- The USB-C shell does not protrude through unrelated internal geometry.
- Fully assembled, housing removed, functional core, and electronics exploded
  views all show the same linked component geometry.
- The default Blender scene opens to the four-view overview.

## Automated validation to add

At minimum, update `blender/validate_model.py` to check:

- Required new shield, connector-bank, cable-lane, and strain-relief objects.
- Absence of obsolete five-piece placeholder-only or comparison objects.
- Every protected electronic package lies inside the shielded volume.
- Every connector lies in the connector-apron zone.
- No connector, cable, optical element, gear, or shield pair has an AABB
  intersection where clearance is required.
- Shield geometry remains inside the approved product envelope.
- Minimum drum-sweep and ring-gear clearances.
- Presentation scenes exist and contain linked instances.

Automated geometry checks are necessary but not sufficient. Inspect renders
from several angles before declaring the work finished.

## Presentation deliverables

Regenerate and review:

1. Four-view overview, used as the default opening scene.
2. Fully assembled product.
3. Housing removed, including required supports and routing clips.
4. Functional core without enclosure-mounted supports.
5. Electronics exploded view showing the PCBA, shield pieces, connector banks,
   thermal pieces, clips, and cable groups separately.
6. One close-up cutaway or transparent render explaining the shield boundary
   and lower connector apron.

The exploded view must separate the shield far enough that the PCB and all
components can be inspected. Do not let the lid hide the PCB in the view whose
purpose is explanation.

## Important limitations

Do not describe this geometry as preventing all radiation or guaranteeing
clean images. The design is intended to reduce coupling and create a credible
EMC architecture. Final performance depends on PCB stack-up, grounding,
impedance control, cable construction, shield seams, filtering, clocking,
motor suppression, housing material, and physical testing.

Required later engineering work includes:

- PCB layout and connector selection.
- Signal-integrity review of every MIPI path.
- Thermal analysis and contact-pressure design.
- Cable-flex and fatigue testing through full drum motion.
- Near-field scanning and pre-compliance emissions/immunity testing.
- Testing with cameras at maximum data rate and motors/projectors switching.

## References

- Texas Instruments, *Suggestions for High-Speed Differential Connections*:
  <https://www.ti.com/lit/pdf/slla104>
- Analog Devices, *EMI-/EMC-Ready SerDes—Basic Test Strategies and Guidelines*:
  <https://www.analog.com/en/resources/design-notes/emiemcready-serdes8212basic-test-strategies-and-guidelines.html>
- Analog Devices, *AN-1109: Recommendations for Control of Radiated Emissions*:
  <https://www.analog.com/en/resources/app-notes/an-1109.html>

## Definition of done

The task is done when the Python-generated Blender model, `.blend` file,
validation script, rendered presentation set, and design documentation all
describe the same full-enclosure and two-lane cable architecture, and the
rendered model passes both automated collision checks and deliberate visual
inspection.

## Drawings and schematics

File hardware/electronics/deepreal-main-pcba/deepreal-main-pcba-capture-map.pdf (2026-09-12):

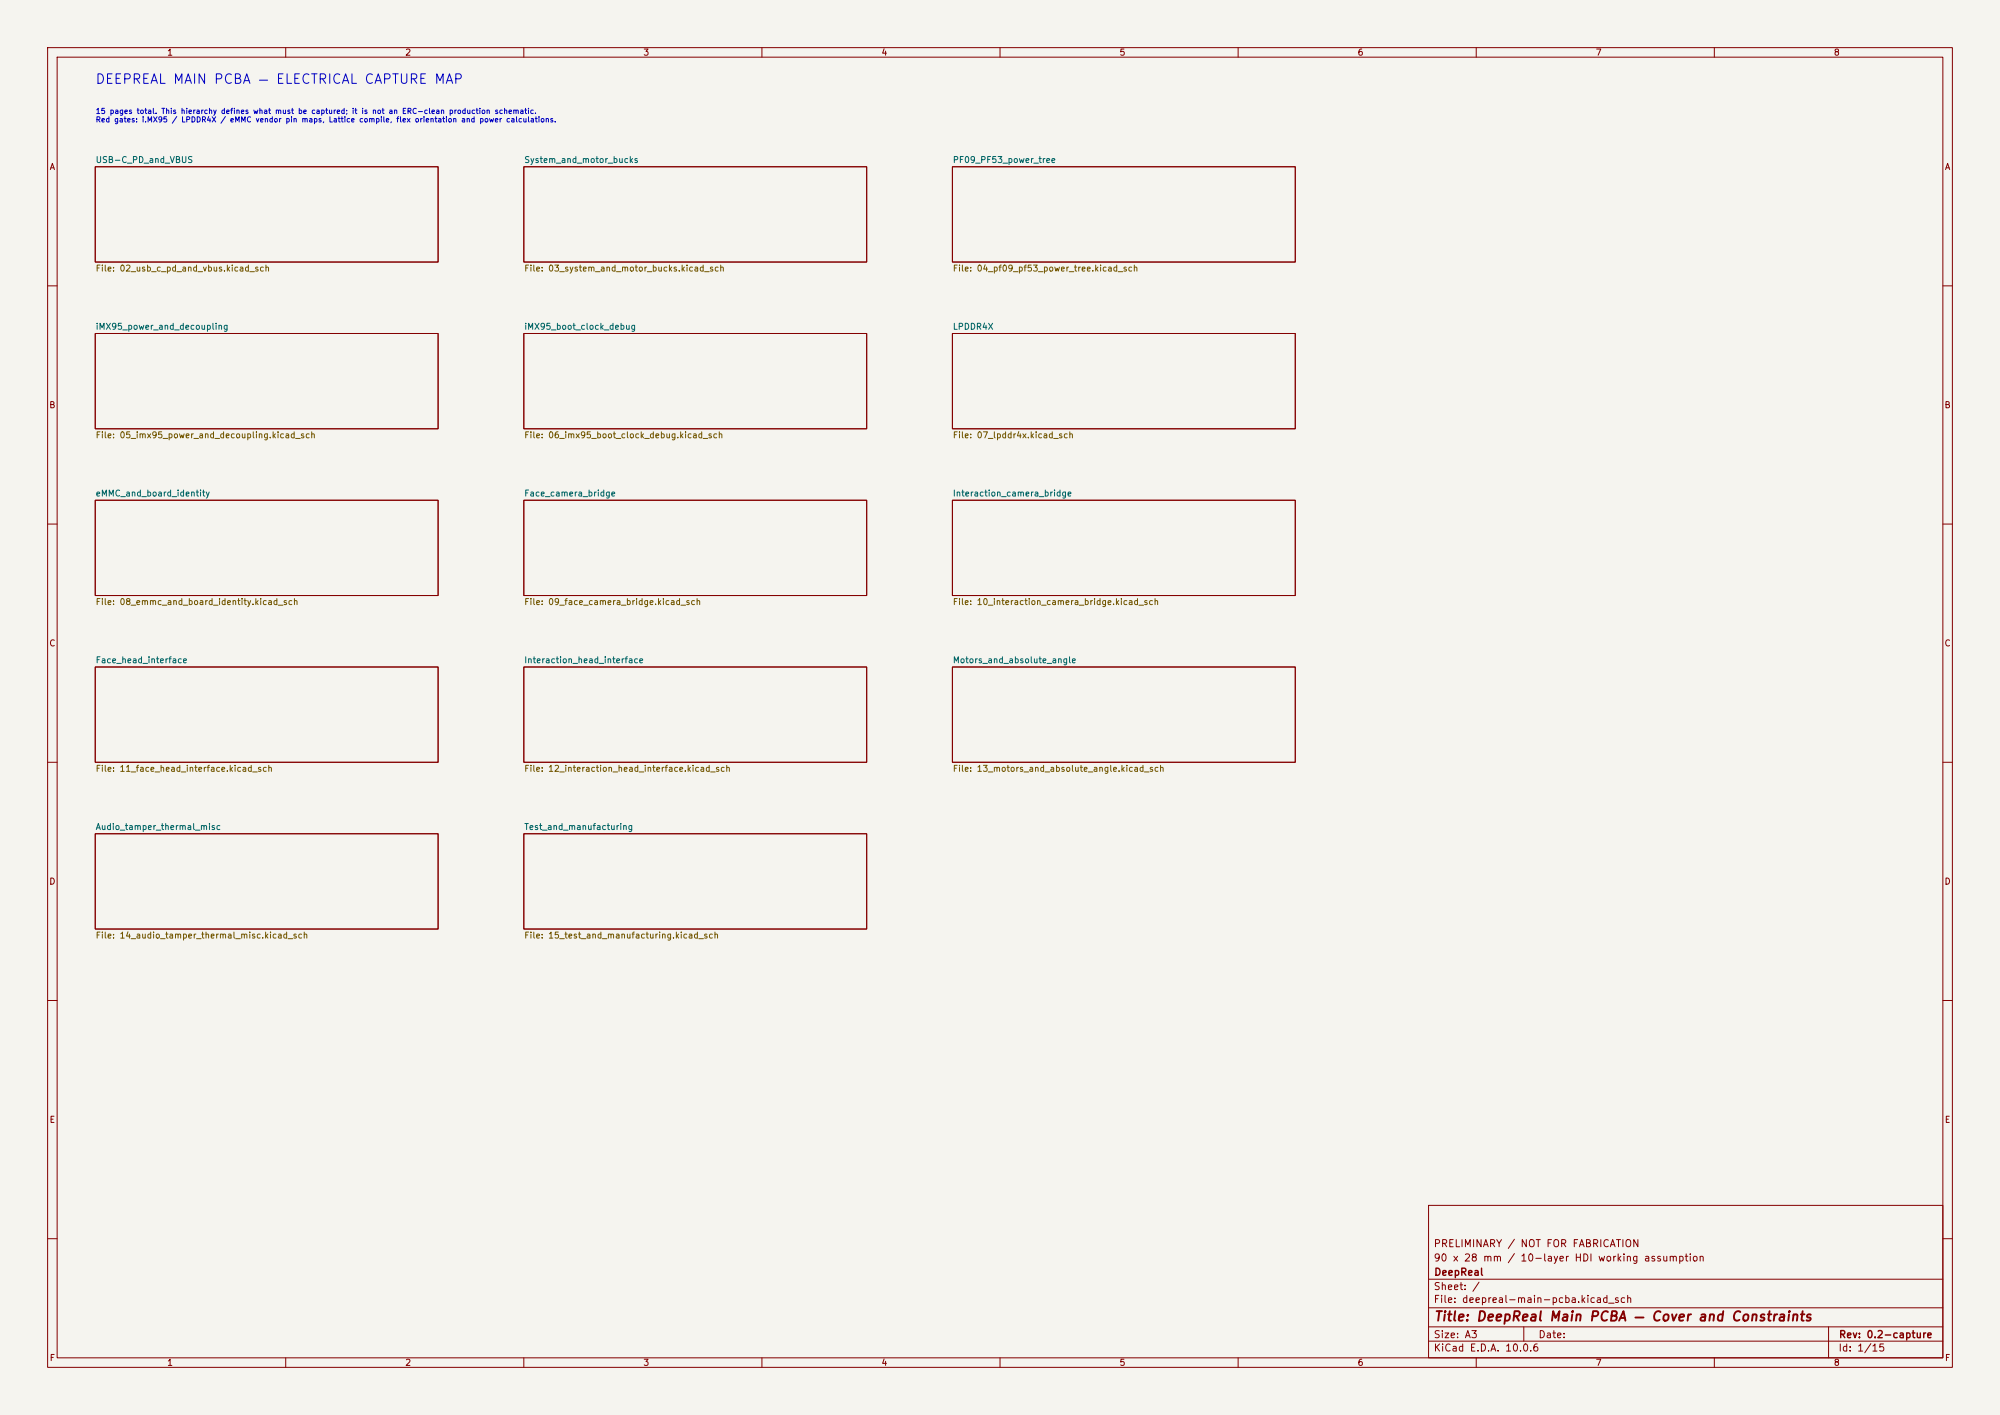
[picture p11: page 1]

DEEPREAL MAIN PCBA — ELECTRICAL CAPTURE MAP

15 pages total. This hierarchy defines what must be captured; it is not an ERC-clean production schematic. Red gates: i.MX95 / LPDDR4X / eMMC vendor pin maps, Lattice compile, flex orientation and power calculations.

PRELIMINARY / NOT FOR FABRICATION
90 x 28 mm / 10-layer HDI working assumption
DeepReal
Sheet: /
File: deepreal-main-pcba.kicad_sch
Title: DeepReal Main PCBA — Cover and Constraints

Size: A3 | Rev: 0.2-capture | F Date:
KiCad E.D.A. 10.0.6 | Id: 1/15

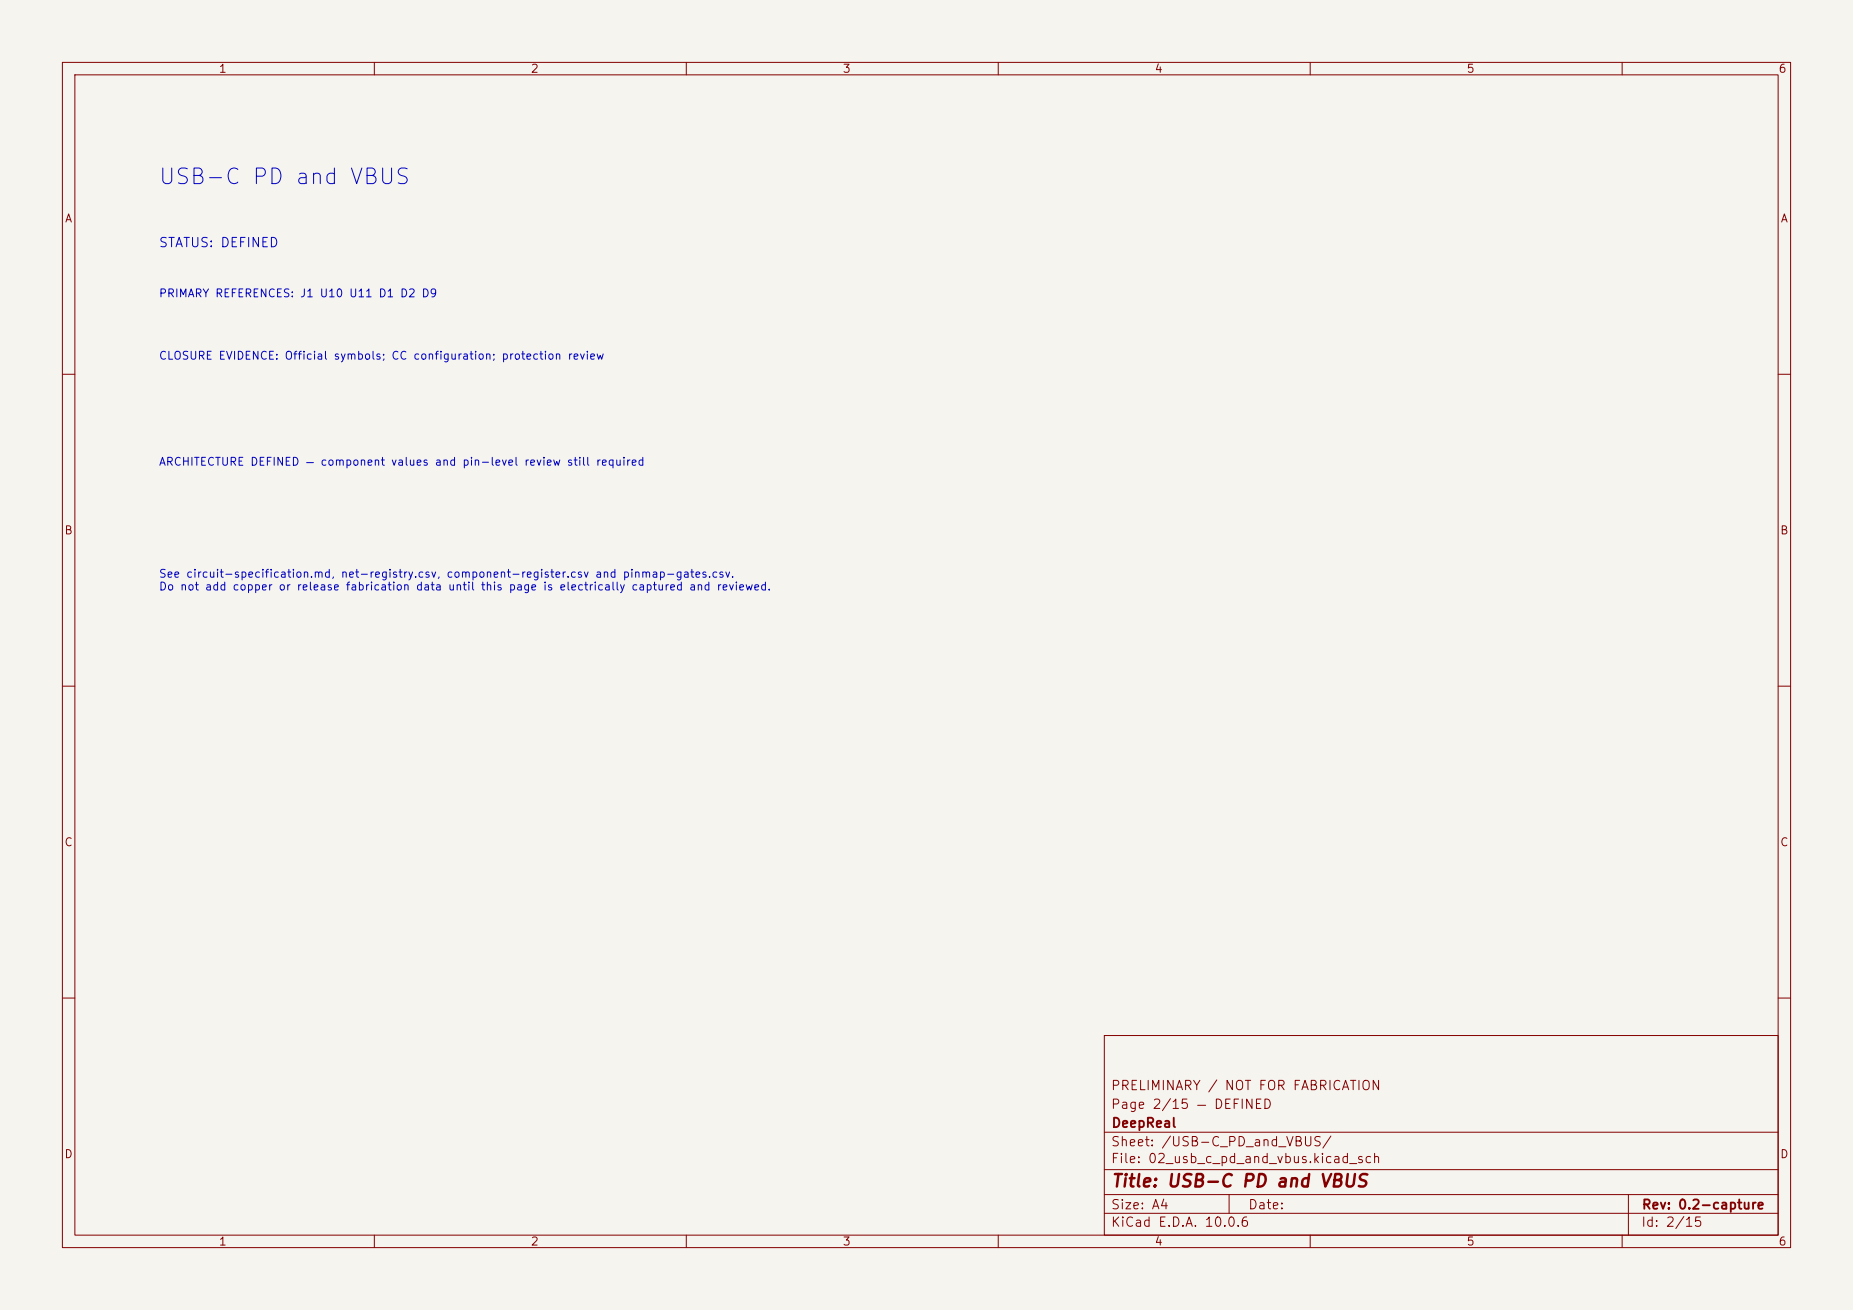
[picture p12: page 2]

USB-C PD and VBUS

PRIMARY REFERENCES: J1 U10 U11 D1 D2 D9 CLOSURE EVIDENCE: Official symbols; CC configuration; protection review

ARCHITECTURE DEFINED — component values and pin-level review still required See circuit-specification.md, net-registry.csv, component-register.csv and pinmap-gates.csv. Do not add copper or release fabrication data until this page is electrically captured and reviewed.

PRELIMINARY / NOT FOR FABRICATION
Page 2/15 — DEFINED
DeepReal
Sheet: /USB-C_PD_and_VBUS/
File: 02_usb_c_pd_and_vbus.kicad_sch
Title: USB-C PD and VBUS

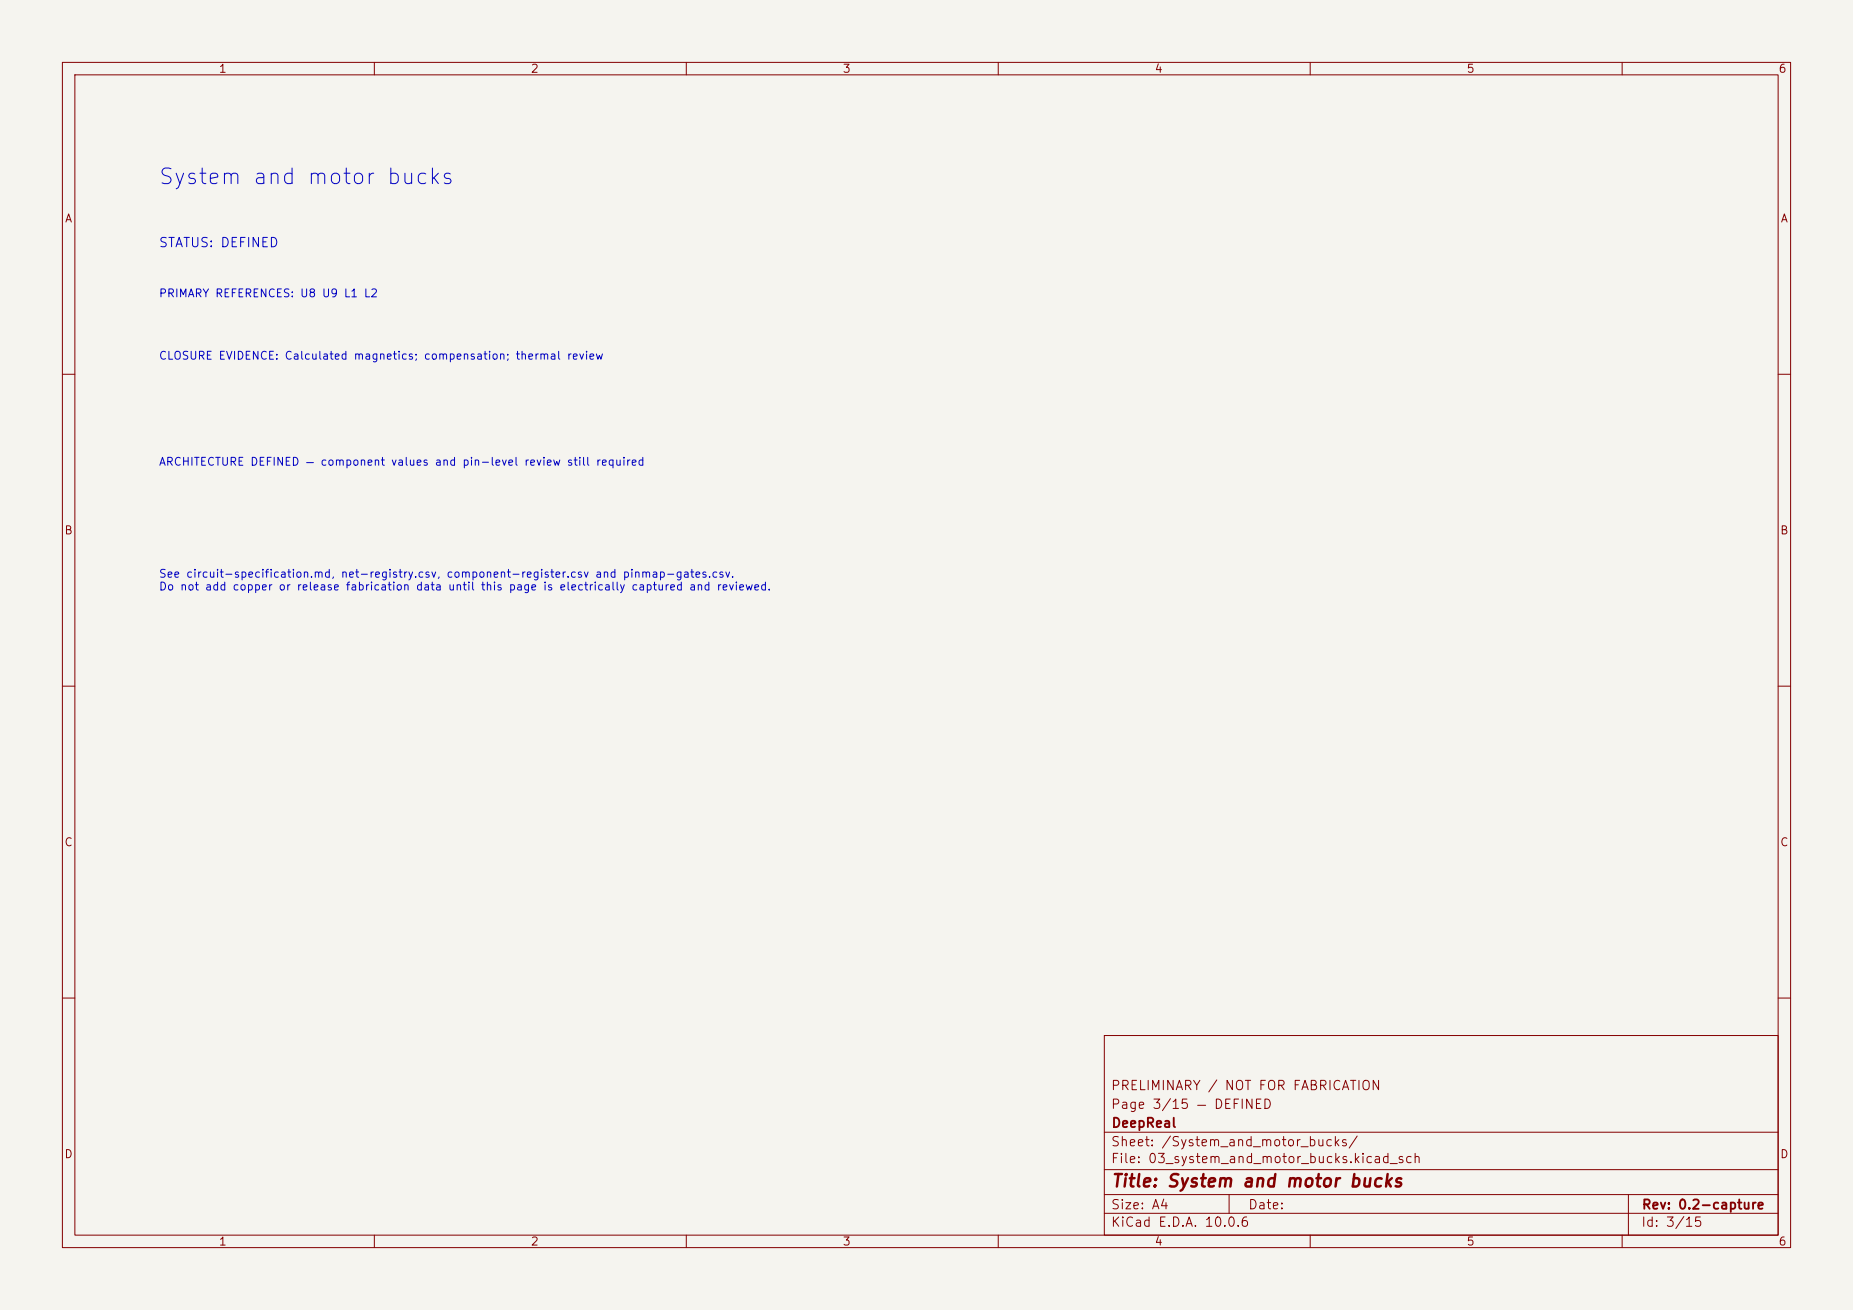
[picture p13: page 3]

System and motor bucks

PRIMARY REFERENCES: U8 U9 L1 L2 CLOSURE EVIDENCE: Calculated magnetics; compensation; thermal review

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

PRELIMINARY / NOT FOR FABRICATION
Page 3/15 — DEFINED
DeepReal
Sheet: /System_and_motor_bucks/
File: 03_system_and_motor_bucks.kicad_sch
Title: System and motor bucks

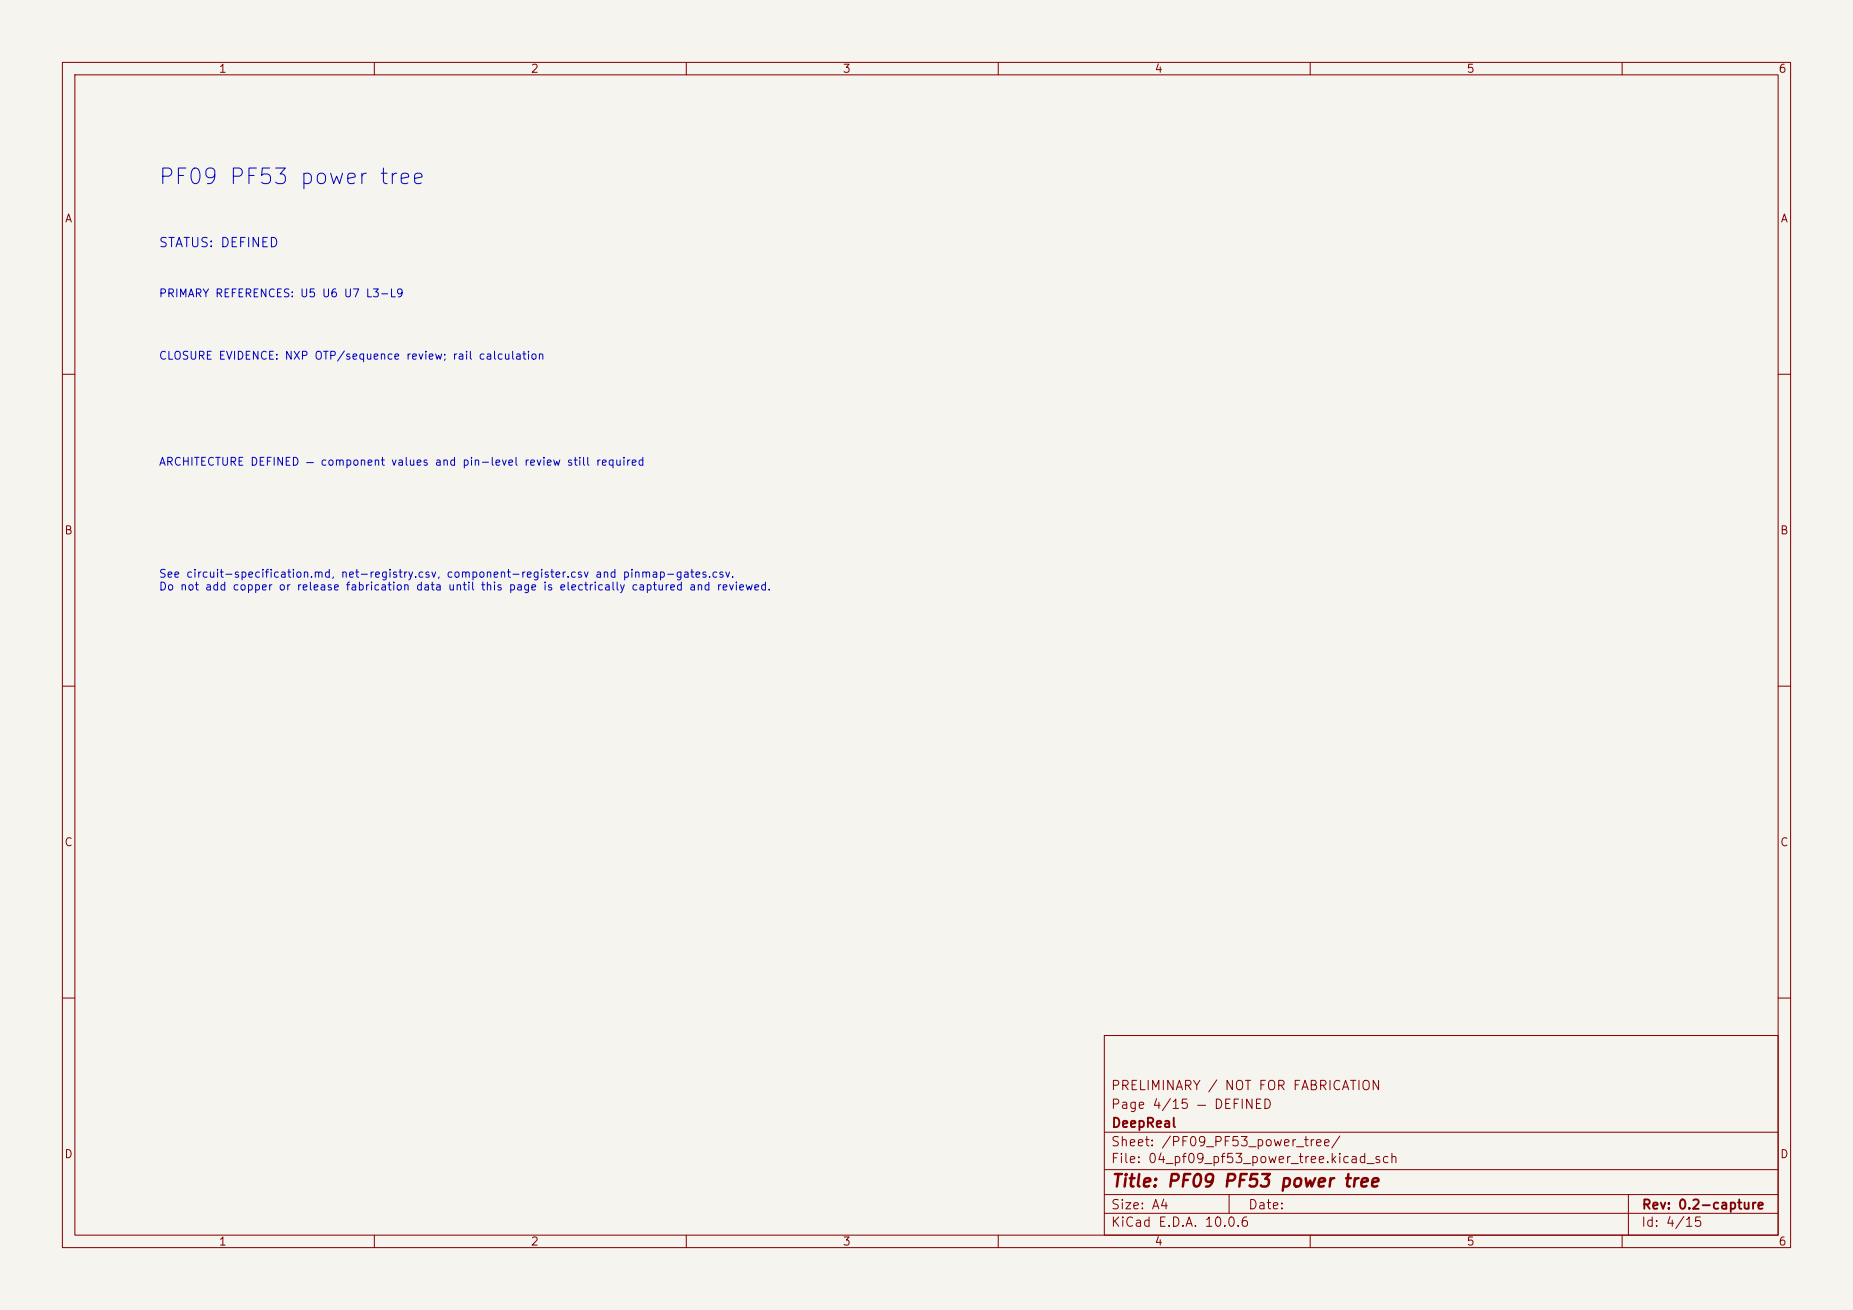
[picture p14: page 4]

PRIMARY REFERENCES: U5 U6 U7 L3-L9 CLOSURE EVIDENCE: NXP OTP/sequence review; rail calculation

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

PRELIMINARY / NOT FOR FABRICATION
Page 4/15 — DEFINED
DeepReal
Sheet: /PF09_PF53_power_tree/
File: 04_pf09_pf53_power_tree.kicad_sch
Title: PF09 PF53 power tree

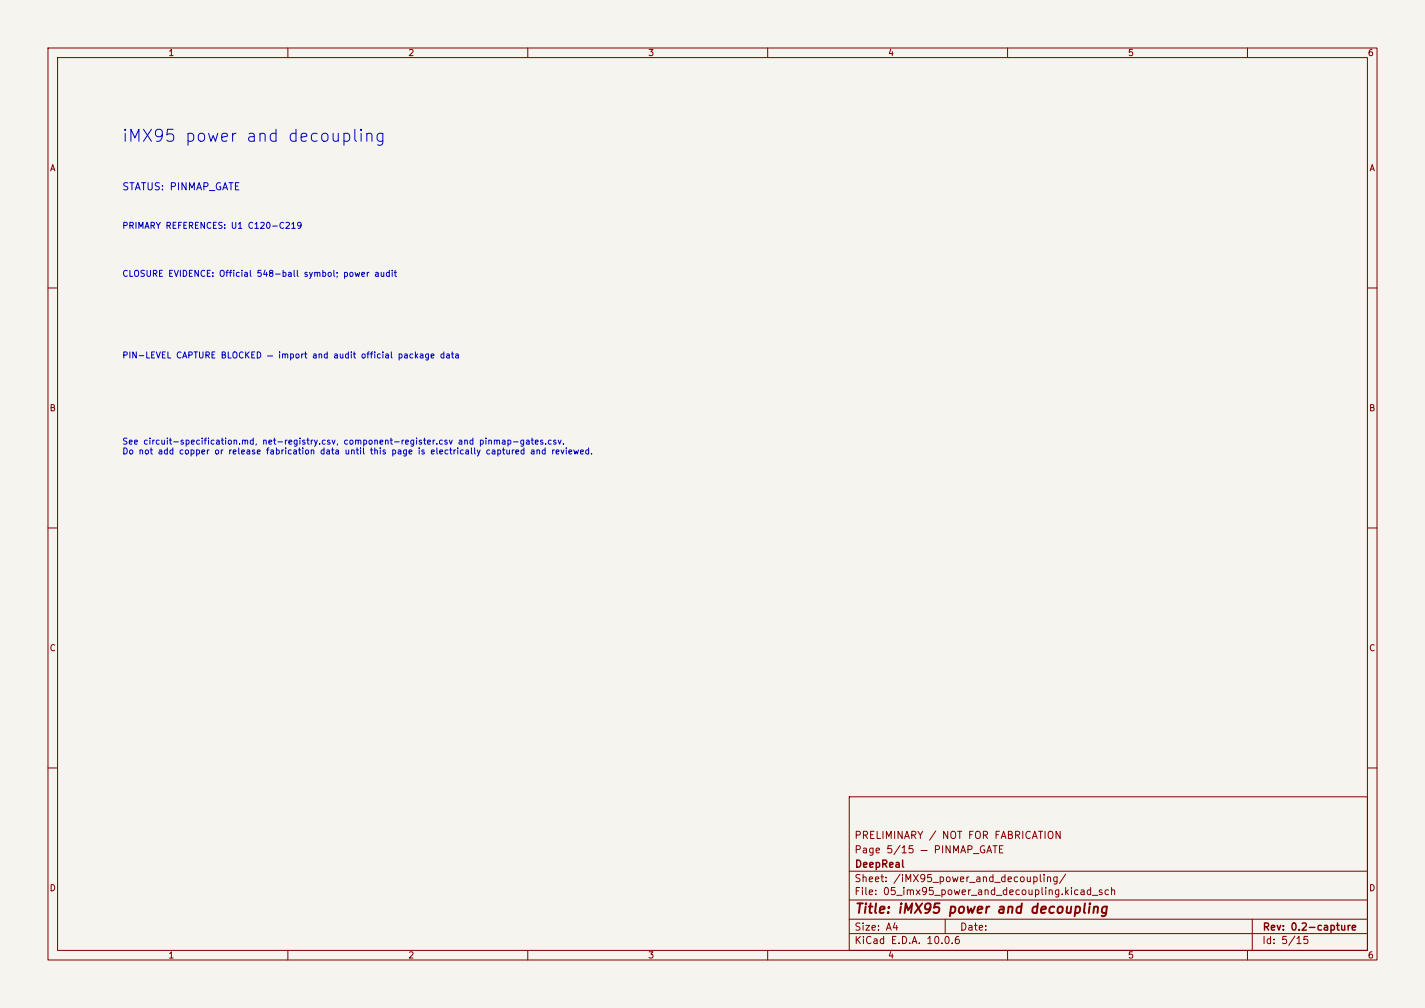
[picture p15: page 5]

PRIMARY REFERENCES: U1 C120-C219 CLOSURE EVIDENCE: Official 548-ball symbol; power audit PIN-LEVEL CAPTURE BLOCKED — import and audit official package data See circuit-specification.md, net-registry.csv, component-register.csv and pinmap-gates.csv. Do not add copper or release fabrication data until this page is electrically captured and reviewed.

PRELIMINARY / NOT FOR FABRICATION
Page 5/15 — PINMAP_GATE
DeepReal
Sheet: /iMX95_power_and_decoupling/
File: 05_imx95_power_and_decoupling.kicad_sch
Title: iMX95 power and decoupling

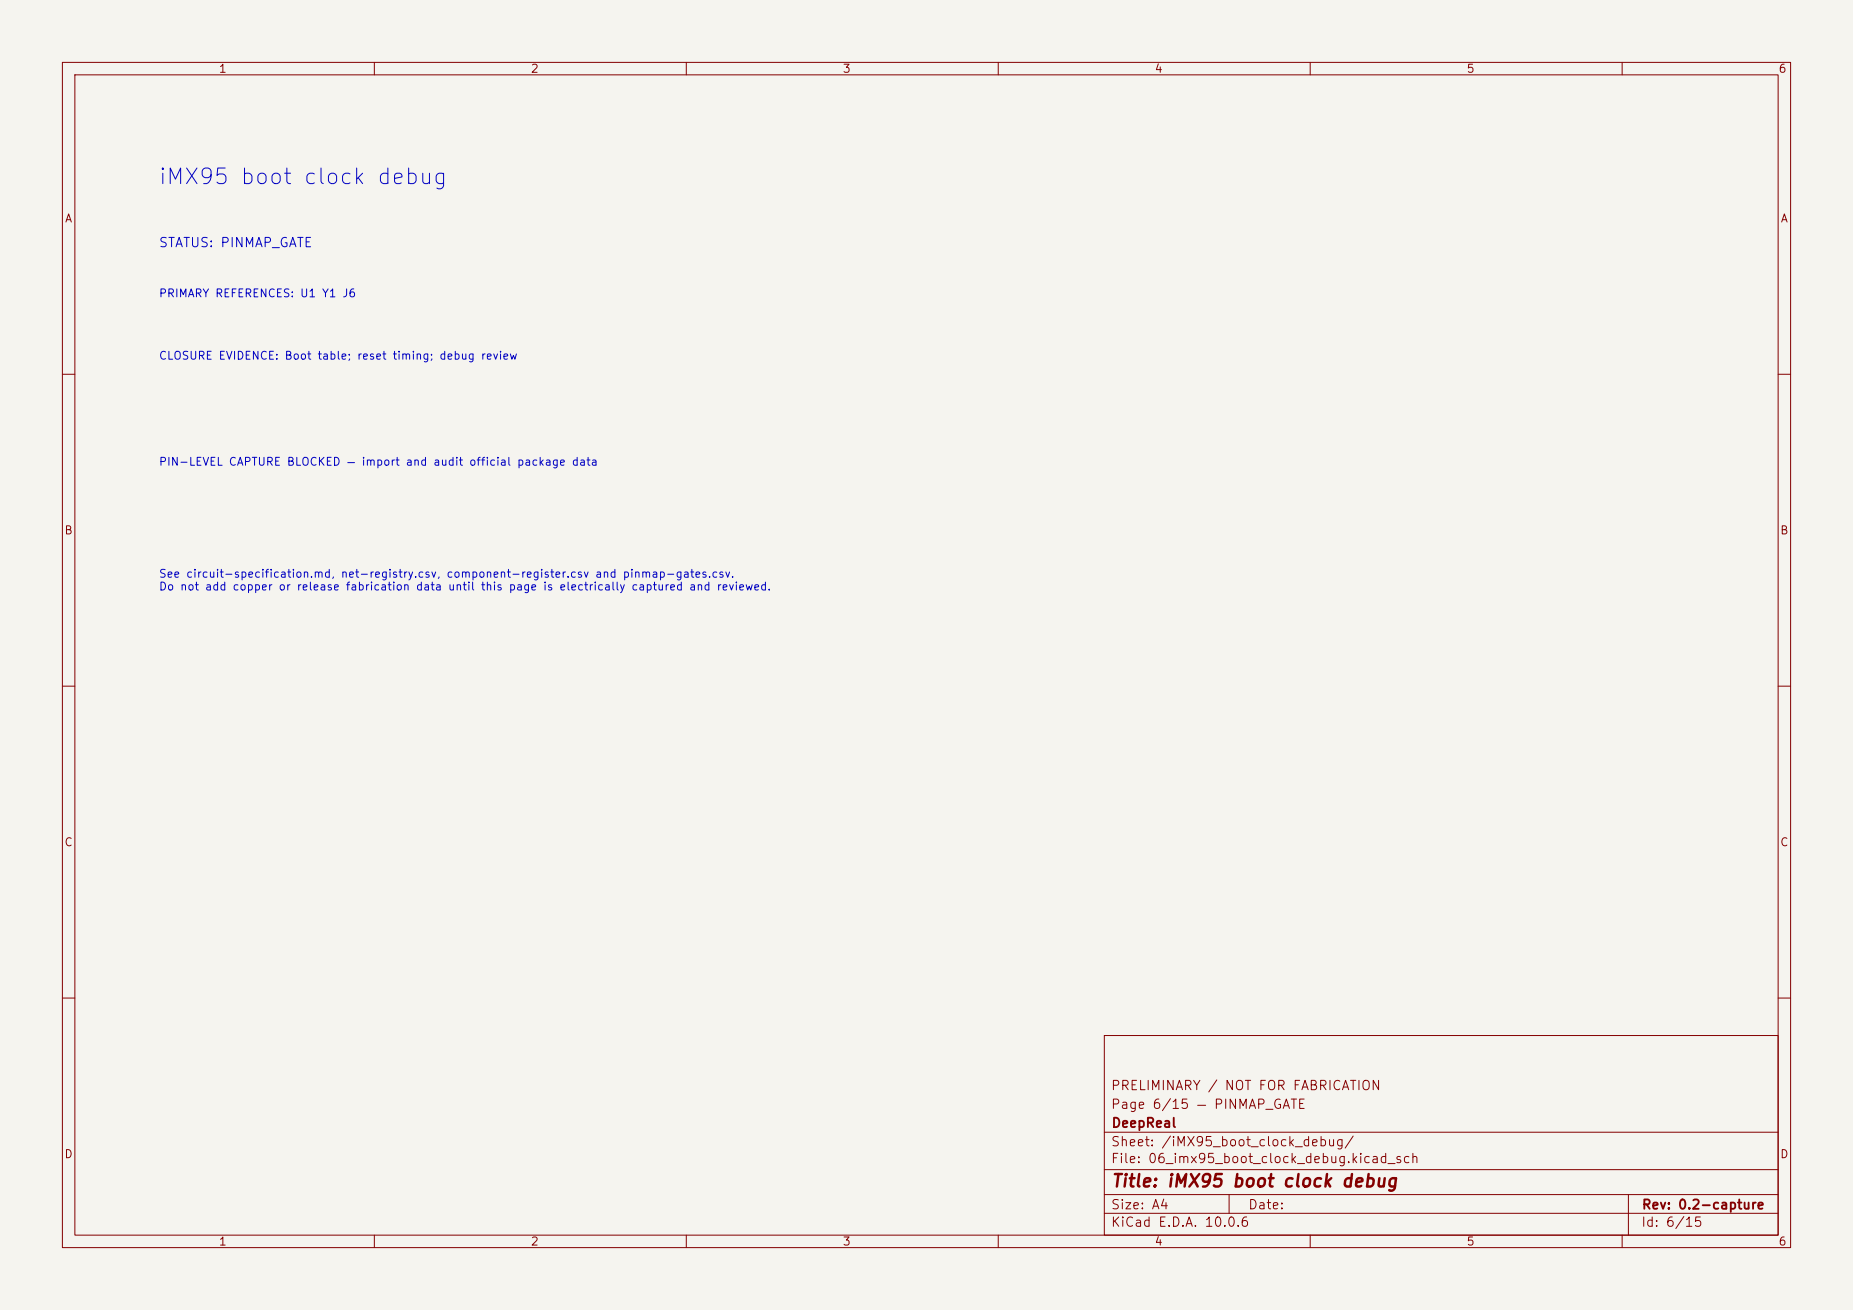
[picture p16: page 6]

PRIMARY REFERENCES: U1 Y1 J6 CLOSURE EVIDENCE: Boot table; reset timing; debug review

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

PRELIMINARY / NOT FOR FABRICATION
Page 6/15 — PINMAP_GATE
DeepReal
Sheet: /iMX95_boot_clock_debug/
File: 06_imx95_boot_clock_debug.kicad_sch
Title: iMX95 boot clock debug

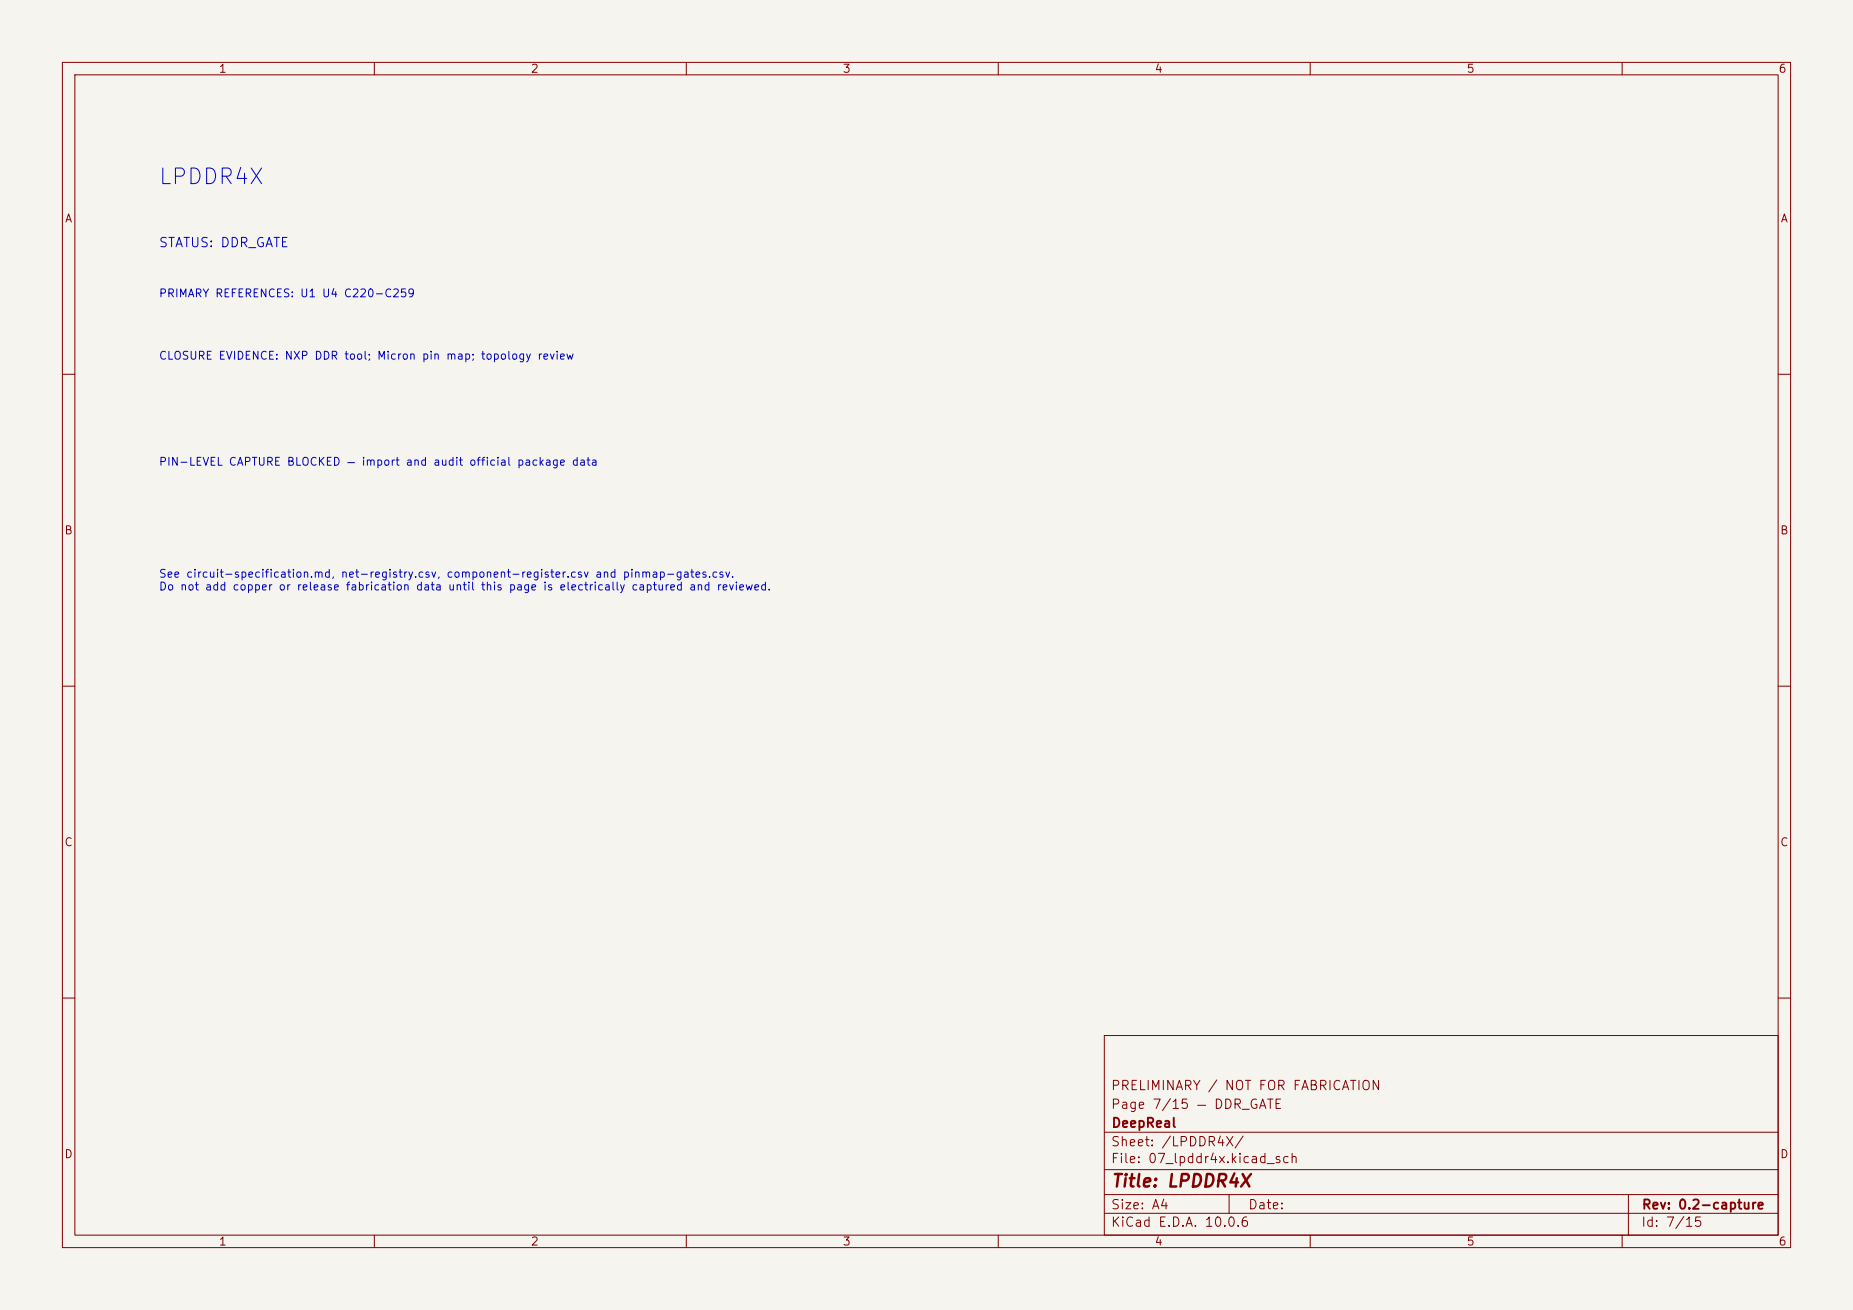
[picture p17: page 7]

PRIMARY REFERENCES: U1 U4 C220-C259 CLOSURE EVIDENCE: NXP DDR tool; Micron pin map; topology review

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

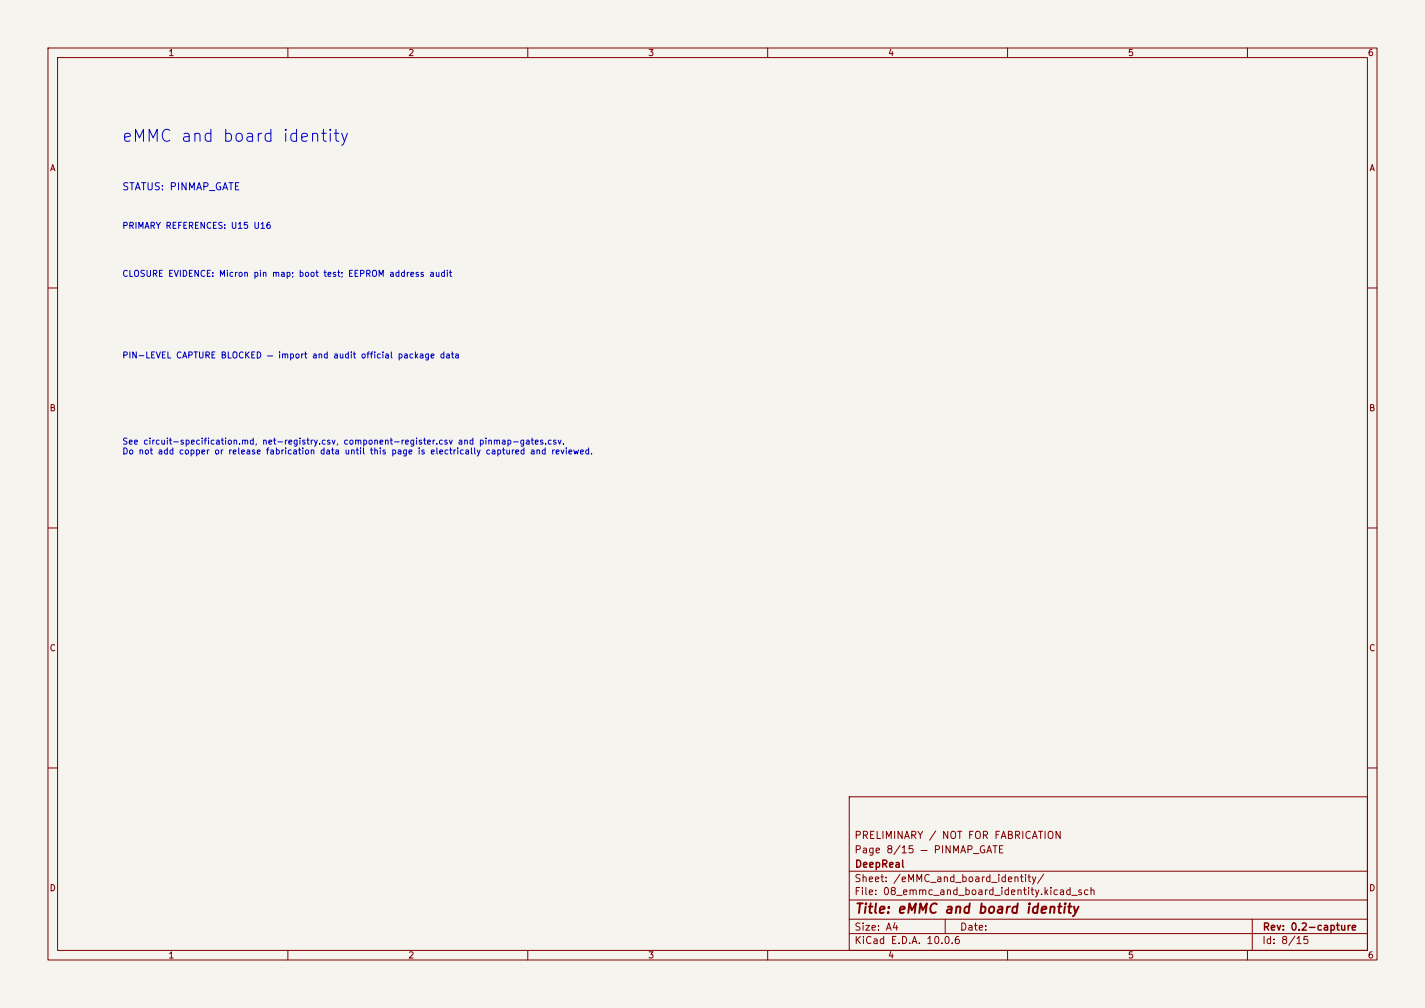
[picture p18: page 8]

eMMC and board identity

PRIMARY REFERENCES: U15 U16 CLOSURE EVIDENCE: Micron pin map; boot test; EEPROM address audit PIN-LEVEL CAPTURE BLOCKED — import and audit official package data See circuit-specification.md, net-registry.csv, component-register.csv and pinmap-gates.csv. Do not add copper or release fabrication data until this page is electrically captured and reviewed.

PRELIMINARY / NOT FOR FABRICATION
Page 8/15 — PINMAP_GATE
DeepReal
Sheet: /eMMC_and_board_identity/
File: 08_emmc_and_board_identity.kicad_sch
Title: eMMC and board identity

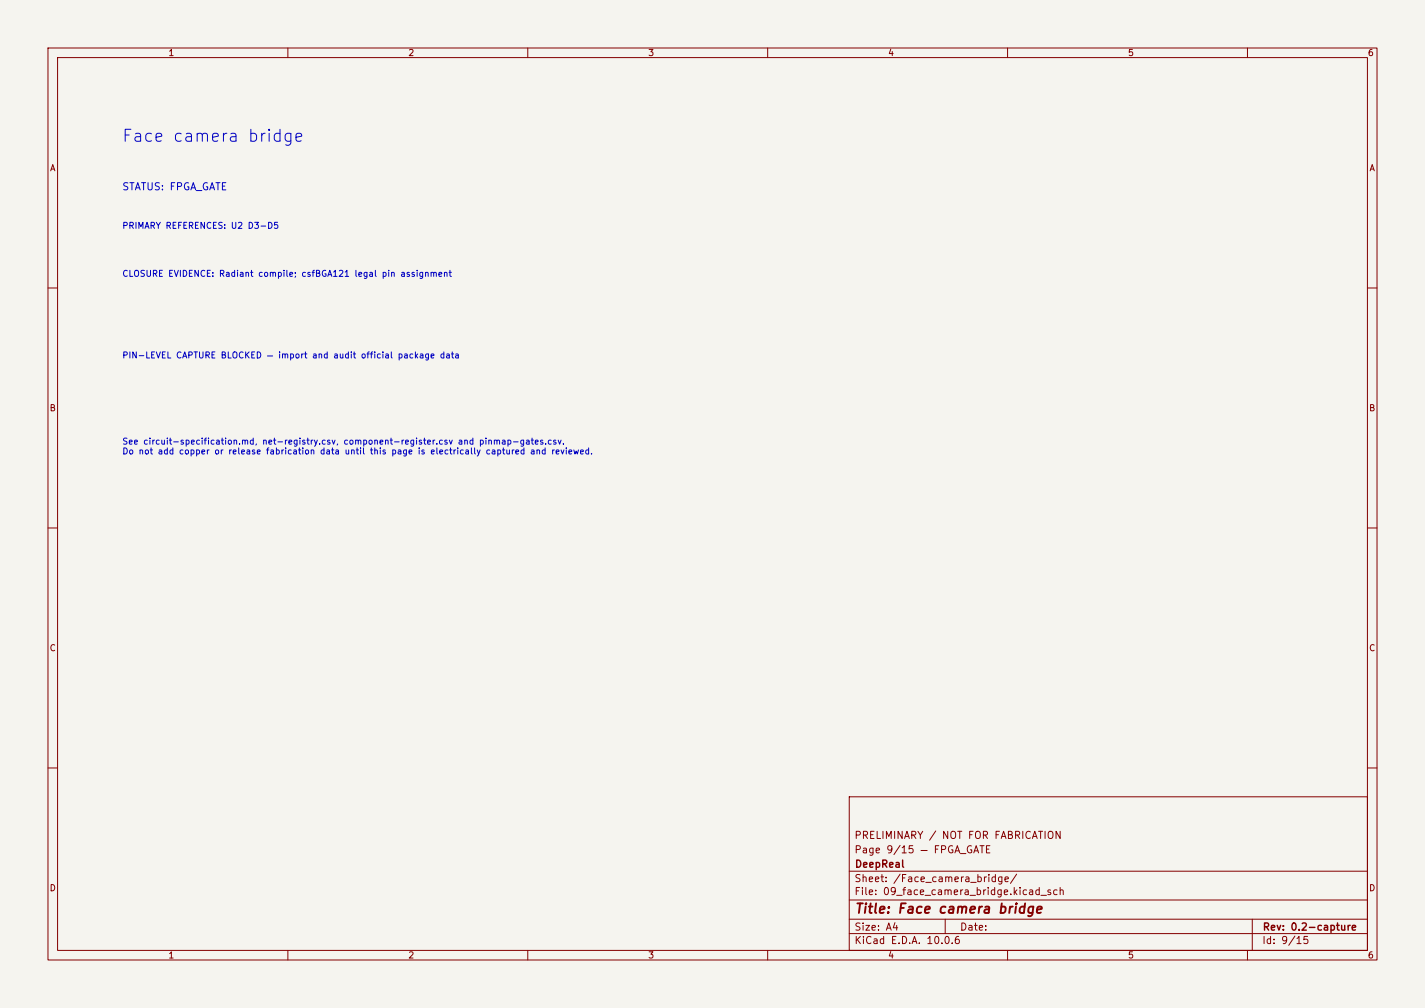
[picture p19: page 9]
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

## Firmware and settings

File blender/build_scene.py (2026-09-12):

#!/usr/bin/env python3
"""Build the Blender-native DeepReal reference scene from source.

The product dimensions live in design_spec.py.  No FreeCAD export or
generated manifest is required.  Everything is rebuilt from scratch so the
saved blend remains a generated, reproducible design artifact.

Usage (from the repository root):

    /Applications/Blender.app/Contents/MacOS/Blender --background \
        --factory-startup --python blender/build_scene.py -- [--render]

    --render          also render the verification still to blender/renders/
    --camera NAME     hero (default) | front | device | laptop
    --samples N       Cycles samples (default 96)

"""

import math
import os
import sys

import bpy
from mathutils import Vector

HERE = os.path.dirname(os.path.abspath(__file__))
if HERE not in sys.path:
    sys.path.insert(0, HERE)

import macbook        # noqa: E402
import materials      # noqa: E402
import mounting_stack # noqa: E402
import device         # noqa: E402
import design_spec    # noqa: E402
import electronics    # noqa: E402
import interconnect   # noqa: E402
import motion         # noqa: E402
import optics         # noqa: E402
import pcba_presentation  # noqa: E402
import presentation_views  # noqa: E402
import support_hardware  # noqa: E402
import usb_port       # noqa: E402
import usb_cable      # noqa: E402

BLEND_PATH = os.path.join(HERE, "deepreal.blend")
RENDER_DIR = os.path.join(HERE, "renders")

OPEN_ANGLE_DEG = 105.0   # laptop opening angle (90 = lid vertical)

MM = 0.001


def _argv_flag(name, default=None):
    args = sys.argv[sys.argv.index("--") + 1:] if "--" in sys.argv else []
    if name in args:
        return args[args.index(name) + 1] if default is not None else True
    return default


def _collection(name):
    col = bpy.data.collections.new(name)
    bpy.context.scene.collection.children.link(col)
    return col


def _aim(obj, target):
    constraint = obj.constraints.new('TRACK_TO')
    constraint.target = target
    constraint.track_axis = 'TRACK_NEGATIVE_Z'
    constraint.up_axis = 'UP_Y'


def _area_light(name, location, size, energy, color, target, col):
    light_data = bpy.data.lights.new(name, type='AREA')
    light_data.shape = 'DISK'
    light_data.size = size
    light_data.energy = energy
    light_data.color = color
    obj = bpy.data.objects.new(name, light_data)
    obj.location = location
    col.objects.link(obj)
    _aim(obj, target)
    return obj


def _set_default_viewport(target):
    """Save a useful close perspective instead of Blender's origin view."""
    focus = target.matrix_world.translation + Vector((0.0, 0.0, -0.010))
    eye = focus + Vector((0.13, -0.20, 0.075))
    rotation = (focus - eye).to_track_quat('-Z', 'Y')
    configured = 0
    for screen in bpy.data.screens:
        for area in screen.areas:
            if area.type != 'VIEW_3D':
                continue
            space = area.spaces.active
            region = space.region_3d
            space.lens = 50
            space.clip_start = 1 * MM
            space.clip_end = 10.0
            region.view_perspective = 'PERSP'
            region.view_location = focus
            region.view_rotation = rotation
            region.view_distance = (eye - focus).length
            configured += 1
    print("viewport: framed the complete device in {} 3D view(s)".format(
        configured))


def build():
    do_render = _argv_flag("--render")
    camera_name = _argv_flag("--camera", "hero")
    samples = int(_argv_flag("--samples", 256))

    manifest = design_spec.manifest()
    params = manifest["params"]

    bpy.ops.wm.read_factory_settings(use_empty=True)
    scene = bpy.context.scene
    scene.unit_settings.system = 'METRIC'
    scene.unit_settings.scale_length = 1.0
    scene.render.engine = 'CYCLES'
    scene.cycles.samples = samples
    scene.cycles.use_denoising = True
    scene.render.resolution_x = 1600
    scene.render.resolution_y = 900 if camera_name == "front" else 1200
    scene.view_settings.view_transform = 'AgX'

    mats = materials.build_all()

    col_product = _collection("DeepReal Product")
    col_lid = _collection("MacBook Lid")
    col_deck = _collection("MacBook Deck")
    col_mount = _collection("Mounting (provisional)")
    col_rig = _collection("Render Rig (hidden)")
    col_rig.hide_viewport = True   # functional for renders, invisible in viewport

    product = device.build(manifest, mats, col_product)
    col_optics = _collection("Drum Optics")
    optics.apply_to_product(manifest, mats, col_optics)
    col_electronics = _collection("Electronics Assembly")
    product += electronics.build(col_electronics)
    col_motion = _collection("Drum Motion")
    product += motion.build(col_motion)
    col_interconnect = _collection("Interconnect Routing")
    product += interconnect.build(col_interconnect)
    col_supports = _collection("Internal Supports")
    product += support_hardware.build(col_supports)
    lid, _deck = macbook.build(params, mats, col_lid, col_deck)
    mount = mounting_stack.build(params, mats, col_mount)
    col_usb = _collection("USB Port (provisional)")
    product += usb_port.build(manifest, mats, col_usb)
    product += usb_cable.build(manifest, mats, col_usb)

    # --- lid pivot: everything that swings with the lid -------------------
    # All product/MacBook vertices are baked in absolute product coordinates,
    # so children must be parented with matrix_parent_inverse = the pivot's
    # (translation-only) matrix at parenting time. The pivot's later
    # rotation then acts about the hinge point, T*R*T^-1, instead of about
    # the world origin.
    lid_h = params["DISPLAY_REFERENCE_HEIGHT"] * MM
    pivot = bpy.data.objects.new("Lid_Pivot", None)
    pivot.empty_display_size = 10 * MM
    pivot.location = Vector((0.0, 0.0, -lid_h))
    scene.collection.objects.link(pivot)
    bpy.context.view_layer.update()
    base = pivot.matrix_world.copy()          # rotation still zero
    base_inv = base.inverted()
    for obj in product + lid + mount:
        obj.parent = pivot
        obj.matrix_parent_inverse = base_inv

    # --- target + cameras + lights (all in the hidden rig collection) ----
    target = bpy.data.objects.new("Device_Target", None)
    target.empty_display_size = 5 * MM
    target.parent = pivot
    target.matrix_parent_inverse = base_inv
    target.location = (0.0, 0.0, 10 * MM)   # device centre, product frame
    col_rig.objects.link(target)

    pivot.rotation_euler.x = math.radians(90.0 - OPEN_ANGLE_DEG)

    cam_data = bpy.data.cameras.new("Camera_Hero")
    cam_data.lens = 60  # mm
    hero = bpy.data.objects.new("Camera_Hero", cam_data)
    hero.location = (0.13, -0.20, 0.055)   # front-right 3/4 of the device
    col_rig.objects.link(hero)
    _aim(hero, target)
    scene.camera = hero

    cam_data2 = bpy.data.cameras.new("Camera_Device")
    cam_data2.lens = 50
    device_cam = bpy.data.objects.new("Camera_Device", cam_data2)
    device_cam.location = (0.05, -0.14, 0.05)
    col_rig.objects.link(device_cam)
    _aim(device_cam, target)

    # Straight-on device study. The camera stays centered on the product
    # rather than favoring either drum, with enough margin to judge the
    # housing silhouette and optical layout.
    cam_data_front = bpy.data.cameras.new("Camera_Front")
    cam_data_front.lens = 55
    front_cam = bpy.data.objects.new("Camera_Front", cam_data_front)
    front_cam.location = (0.0, -0.18, 0.045)
    col_rig.objects.link(front_cam)
    _aim(front_cam, target)

    # whole-laptop view: aims at a fixed world point near the chassis
    # centre, not at the lid-mounted device
    laptop_target = bpy.data.objects.new("Laptop_Target", None)
    laptop_target.empty_display_size = 8 * MM
    laptop_target.location = (0.0, -0.03, -0.13)
    col_rig.objects.link(laptop_target)
    cam_data3 = bpy.data.cameras.new("Camera_Laptop")
    cam_data3.lens = 32
    laptop_cam = bpy.data.objects.new("Camera_Laptop", cam_data3)
    laptop_cam.location = (0.30, -0.44, 0.20)
    col_rig.objects.link(laptop_cam)
    _aim(laptop_cam, laptop_target)

    _area_light("Key", (-0.42, -0.20, 0.38), 0.7, 40, (1.0, 0.98, 0.95),
                target, col_rig)
    _area_light("Fill", (0.45, -0.10, 0.42), 0.8, 10, (0.85, 0.90, 1.0),
                target, col_rig)
    _area_light("Rim", (0.10, 0.45, 0.35), 0.4, 25, (1.0, 1.0, 1.0), target,
                col_rig)

    world = bpy.data.worlds.new("World")
    world.node_tree.nodes["Background"].inputs[0].default_value = \
        (0.02, 0.02, 0.022, 1.0)
    scene.world = world

    bpy.context.view_layer.update()
    _set_default_viewport(target)
    scene.name = "SOURCE - Canonical Assembly"
    presentation_views.build()
    pcba_presentation.build()
    bpy.ops.wm.save_as_mainfile(filepath=BLEND_PATH)
    print("Scene built: {} objects, saved {}".format(
        len(scene.objects), BLEND_PATH))

    if do_render:
        bpy.context.window.scene = scene
        names = {"hero": hero, "front": front_cam, "device": device_cam,
                 "laptop": laptop_cam}
        cam = names.get(camera_name, hero)
        scene.camera = cam
        os.makedirs(RENDER_DIR, exist_ok=True)
        scene.render.filepath = os.path.join(
            RENDER_DIR, "{}_001.png".format(camera_name))
        bpy.ops.render.render(write_still=True)
        print("Rendered:", scene.render.filepath)


if __name__ == "__main__":
    build()

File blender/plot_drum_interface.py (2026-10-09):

#!/usr/bin/env python3
"""Draw an end-on explanation of the measured R30 drum interface conflict."""

import json
from pathlib import Path

import matplotlib.pyplot as plt
from matplotlib.patches import Circle, Rectangle


ROOT = Path(__file__).resolve().parents[1]
MEASUREMENT = ROOT / "docs/electrical/drum-interface-measurement-2026-10-09.json"
OUTPUT = ROOT / "docs/electrical/drum-interface-measurement-2026-10-09.png"


def base_axis(ax, title):
    ax.add_patch(Circle((0, 0), 12, facecolor="#dce4e9",
                        edgecolor="#324b57", linewidth=2))
    ax.add_patch(Circle((0, 0), 2, facecolor="#a4b3bb",
                        edgecolor="#324b57", linewidth=1.5))
    ax.axhline(0, color="#728892", lw=.6)
    ax.axvline(0, color="#728892", lw=.6)
    ax.plot(0, 0, marker="+", ms=12, mew=2, color="#163b50")
    ax.set(xlim=(-14, 14), ylim=(-14, 14), aspect="equal", title=title,
           xlabel="Y from drum axis (mm)", ylabel="Z from drum axis (mm)")
    ax.grid(alpha=.16)


def main():
    data = json.loads(MEASUREMENT.read_text())
    face = data["drums"]["Face"]
    axis = face["pivot_center_xyz_mm"]
    magnet = face["magnet_center_xyz_mm"]
    relative_y = magnet[1] - axis[1]
    relative_z = magnet[2] - axis[2]
    width = data["outer_exit_screen"]["connector_fpc_end_width_mm"]
    bore = data["outer_exit_screen"]["spindle_bore_diameter_mm"]

    fig, plots = plt.subplots(1, 2, figsize=(12.8, 6.5), layout="constrained")
    fig.set_facecolor("#f7f9fa")
    for ax in plots:
        ax.set_facecolor("#f7f9fa")
    base_axis(plots[0], "Angle sensor location now modeled")
    plots[0].add_patch(Circle((relative_y, relative_z), 1,
                              facecolor="#e78d68", edgecolor="#8e432d", lw=1.5))
    plots[0].plot(relative_y, relative_z, marker="x", ms=10, mew=2,
                  color="#392c2a")
    plots[0].annotate("Magnet + sensor envelope\n6.0 mm off axis",
                      xy=(relative_y, relative_z), xytext=(3, 8),
                      arrowprops={"arrowstyle": "->", "color": "#8e432d"},
                      fontsize=10, color="#653625")
    plots[0].annotate("Drum axis", xy=(0, 0), xytext=(-11, -7),
                      arrowprops={"arrowstyle": "->", "color": "#163b50"},
                      fontsize=10, color="#163b50")

    base_axis(plots[1], "Proposed optical flex through outer spindle")
    plots[1].add_patch(Circle((0, 0), bore / 2, facecolor="#f7f9fa",
                              edgecolor="#142f3f", linewidth=2))
    plots[1].add_patch(Rectangle((-width / 2, -.35), width, .7,
                                  facecolor="#ddaa5b", edgecolor="#765728",
                                  alpha=.9))
    plots[1].annotate(f"51-contact FPC end: {width:g} mm wide",
                      xy=(width / 2, 0), xytext=(1, 7),
                      arrowprops={"arrowstyle": "->", "color": "#765728"},
                      fontsize=10, color="#5c4528")
    plots[1].annotate(f"Spindle bore: Ø{bore:g} mm",
                      xy=(0, -bore / 2), xytext=(-12, -7),
                      arrowprops={"arrowstyle": "->", "color": "#163b50"},
                      fontsize=10, color="#163b50")
    fig.suptitle("R30 / R21 drum interface: measured geometry, end view",
                 fontsize=15, weight="bold", color="#173746")
    fig.savefig(OUTPUT, dpi=170, bbox_inches="tight", pad_inches=.18)
    print("WROTE", OUTPUT)


if __name__ == "__main__":
    main()

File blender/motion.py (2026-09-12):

"""Concept-level drum drive, support, sensing, and travel-stop hardware."""

from mathutils import Vector

from assembly_primitives import (
    box, cylinder, material, routed_wire, tag, tube,
)


AXIS_Y = -1.5
AXIS_Z = 20.0
OUTER_GEAR_X = 54.8
RING_GEAR_WIDTH = 2.0
MOTOR_X = 47.0
MOTOR_LENGTH = 14.0


def _materials():
    return {
        "steel": material("Motion_Steel", (0.32, 0.34, 0.37),
                          metallic=0.92, roughness=0.28),
        "gear": material("Motion_Gear", (0.16, 0.18, 0.21),
                         metallic=0.78, roughness=0.36),
        "motor": material("Motion_Motor", (0.17, 0.19, 0.21),
                          metallic=0.70, roughness=0.32),
        "bearing": material("Motion_Bearing", (0.58, 0.60, 0.63),
                            metallic=0.98, roughness=0.20),
        "bracket": material("Motion_Bracket", (0.08, 0.09, 0.10),
                            metallic=0.72, roughness=0.42),
        "encoder": material("Motion_Encoder_PCBA", (0.03, 0.24, 0.09),
                            roughness=0.55),
        "magnet": material("Motion_Encoder_Magnet", (0.44, 0.10, 0.08),
                           metallic=0.55, roughness=0.38),
        "wire": material("Motion_Wiring", (0.72, 0.08, 0.035),
                         roughness=0.65),
    }


def _side(sign, label, mats, collection):
    objects = []
    drum_inner_x = sign * 1.0
    drum_outer_x = sign * 55.0
    # Keep the ring gear in the final 2 mm end band of the 54 mm drum.
    # The outer camera windows reach to X +/-52.38 mm; the former 3.2 mm
    # gear at X +/-53 mm overlapped those windows by about 1 mm.
    gear_x = sign * OUTER_GEAR_X
    motor_x = sign * MOTOR_X
    motor_y = 13.6

    shaft = cylinder("{}_Drum_Axle".format(label),
                     ((drum_inner_x + drum_outer_x) / 2.0, AXIS_Y, AXIS_Z),
                     Vector((sign, 0.0, 0.0)), 2.2,
                     abs(drum_outer_x - drum_inner_x), mats["steel"],
                     collection)
    objects.append(tag(shaft, "Drum support", "CONCEPT AXLE"))

    for suffix, x in (("Inner", sign * 2.2), ("Outer", sign * 54.2)):
        bearing = tube("{}_Bearing_{}".format(label, suffix),
                       (x, AXIS_Y, AXIS_Z), Vector((1.0, 0.0, 0.0)),
                       2.3, 4.2, 2.6, mats["bearing"], collection)
        objects.append(tag(bearing, "Drum support", "REFERENCE ENVELOPE"))

    ring = tube("{}_Ring_Gear".format(label),
                (gear_x, AXIS_Y, AXIS_Z), Vector((1.0, 0.0, 0.0)),
                9.8, 12.8, RING_GEAR_WIDTH, mats["gear"], collection,
                segments=64)
    objects.append(tag(ring, "Drum drive", "CONCEPT GEAR ENVELOPE"))

    motor = cylinder("{}_Geared_Motor".format(label),
                     (motor_x, motor_y, AXIS_Z), Vector((1.0, 0.0, 0.0)),
                     4.2, MOTOR_LENGTH, mats["motor"], collection)
    objects.append(tag(motor, "Drum drive", "REFERENCE GEARMOTOR"))
    pinion = cylinder("{}_Motor_Pinion".format(label),
                      (gear_x, motor_y, AXIS_Z), Vector((1.0, 0.0, 0.0)),
                      3.4, RING_GEAR_WIDTH, mats["gear"], collection,
                      segments=32)
    objects.append(tag(pinion, "Drum drive", "CONCEPT GEAR ENVELOPE"))

    bracket = box("{}_Motor_Bracket".format(label),
                  (motor_x, 18.0, AXIS_Z), (16.0, 1.6, 12.0), 1.0,
                  mats["bracket"], collection)
    objects.append(tag(bracket, "Drum drive", "CONCEPT BRACKET"))

    encoder_board_x = sign * 48.0
    encoder = box("{}_Encoder_Board".format(label),
                  (encoder_board_x, 7.0, AXIS_Z), (8.0, 1.0, 8.0), 0.5,
                  mats["encoder"], collection)
    objects.append(tag(encoder, "Position sensing", "AS5600-CLASS CONCEPT"))
    magnet = cylinder("{}_Encoder_Magnet".format(label),
                      (encoder_board_x, 5.8, AXIS_Z), Vector((0.0, 1.0, 0.0)),
                      2.5, 1.5, mats["magnet"], collection, segments=32)
    objects.append(tag(magnet, "Position sensing", "REFERENCE MAGNET"))

    stop = box("{}_Rotation_Stop".format(label),
               (sign * 56.0, 5.2, 7.0), (5.0, 4.0, 3.0), 0.6,
               mats["bracket"], collection)
    objects.append(tag(stop, "Travel limit", "150 DEG CONCEPT"))

    connector_x = -34.0 if sign < 0 else 34.0
    lane_x = sign * 54.0
    harness = routed_wire("{}_Motor_Encoder_Harness".format(label), (
        (sign * 40.0, motor_y, AXIS_Z),
        (sign * 46.0, 13.0, 15.0),
        (lane_x, 13.0, 10.0),
        (lane_x, 13.0, -10.0),
        (lane_x, 13.0, -25.0),
        (sign * 44.0, 13.0, -25.0),
        (sign * 40.0, 14.2, -24.2),
        (connector_x, 14.95, -24.2),
    ), 0.45, 3.0, mats["wire"], collection)
    harness["Cable_Lane"] = (
        "Face_Power_Motion_Lane" if sign < 0
        else "Interaction_Power_Motion_Lane")
    harness["Physical_Intent"] = (
        "Tightly coupled supply and return with motor suppression provision")
    objects.append(tag(harness, "Motor interconnect", "ROUTING CONCEPT"))
    return objects


def build(collection):
    mats = _materials()
    objects = []
    objects += _side(-1.0, "Face", mats, collection)
    objects += _side(1.0, "Interaction", mats, collection)
    return objects

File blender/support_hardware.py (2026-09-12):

"""Concept mounting hardware connecting internal assemblies to the shell."""

import macbook
from mathutils import Vector

from assembly_primitives import MM, box, cylinder, link_only, material, tag


def _routing_clip(name, center, outer, inner, height, mat, collection,
                  subsystem, evidence):
    """Create an open cable channel instead of a solid placeholder block."""
    obj = macbook.frame(
        name, Vector(tuple(value * MM for value in center)),
        macbook.X, macbook.Y,
        tuple(value * MM for value in outer), 0.55 * MM,
        tuple(value * MM for value in inner), 0.35 * MM,
        height * MM, mat)
    link_only(obj, collection)
    obj["Channel_Clearance_mm"] = (
        "{:.2f} x {:.2f}".format(inner[0], inner[1]))
    return tag(obj, subsystem, evidence)


def build(collection):
    """Build removable brackets/standoffs as a distinct presentation layer."""
    bracket = material("Support_Bracket", (0.12, 0.14, 0.16),
                       metallic=0.82, roughness=0.38)
    fastener = material("Support_Fastener", (0.48, 0.50, 0.53),
                        metallic=0.96, roughness=0.24)
    ground = material("Support_Grounded_Clip", (0.58, 0.60, 0.62),
                      metallic=0.94, roughness=0.27)
    relief = material("Support_Strain_Relief", (0.08, 0.09, 0.10),
                      roughness=0.64)
    objects = []

    # Four rear standoffs retain the stationary PCBA without occupying the
    # central thermal-transfer area.
    for x_label, x in (("L", -42.0), ("R", 42.0)):
        for z_label, z in (("B", -22.5), ("T", -0.5)):
            post = cylinder("PCBA_Standoff_{}_{}".format(x_label, z_label),
                            (x, 19.15, z), Vector((0.0, 1.0, 0.0)),
                            1.7, 4.0, bracket, collection, segments=32)
            post["Mounting_Interface"] = "Seats against rear PCB face"
            objects.append(tag(post, "Internal mounting",
                               "CONCEPT STANDOFF"))
            screw = cylinder("PCBA_Fastener_{}_{}".format(x_label, z_label),
                             (x, 15.0, z), Vector((0.0, 1.0, 0.0)),
                             1.15, 1.1, fastener, collection, segments=32)
            screw["Mounting_Interface"] = "Seats against front PCB face"
            objects.append(tag(screw, "Internal mounting",
                               "CONCEPT FASTENER"))

    # These carrier blocks represent the housing interfaces for the two
    # outer drum bearings. Their final molded shape remains open.
    for label, x in (("Face", -54.2), ("Interaction", 54.2)):
        carrier = box("{}_Bearing_Carrier".format(label),
                      (x, 6.6, 20.0), (6.0, 2.4, 15.0), 1.2,
                      bracket, collection)
        objects.append(tag(carrier, "Internal mounting",
                           "CONCEPT BEARING CARRIER"))

    # Each side has a divider and fitted channels for the actual data and
    # power/motion routes. Unlike the old solid blocks, these parts surround
    # the cables without occupying the cable volume.
    for label, sign in (("Face", -1.0), ("Interaction", 1.0)):
        divider = box(label + "_Lane_Grounded_Divider",
                      (sign * 50.75, 9.75, -10.0),
                      (0.45, 5.5, 25.0), 0.20, ground, collection)
        objects.append(tag(divider, "Cable lane support",
                           "GROUNDED-DIVIDER CONCEPT"))

        data_clip = _routing_clip(
            label + "_Data_Lane_Grounded_Clip",
            (sign * 48.2, 9.0, -11.0),
            (6.0, 5.4), (4.8, 4.2), 3.2, ground, collection,
            "Camera cable support", "GROUNDED-CHANNEL CONCEPT")
        objects.append(data_clip)
        power_clip = _routing_clip(
            label + "_Power_Motion_Lane_Grounded_Clip",
            (sign * 53.0, 12.0, -11.0),
            (5.6, 5.2), (4.4, 4.0), 3.2, ground, collection,
            "Power/motion cable support", "GROUNDED-CHANNEL CONCEPT")
        objects.append(power_clip)

        boundary = _routing_clip(
            label + "_Boundary_Ground_Clamp",
            (sign * 50.5, 10.5, -18.5),
            (10.8, 10.0), (9.4, 8.6), 2.4, ground, collection,
            "Shield boundary clamp", "GROUND-TERMINATION CHANNEL")
        boundary["Grounding_Intent"] = (
            "Cable shield termination at electronics enclosure boundary")
        objects.append(boundary)

        for location, x, y, z, outer, inner in (
            ("Drum_Data", sign * 48.2, 9.0, 4.5,
             (6.0, 5.4), (4.8, 4.2)),
            ("Drum_Power", sign * 53.0, 12.0, 4.5,
             (5.6, 5.2), (4.4, 4.0)),
            ("PCBA_Data", sign * 48.2, 9.0, -14.5,
             (6.0, 5.4), (4.8, 4.2)),
            ("PCBA_Power", sign * 53.0, 12.0, -14.5,
             (5.6, 5.2), (4.4, 4.0)),
        ):
            strain = _routing_clip(
                "{}_{}_Strain_Relief".format(label, location),
                (x, y, z), outer, inner, 2.8, relief, collection,
                "Cable strain relief", "FITTED SERVICEABILITY CHANNEL")
            objects.append(strain)

    return objects

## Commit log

2026-08-18 Add Python-driven parametric FreeCAD model with live reload
    Phase 1: MacBook Air M2 display reference + main housing envelope.
    Phase 2: two X-axis sensor head barrels on the user side (-Y) with
    independent pitch rotation and flush orientation marks.
    Phase 2.5: live-reload dev session (cad/dev.sh) with in-place
    rebuilds, debounced file watching, and review camera capture/restore;
    deterministic headless build and 129-check validation suite.
    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
    [deepreal.FCStd]
2026-08-19 feat(cad): complete FreeCAD live-reload development workflow
    Stamp every generated object with a DeepRealGenerated ownership
    property and delete stamped objects that drop out of the source
    registry, so removing source-defined geometry removes it from the open
    document on the next reload; manually created objects are never
    touched. Adds orphan-cleanup validation coverage (136 checks, all
    passing). Verified by a human-visible end-to-end test: a temporary
    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
    [deepreal.FCStd]
2026-08-19 feat(cad): integrate rear arm and laptop-lid pocket into Main_Housing
    Phase 3: Main_Housing is now one extruded Y-Z side profile (rectangular
    sensor body + full-width quarter-circle rear arm + laptop-lid pocket) --
    a single connected solid with no boolean seams. The arc meets the housing
    exactly at its bottom-rear corner, tangent to the rear face. Housing
    placement derives from pocket parameters (front face flush with the lid
    front plane, bottom floating MAIN_BODY_LID_TOP_CLEARANCE above the lid
    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
    [deepreal.FCStd]
2026-08-20 feat(cad): add drum-internals feasibility study (Gate 1)
    Exploratory study on whether the two approved 24x54 mm sensor-head
    drums can contain RGB + depth sensing, actuators, bearings, and wiring
    for 140-160 deg motorized rotation, without touching the approved
    exterior (deepreal.FCStd checksum-guarded against main).
    Gate 1 deliverables:
    - component_sources.md registry: 7 components with official dims,
    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
    [drum_internals.FCStd, mmgm-pm-enc-side-con.step]
2026-08-20 feat(cad): add discrete depth architectures and in-drum layouts (Gate 1.5B)
    Replace the all-in-one module depth hypothesis with sourced discrete
    components and three validated in-drum layout studies, all inside the
    unchanged Ø24x54 drums (deepreal.FCStd checksum guard still passing):
    - registry: evidence classification (OFFICIAL-VERIFIED /
    OFFICIAL-INCOMPLETE / ENGINEERING-ASSUMPTION / UNRESOLVED); new
    components CM3 Sensor Assembly (TNBA1392 multi-part), OV9281 bare
    sensor, ams BELICE-850 + Belago1.2 projectors, Infineon IRS2877A
    (STEP-verified 9.0x9.0x1.465) and IRS2976C (UNRESOLVED lower bound),
    ToF illuminator placeholder
    - layouts: SL-A (axial RGB->IR->projector, 26.3 mm X s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
    [drum_internals.FCStd, infineon-pg-lfbga-65-1-3d.stp]
2026-08-21 feat(blender): add CAD-driven Blender render pipeline (Gate R1)
    - cad/export_blender.py: headless FreeCAD exporter; tessellates every
    generated shape to STL and writes manifest.json (per-part bbox,
    volume, CAD review colours, resolved params, and the Main_Housing
    Y-Z profile polyline sliced from the solid)
    - blender/: all-bpy scene package, rebuilt from scratch on every run --
    materials.py (Principled library), macbook.py (parametric MacBook
    Air locked to the CAD lid slab), mounting_stack.py (provisional
    Phase-4 preview sized from pocket params), device.py (native
    quad/n-gon rebuild of housing + drums from the CAD profile, volume
    verified against the CAD solids to <0.1%), bui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
    [build_scene.py, device.py, macbook.py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]
2026-08-22 feat(blender): drum optical packaging + refinement pass (Gate R2)
    - device.py: drums rebuilt as hollow shells -- outer envelope CAD-exact
    (bbox verified to 0.0003 mm), interior O21 x 51 with 1.5 mm wall per
    the feasibility study's documented assumptions; housing keeps its
    CAD-volume verification (<0.01%)
    - optics.py: optical hardware packaged inside both drums -- through-
    wall bores (live booleans), parallel optic axes, internal carrier
    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
2026-09-05 feat(blender): unify reference design and retire legacy CAD
    [deepreal.FCStd, drum_internals.FCStd, infineon-pg-lfbga-65-1-3d.stp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]
2026-09-05 fix(blender): rebuild shield routing and add linked views
    [build_scene.py, interconnect.py, motion.py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]
2026-09-05 fix(blender): clear ring gears from drum optics
    [motion.py]
2026-09-12 feat(hardware): define preliminary DeepReal PCBA architecture
    [CX90M3-24P_4800919000_STEP.stl, CX90M3-24P_4800919000_STEP.stp, component-register.csv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]
2026-09-12 feat(hardware): add investor-facing PCBA visualization
    [02_usb_c_pd_and_vbus.kicad_sch, 03_system_and_motor_bucks.kicad_sch, 04_pf09_pf53_power_tree.kicad_sch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]
2026-09-12 fix(hardware): flatten illustrative PCB traces
2026-09-12 fix(hardware): reroute visual copper around components
    [deepreal-main-pcba-visual.kicad_pcb, deepreal-main-pcba.kicad_pcb]
2026-09-13 feat(hardware): establish gated PCBA engineering rebuild
    [change-register.csv, component-evidence.csv, component-register.csv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]
2026-09-13 Remove superseded PCBA visualization assets
    [deepreal-main-pcba-visual.kicad_pcb]
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2026-09-14 Audit two-drum connector geometry and head interface limits
    [change-register.csv, component-evidence.csv, component-register.csv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]
2026-10-05 Add DeepReal enclosure refinement models through R13
    [deepreal-exterior-refinement-r04.blend, deepreal-exterior-refinement-r05.blend, deepreal-exterior-refinement-r06.blend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]
2026-10-06 Add DeepReal drum assembly refinements R14 through R16
    [deepreal-exterior-refinement-r14.blend, deepreal-exterior-refinement-r15.blend, deepreal-exterior-refinement-r16.blend]
2026-10-07 Add DeepReal drum support studies and wide RGB envelope
    [component-register.csv, deepreal-exterior-refinement-r17.blend, deepreal-rear-support-study-r18.blend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]
2026-10-09 Refine drum enclosure and restore monitor mount ledge
    [deepreal-circular-divider-enclosure-r29.blend, deepreal-circular-divider-review-r29.blend, deepreal-contoured-roof-edge-r26.blend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]
2026-10-09 Add pressed logo plate studies and light sweep animation
    [deepreal-creased-logo-light-sweep-r33.blend, deepreal-creased-logo-plate-review-r33.blend, deepreal-logo-mount-plate-review-r31.blend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]
2026-10-09 Record Mira220 power and clock evidence
    [change-register.csv, component-evidence.csv, component-register.csv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]
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2026-10-09 Flag drum angle sensor placement conflict
    [change-register.csv, component-evidence.csv, component-register.csv]
2026-10-09 Measure drum encoder and flex geometry conflicts
    [change-register.csv]
2026-10-09 Study centered face encoder and inner flex passage
    [deepreal-face-interface-study-r34.blend]
2026-10-09 Study face drum shaft coupling and flex motion conflicts
    [deepreal-face-motion-study-r35.blend]
2026-10-09 Model inner bearing side support cable window
    [deepreal-inner-bearing-window-r36.blend]
2026-10-09 Map rear cable volume and support conflicts
    [deepreal-rear-cable-volume-r37.blend]
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2026-10-10 Refine DeepReal exterior mount and USB plug
    [deepreal-exterior-mount-r38.blend]
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2026-10-14 Record DeepReal PCB and assembly fit studies
    Add scoped private PCB candidate builders, manufacturer package evidence,
    optical clearance corrections, native transport audits and regression tests.
    Retain the concept support work and measured flex/interface checkpoints.
    Record the USB comparison and marking-only reduction from 496 to 374 DRC
    findings. The PCB remains unrouted and DRC-failed; USB selection, assembly
    fit and manufacturing permissions remain blocked. Private CAD artifacts
    stay local and canonical electronics and the website are not replaced.
    Validate 158 tests and preserve all 340 protected engineering inputs.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
